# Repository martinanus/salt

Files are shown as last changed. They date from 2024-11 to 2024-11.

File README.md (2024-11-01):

# Proyecto SALT 

### Resumen
Este trabajo presenta el diseño e implementación de un prototipo para un sistema de aislado limitado total para formaciones ferroviarias (SAL/T) basado en un pliego de especificaciones de la empresa Trenes Argentinos Operaciones y en una primera versión del prototipo realizado anteriormente en el contexto del Grupo de Investigación en Calidad y Seguridad de las Aplicaciones Ferroviarias (GICSAFe). En esta versión, se agregan nuevas funcionalidades, se actualiza el hardware utilizado y se mejora la portabilidad de su firmware.     

Este sistema permite aumentar la seguridad de los trenes ante una falla en alguno de sus sistemas instrumentados de seguridad interfiriendo las señales de corte de tracción y freno de emergencia de la formación y aislando el subsistema en fallo. El SAL/T considera múltiples fuentes de medición de la velocidad de la formación y la comunicación con una central operativa para determinar cómo debe intervenir estas señales críticas para llevar a la formación a un estado seguro de manera controlada.

### Diagrama en bloques del SAL/T
diagrama_bloque

### Diseño del panel frontal del sistema
panel_frontal

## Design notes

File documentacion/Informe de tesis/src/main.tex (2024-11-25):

\documentclass[11pt,a4paper]{article}

\usepackage{graphicx}
\graphicspath{{Figuras/}}

\usepackage[utf8]{inputenc}
\usepackage[spanish,es-tabla]{babel}
\usepackage[left=2.5cm,right=2.5cm,bottom=2cm,top=2.5cm]{geometry}
\usepackage{titling}
\usepackage{bm}
\usepackage{multirow}
\usepackage{floatrow}
\newfloatcommand{capbtabbox}{table}[][\FBwidth]
\usepackage[table,xcdraw]{xcolor}

\usepackage{blindtext}
\usepackage{verbatim}
\usepackage{amsmath}
\usepackage{amssymb}
\usepackage{textcomp}
\usepackage{bbm}
\usepackage{multicol}
\usepackage{enumitem}
\usepackage{array}
\usepackage{booktabs}
\usepackage{placeins}
\usepackage[hidelinks]{hyperref}

\usepackage[separate-uncertainty = true]{siunitx}
\sisetup{output-decimal-marker = {,}, per-mode=fraction, exponent-product = \cdot}

% Renombre para titulo de referencias / bibliografía
\renewcommand\refname{}

% Bullets para las listas
\renewcommand{\labelitemi}{$\bullet$}
\makeatletter
\def\namedlabel#1#2{\begingroup
    #2%
    \def\@currentlabel{#2}%
    \phantomsection\label{#1}\endgroup}
\makeatother

% Numeración anidada con números
\renewcommand{\labelenumii}{\arabic{enumi}.\arabic{enumii}}
\renewcommand{\labelenumiii}{\arabic{enumi}.\arabic{enumii}.\arabic{enumiii}}
\renewcommand{\labelenumiv}{\arabic{enumi}.\arabic{enumii}.\arabic{enumiii}.\arabic{enumiv}}

\newcommand{\paralelo}{\mathbin{\!/\mkern-5mu/\!}}
\sisetup{exponent-product=\cdot, output-decimal-marker={,}, per-mode=symbol}

\usepackage{fancyhdr}
\usepackage[T1]{fontenc}
\pagestyle{fancy}
\fancyhf{}
\lhead{\textit{Sistema de Aislado Limitado / Total (SAL/T)}}
\rhead{\textit{UBA - Facultad de Ingeniería}}
\cfoot{\thepage}

\setlength{\headheight}{13.6pt}

% Figuras con numeración por sección, subsección o continuo
%\counterwithout{figure}{section}
\counterwithin{figure}{section}
%&\counterwithin{figure}{subsection}

\usepackage{changepage}
%%%%%%%%%%%%%%%%%%%%%%%%%%%%%%%%%%%%%%%%%%%

% Redefino tamaño de título de sección
\usepackage{titlesec}
\usepackage{lmodern}  % Load the Latin Modern font family for better font support
\titleformat{\section}[block]
  {\normalfont\bfseries\fontsize{20}{22}\selectfont} 
  {\thesection}{1em}{}

\titleformat{\subsection}[block]
  {\normalfont\bfseries\fontsize{14}{16}\selectfont}  
  {\thesubsection}{1em}{}

\titleformat{\subsubsection}[block]
  {\normalfont\bfseries\fontsize{12}{14}\selectfont}  
  {\thesubsubsection}{1em}{}

\begin{document}

\pagenumbering{gobble}
\DeclareSIUnit{\div}{div}
\DeclareSIUnit{\Sa}{Sa}

\begin{titlepage}	
	\centering

	%\vspace*{0.3cm}	

%     \Large{\textsc{Universidad de Buenos Aires}}\\ 
%	\Large{\textsc{Facultad de Ingeniería}}\\ 
%	\vspace*{1cm}	

	\begin{figure}[h]
		\centering
		 	
	\end{figure}
	\vspace*{2cm}

\huge{\textsc{86.00 Tesis de Ingeniería Electrónica - Informe de tesis\\}}\vspace{.3cm}
	
	\newcommand{\LargoDeBarra}{1}  % Ajustar
	
	\rule{\LargoDeBarra\linewidth}{0.3 mm} \\[0.1 cm]
	\LARGE{\textbf{Rediseño e implementación de un Sistema de Aislado Limitado / Total (SAL/T) para trenes}} \\[-0.3 cm]
	\rule{\LargoDeBarra\linewidth}{0.3 mm}

\vspace*{2cm}

    \begin{table}[htb]
%    \raggedright

    \begin{tabular}{lcc} 
        \textbf{Autor}              &     &     \\
        Anus, Martín     &    manus@fi.uba.ar & padron n° 101033   \\
        & & \\
         \textbf{Directores de tesis} &         &   \\
         Lutenberg, Ariel       & alutenb@fi.uba.ar & Director  \\
         Gomez, Pablo       & pgomez@fi.uba.ar   & Co-director \\
        Laiuppa, Adrián      & alaiuppa@frbb.utn.edu.ar & Co-director     \\
        & &  \\
         \textbf{Jurados}        & \\
         Cruz, Juan Manuel       & jcruz@fi.uba.ar   & \\
         Germino, Santiago        & sgermino@fi.uba.ar   & \\
         Menéndez, Martín        & mmenendez@fi.uba.ar   & 
        \end{tabular}
     \end{table}

\vspace*{1cm}

\textit{\large{Este trabajo fue realizado en la Ciudad Autónoma de Buenos Aires,}} \\
\textit{\large{entre agosto de 2023 y diciembre de 2024.}}

\end{titlepage}

\newpage
\input{0.1 - Resumen}
\newpage
\input{0.2 - Agradecimientos}

\newpage
\tableofcontents

\newpage
\listoffigures
\listoftables

% -------------------------------------------------------------------------------
\newpage
\setcounter{page}{1}
\pagenumbering{arabic}

\section{Introducción general}
\input{1 - Introducción general/1.0 - intro}
\input{1 - Introducción general/1.1 - Contexto y motivación}
\input{1 - Introducción general/1.2 - Objetivos y alcance}
\input{1 - Introducción general/1.3.1 - Requerimientos}
\input{1 - Introducción general/1.3.2 - Sistemas criticos}

\newpage
\section{Introducción específica}
\input{2 - Introducción específica/2.0 - intro}

\input{2 - Introducción específica/2.1 - intro}
\input{2 - Introducción específica/2.1.1 - Nucleo 144}
\input{2 - Introducción específica/2.1.2 - ESP32}
\input{2 - Introducción específica/2.1.3 - GPS GY-NEO6MV2}
\input{2 - Introducción específica/2.1.4 - SD}
\input{2 - Introducción específica/2.2.1 - MQTT}
\input{2 - Introducción específica/2.2.2 - WIFI}
\input{2 - Introducción específica/2.2.3 - GPS}
\input{2 - Introducción específica/2.2.4 - RS-485}
\input{2 - Introducción específica/2.3 - RTOS}

\newpage
\section{Diseño e implementación}
\input{3 - Diseño e implementación/3.0 - intro}
\input{3 - Diseño e implementación/3.1 - Descripción general de la solución}

\input{3 - Diseño e implementación/3.2.1 - Medición SIS}
\input{3 - Diseño e implementación/3.2.2 - Aislamiento SIS}
\input{3 - Diseño e implementación/3.2.3 - Control de señales críticas}
\input{3 - Diseño e implementación/3.2.4 - Registrador de eventos y conetor de zona}
\input{3 - Diseño e implementación/3.2.5 - Llaves de activación modo aislado limitado y total}
\input{3 - Diseño e implementación/3.2.6 - Lectura de velocidad por RS485}
\input{3 - Diseño e implementación/3.2.7 - Módulo GPS}
\input{3 - Diseño e implementación/3.2.8 - ESP32 y USB}
\input{3 - Diseño e implementación/3.2.9 - Tarjeta SD}
\input{3 - Diseño e implementación/3.2.10 - Nucleo144}
\input{3 - Diseño e implementación/3.2.11 - Panel frontal}
\input{3 - Diseño e implementación/3.2.12 - Fabricación y ensamblado}
\input{3 - Diseño e implementación/3.2.13 - Gabinete}

\input{3 - Diseño e implementación/3.3.1 - Lógica general}
\input{3 - Diseño e implementación/3.3.2 - Mecanismos de RTOS}
\input{3 - Diseño e implementación/3.3.3 - Medición SIS}
\input{3 - Diseño e implementación/3.3.4 - Comunicación GPS}
\input{3 - Diseño e implementación/3.3.5 - Velocidades rs485}
\input{3 - Diseño e implementación/3.3.6 - Comunicacion con centrl operativa}
\input{3 - Diseño e implementación/3.3.7- Lógica de control modo limitado e intermitente}
\input{3 - Diseño e implementación/3.3.8 - Comunicación con controlador LED}
\input{3 - Diseño e implementación/3.3.9 - Registro de eventos}

\newpage
\section{Ensayos y resultados}
\input{4 - Ensayos y resultados/4.0 - intro}
\input{4 - Ensayos y resultados/4.1 - Banco de pruebas}
\input{4 - Ensayos y resultados/4.2 - Pruebas de hardware}
\input{4 - Ensayos y resultados/4.3 - Pruebas de firmware}
\input{4 - Ensayos y resultados/4.4 - Pruebas integrales}

\newpage
\section{Conclusiones}
\input{5 - Conclusiones/5.0 - intro}
\input{5 - Conclusiones/5.1 - Conclusiones generales}
\input{5 - Conclusiones/5.2 - Próximos pasos}

\newpage
\input{6 - Bibliografia}

\end{document}

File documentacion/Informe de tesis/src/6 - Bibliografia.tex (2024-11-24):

\section{Bibliografía}

 \begin{thebibliography}{30}

 \bibitem{gicsafe}
 \textbf{GICSAFe}. Grupo de Investigación en Calidad y Seguridad de las Aplicaciones Ferroviarias. \href{https://sites.google.com/view/conicet-gicsafe}{https://sites.google.com/view/conicet-gicsafe}.

  \bibitem{salt_paper}
 \textbf{Supervision system for emergency brake and traction-system isolation on train formations}. Di Vito Iván Mariano, Gomez Pablo Martin, Lutenberg Ariel, 2020. \href{https://ieeexplore.ieee.org/document/9085280}{\textit{https://ieeexplore.ieee.org/document/9085280}}.

 \bibitem{trenes_arg}
 \textbf{Trenes Argentinos} Trenes Argentinos Operaciones, empresa del estado. \href{https://www.argentina.gob.ar/transporte/trenes-argentinos}{https://www.argentina.gob.ar/transporte/trenes-argentinos}.

\bibitem{salt_ivan}
 \textbf{Aplicación de la técnica de patrones de diseño a la implementación de un Sistema de Aislamiento Limitado/Total ferroviario}. Di Vito, Iván Mariano. 2019 \href{https://bibliotecadigital.fi.uba.ar/items/show/18446}{\textit{https://bibliotecadigital.fi.uba.ar/items/show/18446}}.

\bibitem{norma_50126}
\textbf{UNE-EN 50126-1}. Aplicaciones ferroviarias. Especificación y demostración de la fiabilidad, la disponibilidad, la mantenibilidad y la seguridad (RAMS). 2005. \href{https://www.une.org/encuentra-tu-norma/busca-tu-norma/norma?c=N0033106}{https://www.une.org/encuentra-tu-norma/busca-tu-norma/norma?c=N0033106}

 \bibitem{patrones}
 \textbf{Design Patterns for Safety-Critical Embedded Systems}. Ashraf Armoush. RWTH Aachen University. 2010.

 \bibitem{salt_case}
 \textbf{Sistema de supervisión de la seguridad del material ferroviario utilizando patrones de diseño}. Ivan Mariano Di Vito, Pablo Gomez, Ariel Lutenberg, Adrian Laiuppa. 2019. \href{https://drive.google.com/file/d/1FDtRL4We4daZ7XrJ81sL2f6HrZbYlOuG/view}{\textit{https://drive.google.com/file/d/1FDtRL4We4daZ7XrJ81sL2f6HrZbYlOuG/view}}. 

 \bibitem{spec}
 \textbf{SISTEMA DE AISLADO LIMITADO / TOTAL (SAL-T)}. ESPECIFICACIÓN TÉCNICA. Bypass Sistemas Instrumentados de Seguridad a Bordo del Material Rodante ET.SO. No 046 /18 – E3. 2022.

\bibitem{norma_ipc2221}
\textbf{IPC-2221}. Estándar genérico sobre la PCB. Revisión C; 2023. \href{https://shop.ipc.org/ipc-2221/ipc-2221-standard-only/Revision-c/english}{https://shop.ipc.org/ipc-2221/ipc-2221-standard-only/Revision-c/english}

\bibitem{norma_50128}
\textbf{UNE-EN 50128}. Aplicaciones ferroviarias. Sistemas de comunicación, señalización y procesamiento. Software para sistemas de control y protección del ferrocarril. 2012. \href{https://www.une.org/encuentra-tu-norma/busca-tu-norma/norma?c=N0049040}{https://www.une.org/encuentra-tu-norma/busca-tu-norma/norma?c=N0049040} 

\bibitem{norma_61508}
\textbf{UNE-EN 61508-4}. Seguridad funcional de los sistemas eléctricos/electrónicos/electrónicos programables relacionados con la seguridad. Parte 4: Definiciones y abreviaturas. 2011. \href{https://www.une.org/encuentra-tu-norma/busca-tu-norma/norma?c=N0047025}{https://www.une.org/encuentra-tu-norma/busca-tu-norma/norma?c=N0047025} 

\bibitem{norma_50129}
\textbf{UNE-EN 50129}. Aplicaciones ferroviarias. Sistemas de comunicación, señalización y procesamiento. Sistemas electrónicos relacionados con la seguridad para la señalización. 2020. \href{https://www.une.org/encuentra-tu-norma/busca-tu-norma/norma?c=N0063513}{https://www.une.org/encuentra-tu-norma/busca-tu-norma/norma?c=N0063513} 

\bibitem{clasificacion_fallas}
\textbf{Random, systematic, and common cause failure: How do you manage them?}. Michela Gentile, Angela E. Summers. 2006. \href{https://sis-tech.com/wp-content/uploads/2005/10/Random_Systematic_and_Common_Cause_Failure.pdf}{https://sis-tech.com/wp-content/uploads/2005/10/Random\_Systematic\_and\_Common\_Cause\_Failure.pdf} 

 \bibitem{nucleo144}
\textbf{STM32 Nucleo-144 development board with STM32F429ZI MCU}. STMicroelectronics. \href{https://www.st.com/en/evaluation-tools/nucleo-f429zi.html}{https://www.st.com/en/evaluation-tools/nucleo-f429zi.html} 

\bibitem{stm32f429zi}
\textbf{STM32F429ZI}. High-performance advanced line, Arm Cortex-M4 core. STMicroelectronics. \href{https://www.st.com/en/microcontrollers-microprocessors/stm32f429zi.html}{https://www.st.com/en/microcontrollers-microprocessors/stm32f429zi.html} 

\bibitem{st_link}
\textbf{ST-LINK/V2-1}. In-Circuit Debugger and Programmer. STMicroelectronics.
\href{https://www.st.com/en/development-tools/st-link-v2.html}{https://www.st.com/en/development-tools/st-link-v2.html}

\bibitem{stCubeIde}
\textbf{STM32CubeIDE}. Free Development Environment for STM32 Microcontrollers. STMicroelectronics.
\href{https://www.st.com/en/development-tools/stm32cubeide.html}{https://www.st.com/en/development-tools/stm32cubeide.html}

\bibitem{stCubeMx}
\textbf{STM32CubeMX}. Initialization Code Generator for STM32 Microcontrollers. STMicroelectronics.
\href{https://www.st.com/en/development-tools/stm32cubemx.html}{https://www.st.com/en/development-tools/stm32cubemx.html}

\bibitem{esp32}
\textbf{ESP32-DevKitC}. Development board from Espressif.  \href{https://docs.espressif.com/projects/esp-dev-kits/en/latest/esp32/esp32-devkitc/index.html}{https://docs.espressif.com/projects/esp-dev-kits/en/latest/esp32/esp32-devkitc/index.html} 

\bibitem{ieee_802.11}
\textbf{IEEE 802.11}. IEEE Computer Society, IEEE Standard for Information Technology—Telecommunications and Information Exchange Between Systems Local and Metropolitan Area Networks—Specific Requirements Part 11: Wireless LAN Medium Access Control (MAC) and Physical Layer (PHY) Specifications, IEEE Standard 802.11-2020, 2021. \href{https://standards.ieee.org/standard/802_11-2020.html}{https://standards.ieee.org/standard/802\_11-2020.html}

\bibitem{bluetooth}
\textbf{Bluetooth}. Bluetooth Core Specification Version 5.4. 2023. \href{https://www.bluetooth.com/specifications/bluetooth-core-specification/}{https://www.bluetooth.com/specifications/bluetooth-core-specification/}

\bibitem{arduino_ide}
\textbf{Arduino IDE}. Open source repository.  \href{https://github.com/arduino/arduino-ide}{https://github.com/arduino/arduino-ide}

\bibitem{esp_ids}
\textbf{ESP-IDS}. Espressif IoT Development Framework.\href{https://idf.espressif.com/}{https://idf.espressif.com/}

\bibitem{platformio}
\textbf{PlatformIO}. Cross-platform, cross-architecture, multiple framework, professional tool for embedded systems designers. \href{https://platformio.org/}{https://platformio.org/}

\bibitem{gy-neo6}
\textbf{Modulo GPS GY-NEO6MV2}. Módulo basado en NEO-6M. \href{https://www.todomicro.com.ar/ARDUINO/339-modulo-gps-gy-neo6mv2-con-antena.html}{https://www.todomicro.com.ar/ARDUINO/339-modulo-gps-gy-neo6mv2-con-antena.html}

\bibitem{neo6}
\textbf{NEO-6M}. Módulo GNSS / GPS. Ublox. \href{https://www.u-blox.com/en/product/neo-6-series}{https://www.u-blox.com/en/product/neo-6-series}

\bibitem{mqtt_ibm}
\textbf{Getting to know MQTT}. Michael Yuan. 2021. \href{https://developer.ibm.com/articles/iot-mqtt-why-good-for-iot/}{https://developer.ibm.com/articles/iot-mqtt-why-good-for-iot/}

\bibitem{mqtt_img}
\textbf{What is MQTT}. Tobias Goebel
Twilion. 2023. \href{https://www.twilio.com/en-us/blog/what-is-mqtt}{https://www.twilio.com/en-us/blog/what-is-mqtt}

\bibitem{wifi_img}
\textbf{Wi-Fi Direct}. Wikipedia. \href{https://en.wikipedia.org/wiki/Wi-Fi_Direct}{https://en.wikipedia.org/wiki/Wi-Fi\_Direct}

\bibitem{wifi_security}
\textbf{Wi-Fi Security}. Wi-Fi Alliance, Wi-Fi Security Technologies: WEP, WPA, and WPA2. \href{https://www.wi-fi.org/discover-wi-fi/security}{https://www.wi-fi.org/discover-wi-fi/security}

\bibitem{gps}
\textbf{GPS}. U.S. Department of Defense, Global Positioning System Standard Positioning Service Performance Standard, 4th ed. 2008. \href{https://www.gps.gov/technical/ps/}{https://www.gps.gov/technical/ps/}

\bibitem{gps_img}
\textbf{Cómo funcionan los dispositivos GPS? Trilateración vs Triangulación}.Gabri. Arcgeek. 2018.  \href{https://acolita.com/como-funcionan-los-dispositivos-gps-trilateracion-vs-triangulacion/}{https://acolita.com/como-funcionan-los-dispositivos-gps-trilateracion-vs-triangulacion/}

\bibitem{rs485}
\textbf{Texas Instruments, RS-485}: Theory and Application, Application Report SLAA070D. 2004. \href{https://www.ti.com/lit/an/slaa070d/slaa070d.pdf}{https://www.ti.com/lit/an/slaa070d/slaa070d.pdf}

\bibitem{rtos}
\textbf{What is a Real-Time Operating System (RTOS)?} Digikey article. 2021. \href{https://www.digikey.com/en/maker/projects/what-is-a-realtime-operating-system-rtos/28d8087f53844decafa5000d89608016}{https://www.digikey.com/en/maker/projects/what-is-a-realtime-operating-system-rtos/28d8087f53844decafa5000d89608016}

\bibitem{hasler}
\textbf{Hasler Rail}. Speed Sensing and Odometry. 2016
\href{https://www.haslerrail.com/wp-content/uploads/2019/03/HaslerRail_DataRecordingSafety_EN_v1.pdf}{https://www.haslerrail.com/wp-content/uploads/2019/03/HaslerRail\_DataRecordingSafety\_EN\_v1.pdf}

\bibitem{mouser}
\textbf{Mouser Electronics}.  Global distributor of semiconductors and electronic components. \href{https://www.mouser.com/}{https://www.mouser.com/}

\bibitem{digikey}
\textbf{DigiKey Corporation}. Global distributor of semiconductors and electronic components. \href{https://www.digikey.com/}{https://www.digikey.com/}

\bibitem{kicad}
\textbf{KiCad EDA}. Version 6. KiCad Developers.
\href{https://www.kicad.org/}{https://www.kicad.org/}

\bibitem{LTspice}
\textbf{LTSpice.} Free SPICE simulator. Analog devices.
\href{https://www.analog.com/en/resources/design-tools-and-calculators/ltspice-simulator.html}{https://www.analog.com/en/resources/design-tools-and-calculators/ltspice-simulator.html}

\bibitem{github}
\textbf{GitHub, Inc.}. A Platform for Version Control and Collaboration,
\href{https://github.com}{https://github.com}

\bibitem{git}
\textbf{Git} A Distributed Version Control System. Linus Torvalds. 2005.
\href{https://git-scm.com}{https://git-scm.com}

\bibitem{repo}
\textbf{martinanus/salt} Repositorio de firmware y hardware del proyecto. Martín Anús. 2024. \href{https://github.com/martinanus/salt}{https://github.com/martinanus/salt}

\bibitem{INA823DGKR}
\textbf{INA823DGKR}. Texas Instruments. Instrumentation Amplifiers Precision. 
\href{https://www.ti.com/lit/gpn/ina823}{https://www.ti.com/lit/gpn/ina823}

\bibitem{ICL7660AIBAZA}
\textbf{ICL7660AIBAZA}. Renesas. Switching Voltage Regulators. 
\href{https://ar.mouser.com/datasheet/2/698/REN_icl7660s_a_DST_20200210-1997724.pdf}{https://ar.mouser.com/datasheet/2/698/REN\_icl7660s\_a\_DST\_20200210-1997724.pdf}

\bibitem{JW2SN-DC5V}
\textbf{JW2SN-DC5V}. Panasonic Industrial Devices. General Purpose Relays 5A 5VDC DPDT SEALED PCB. 
\href{https://ar.mouser.com/manufacturer/panasonic-industrial-devices/}{https://ar.mouser.com/manufacturer/panasonic-industrial-devices/}

\bibitem{V23047A1005A501}
\textbf{V23047A1005A501}. TE Connectivity. Safety Relays 2 CO CONTACTS 5VDC
\href{https://ar.mouser.com/datasheet/2/418/6/ENG_DS_SR2M_0820-735797.pdf}{https://ar.mouser.com/datasheet/2/418/6/ENG\_DS\_SR2M\_0820-735797.pdf}

\bibitem{norma_61810}
\textbf{UNE-EN 61810-3}. Relés electromecánicos elementales. Parte 3: Relés con contactos guiados (unidos mecánicamente). 2015. 
\href{https://www.une.org/encuentra-tu-norma/busca-tu-norma/norma?c=N0054926}{https://www.une.org/encuentra-tu-norma/busca-tu-norma/norma?c=N0054926}

\bibitem{rele_img}
\textbf{Relay Terminology}. Altech Corp.
\href{https://oylair.com/wp-content/uploads/2021/03/resources-library-3-relay-terminology.pdf}{https://oylair.com/wp-content/uploads/2021/03/resources-library-3-relay-terminology.pdf}

\bibitem{ULN2003D1013TR}
\textbf{ULN2003D1013TR}- STMicroelectronics. Darlington Transistors Seven NPN Array.
\href{https://ar.mouser.com/datasheet/2/389/uln2001-1852702.pdf}{https://ar.mouser.com/datasheet/2/389/uln2001-1852702.pdf}

\bibitem{darlington}
\textbf{Darlington’s Contributions to Transistor Circuit Design} David A. Hodges, Fellow, IEEE. 1999.
\href{https://people.eecs.berkeley.edu/~hodges/DarlingtonCircuit.pdf}{https://people.eecs.berkeley.edu/~hodges/DarlingtonCircuit.pdf}

\bibitem{registrador_eventos}
\textbf{Use of Event Data Recorders in Rail Transit}. Federal Transit Administration, , FTA Report No. 0123. 2015.
\href{https://www.transit.dot.gov/research-innovation/use-event-data-recorders-rail-transit}{https://www.transit.dot.gov/research-innovation/use-event-data-recorders-rail-transit}

\bibitem{llave_elibet}
\textbf{Interruptor Bipolar 20A de 2 posiciones}. Elibet. Serie LI. 
\href{https://www.elibet.com/wp-content/uploads/2014/08/Elibet-20A.pdf}{https://www.elibet.com/wp-content/uploads/2014/08/Elibet-20A.pdf}

\bibitem{indicador_velocidad}
\textbf{Data Recording and Safety}. Hasler Rail. \href{http://www.iotrains.com/fileadmin/user_upload/04_DataRecording.pdf}{http://www.iotrains.com/fileadmin/ user\_upload/04\_DataRecording.pdf}

\bibitem{crc}
\textbf{Catalogue of parametrised CRC algorithms with 16 bits}. Greg Cook. 
\href{http://reveng.sourceforge.net/crc-catalogue/16.htm}{http://reveng.sourceforge.net/crc-catalogue/16.htm}

\bibitem{edu-ciaa}
\textbf{EDU-CIAA-NXP}. Información general de la placa de desarrollo EDU-CIAA-NXP desarrollada por el proyecto CIAA (Computadora Industrial Abierta Argentina). \href{https://www.proyecto-ciaa.com.ar/devwiki/doku.php%3Fid=desarrollo:edu-ciaa:edu-ciaa-nxp.html}{https://www.proyecto-ciaa.com.ar/devwiki/doku.php\%3Fid=desarrollo:edu-ciaa:edu-ciaa-nxp.html}

\bibitem{SN65HVD1176DR}
\textbf{SN65HVD1176DR}. Texas Instruments. CI interfaz RS-485 PROFIBUS RS-485 Transceiver. 
\href{https://www.ti.com/lit/gpn/sn65hvd1176}{https://www.ti.com/lit/gpn/sn65hvd1176}

\bibitem{profibus}
\textbf{Profibus International}. PROFIBUS Technology Overview.
\href{https://www.profibus.com/technologies/profibus}{https://www.profibus.com/technologies/profibus}

\bibitem{SZP6SMB12CAT3G}
\textbf{SZP6SMB12CAT3G}. Littelfuse. ESD Protection Diodes / TVS Diodes.
\href{https://www.littelfuse.com/media?itemid=a54ab340-efe4-40d7-99cb-dd80d69f6f3a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}{https://www.littelfuse.com/media?resourcetype=datasheets\&itemid=a54ab340-efe4-40d7-99cb-dd80d69f6f3a\&filename=littelfuse\_tvs\_diode\_szp6smb\_datasheet.pdf}

\bibitem{MF-USMF020-2}
\textbf{MF-USMF020-2}. Bourns. Resettable Fuses.
\href{https://www.mouser.co.uk/datasheet/2/54/mfusmf-777646.pdf}{https://www.mouser.co.uk/datasheet/2/54/mfusmf-777646.pdf}

\bibitem{SI2343DS-T1-E3}
\textbf{SI2343DS-T1-E3}. Vishay Semiconductors. MOSFETs 30V 4.0A 1.25W 53 mohms @ 10V. 
\href{https://www.vishay.com/doc?72079}{https://www.vishay.com/doc?72079}

\bibitem{altanet}
\textbf{Módem router Portátil USB 4G LTE Wi-Fi}. Altanet.
\href{https://www.voipexperts.com.ar/productos/routers/routers-4g/alta-stick-st10.html}{https://www.voipexperts.com.ar/productos/routers/routers-4g/alta-stick-st10.html}

\bibitem{87583-2010BLF}
\textbf{87583-2010BLF}. Amphenol FCI. USB Connectors 4P RECEPTACLE TYPE A.
\href{https://www.mouser.co.uk/datasheet/2/18/1/87583-2579162.pdf}{https://www.mouser.co.uk/datasheet/2/18/1/87583-2579162.pdf}

\bibitem{DM3AT-SF-PEJM5}
\textbf{DM3AT-SF-PEJM5}. Hirose Connector. Memory Card Connectors R/A SMT MICROSD CON PUSH-PUSH.
\href{https://www.mouser.co.uk/datasheet/2/185/DM3AT_SF_PEJM5_CL0609_0031_0_00_2DDrawing_00009471-1614303.pdf}{https://www.mouser.co.uk/datasheet/2/185/ DM3AT\_SF\_PEJM5\_CL0609\_0031\_0\_00\_2DDrawing\_00009471-1614303.pdf}

\bibitem{sd_sandisk}
\textbf{Micro SD Ultra 8GB Class 10}. SanDisk.
\href{https://dcpsoltec.mercadoshops.com.ar/MLA-1346308183-micro-sd-sandisk-ultra-8gb-clase-10-_JM}{https://dcpsoltec.mercadoshops.com.ar/MLA-1346308183-micro-sd-sandisk-ultra-8gb-clase-10-\_JM}

\bibitem{AS1115-BSST}
\textbf{AS1115-BSST}. ams OSRAM. LED Display Drivers LED Driver with Keyscan.
\href{https://www.mouser.co.uk/datasheet/2/588/asset_pdf_25493045-3432722.pdf}{https://www.mouser.co.uk/datasheet/2/588/asset\_pdf\_25493045-3432722.pdf}

\bibitem{WP154A4SEJ3VBDZGW/CA}
\textbf{WP154A4SEJ3VBDZGW/CA}. Kingbright. Standard LEDs - Through Hole 5MM RGB LED.
\href{https://www.mouser.co.uk/datasheet/2/216/WP154A4SEJ3VBDZGW_CA-1145236.pdf}{https://www.mouser.co.uk/datasheet/2/216/WP154A4SEJ3VBDZGW\_CA-1145236.pdf}

\bibitem{WP7113LZGCK}
\textbf{WP7113LZGCK}. Kingbright. Standard LEDs - Through Hole 5MM LOW CURRENT GREEN LED.
\href{https://www.mouser.co.uk/datasheet/2/216/WP7113LZGCK-535810.pdf}{https://www.mouser.co.uk/datasheet/2/216/WP7113LZGCK-535810.pdf}

\bibitem{LTC-5723HR}
\textbf{LTC-5723HR}. Lite-On. LED Displays and Accessories 4 Digit, Red. 
\href{https://www.mouser.co.uk/datasheet/2/239/C5723HR-1141844.pdf}{https://www.mouser.co.uk/datasheet/2/239/C5723HR-1141844.pdf}

\bibitem{1543-650-149}
\textbf{1543-650-149}. Bourns. Pushbutton Switches Push Switch.
\href{https://www.mouser.co.uk/datasheet/2/54/1543-55078.pdf}{https://www.mouser.co.uk/datasheet/2/54/1543-55078.pdf}

\bibitem{CEM-1205-IC}
\textbf{CEM-1205-IC}. Same Sky.Piezo Buzzers and Audio Indicators buzzer 5V, driving circuit.
\href{https://www.mouser.co.uk/datasheet/2/1628/cem_1205_ic-3509057.pdf}{https://www.mouser.co.uk/datasheet/2/1628/cem\_1205\_ic-3509057.pdf}

\bibitem{NVTR0202PLT1G}
\textbf{NVTR0202PLT1G}. onsemi. MOSFETs PFET 20V 0.4A 80MOH.
\href{https://www.mouser.co.uk/datasheet/2/308/1/NTR0202PL_D-2319410.pdf}{https://www.mouser.co.uk/datasheet/2/308/1/NTR0202PL\_D-2319410.pdf}

\bibitem{jlcway}
\textbf{JLCWAY}.PCB Manufacturing and Assembly Services.
\href{https://jlcpcb.com}{https://jlcpcb.com}

\bibitem{labi_3d}
\textbf{Impresiones 3D}. Laboratorio Abierto de la Facultad de Ingeniería de la Universidad de Buenos Aires.
\href{https://labi.fi.uba.ar/impresiones-3d}{https://labi.fi.uba.ar/impresiones-3d}

\bibitem{gabinete}
\textbf{Caja estanca plástica 310x310x110 Blanca IP65}. Sistelectric de Genros.
\href{https://sistelectric.com/producto/06313111g/caja-estanca-plastica-310x310x110-gris-ip65/}{https://sistelectric.com/producto/06313111g/caja-estanca-plastica-310x310x110-gris-ip65/}

\bibitem{freertos}
\textbf{FreeRTOS}. Real-Time Operating System for Embedded Devices.
\href{https://www.freertos.org}{https://www.freertos.org}

\bibitem{nmea}
\textbf{GPS - NMEA sentence information}. Glenn Baddeley. 2001.
\href{https://aprs.gids.nl/nmea/}{https://aprs.gids.nl/nmea/}

\bibitem{ntp}
\textbf{NTP Server} The NTP Pool Project
\href{https://www.pool.ntp.org}{https://www.pool.ntp.org}

\bibitem{arduino_uno}
\textbf{Arduino}. Arduino Uno Rev3.
\href{https://docs.arduino.cc/hardware/uno-rev3/}{https://docs.arduino.cc/hardware/uno-rev3/}

\bibitem{conversor_rs485}
\textbf{Modulo Conversor Rs485 Ttl Max485 Transceiver}. Hobbytronica. 
\href{https://www.hobbytronica.com.ar/MLA-1412581125-x5-modulo-conversor-rs485-ttl-max485-transceiver-arduino-_JM}{https://www.hobbytronica.com.ar/MLA-1412581125-x5-modulo-conversor-rs485-ttl-max485-transceiver-arduino-\_JM}

\bibitem{atmega328}
\textbf{ATMega328-p}. 8-bit AVR Microcontroller. Microchip Technology Inc. 
\href{https://www.microchip.com/wwwproducts/en/ATmega328p}{https://www.microchip.com/wwwproducts/en/ATmega328p}

\bibitem{swSerial}
\textbf{Software Serial Library}. Arduino. 
\href{https://docs.arduino.cc/learn/built-in-libraries/software-serial/}{https://docs.arduino.cc/learn/built-in-libraries/software-serial/}

\bibitem{hobbytronica}
\textbf{Hobbytrónica}. Casa de electrónica y robótica. 
\href{https://docs.arduino.cc/learn/built-in-libraries/software-serial/}{https://www.hobbytronica.com.ar/}

\bibitem{max485}
\textbf{MAX485}. Low-Power, Slew-Rate-Limited RS-485/RS-422 Transceivers. Analog devices.
\href{https://www.analog.com/en/products/max485.html}{https://www.analog.com/en/products/max485.html}

\bibitem{shifrio}
\textbf{shiftr.io}. MQTT Broker and Dataflow Visualizer
\href{https://www.shiftr.io}{https://www.shiftr.io}

\bibitem{paho}
\textbf{Paho MQTT Python Client Library}. Eclipse Foundation. 
\href{https://eclipse.dev/paho/}{https://eclipse.dev/paho/}

\bibitem{modulo_sd}
\textbf{Modulo lector de tarjetas SD}. Electrouno. 
\href{https://www.unoelectro.com.ar/MLA-864661170-modulo-lector-de-tarjetas-micro-sd-arduino-unoelectro-_JM}{https://www.unoelectro.com.ar/MLA-864661170-modulo-lector-de-tarjetas-micro-sd-arduino-unoelectro-\_JM}

 \end{thebibliography}

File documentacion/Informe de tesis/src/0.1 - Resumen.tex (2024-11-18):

\vspace*{\fill}

\begin{center}

{\huge \textit{Resumen}}

\vspace{1.5cm}

\begin{adjustwidth}{2cm}{2cm}
\begin{center}

Este trabajo presenta el diseño e implementación de un prototipo para un sistema de aislado limitado total para formaciones ferroviarias (SAL/T) basado en un pliego de especificaciones de la empresa Trenes Argentinos Operaciones y en una primera versión del prototipo realizado anteriormente en el contexto del Grupo de Investigación en Calidad y Seguridad de las Aplicaciones Ferroviarias (GICSAFe). En esta versión, se agregan nuevas funcionalidades, se actualiza el hardware utilizado y se mejora la portabilidad de su firmware. \\

\vspace{.8cm}

Este sistema permite aumentar la seguridad de los trenes ante una falla en alguno de sus sistemas instrumentados de seguridad interfiriendo las señales de corte de tracción y freno de emergencia de la formación y aislando el subsistema en fallo. El SAL/T considera múltiples fuentes de medición de la velocidad de la formación y la comunicación con una central operativa para determinar cómo debe intervenir estas señales críticas para llevar a la formación a un estado seguro de manera controlada.  \\ 

\vspace{.8cm}

A lo largo del proyecto, se aplicaron conocimientos de diseño de circuitos, diseño de placas impresas, utilización de protocolos de comunicación e implementación de firmware basado en sistemas operativos en tiempo real.

\end{center}
\end{adjustwidth}

\end{center}

\vspace{8cm}

\vspace*{\fill}

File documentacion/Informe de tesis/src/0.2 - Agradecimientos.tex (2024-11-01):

\vspace*{\fill}

\begin{center}

{\huge \textit{Agradecimientos}}

\vspace{1.3cm}

\begin{adjustwidth}{2cm}{2cm}
\begin{center}
        
Quiero expresar mi agradecimiento a los directores de esta tesis; Ariel, Pablo y Adrián por su constante apoyo, motivación, ayuda y guía que me brindaron a lo largo de este proyecto. \\ 
\vspace{.7cm}

Al grupo de investigación GICSAFe que me introdujo en el mundo de los sistemas ferroviarios y me abrió la posibilidad de desarrollar este trabajo sobre las sólidas bases de conocimiento del grupo.

\vspace{.7cm}

A las personas de la empresa Trenes Argentinos que dedicaron su tiempo para definir el objetivo y el alcance de este proyecto. 

\vspace{.7cm}

Al ingeniero Iván Di Vito por dejar una versión anterior de este sistema de una calidad enorme.

\vspace{.7cm}

A todos los docentes que tuve a lo largo de mi vida por formarme como profesional y como persona. 

\vspace{.7cm}

Al arquitecto Martín Mendilaharzu por la ayuda en el diseño y fabricación del gabinete. 

\vspace{.7cm}

A Carlos, mi papá, por mostrarme la ingeniería en todos los detalles de la vida y contagiarme su pasión.

\vspace{.7cm}

A Sandra, mi mamá, por su amor incondicional e infinito.

\vspace{.7cm}

A Federico, mi hermano, por su complicidad y acompañamiento en este camino.

\vspace{.7cm}

Y por último, pero no menor, agradecerle a todos mis amigos; por estar siempre presentes a mi lado y darle sentido a todo. 

\end{center}
\end{adjustwidth}

\end{center}

\vspace{2.8cm}

\vspace*{\fill}

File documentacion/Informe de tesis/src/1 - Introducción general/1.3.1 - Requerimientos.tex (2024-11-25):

\subsection{Requerimientos y visión general}

\subsubsection{Requerimientos}

A continuación, se muestran los requerimientos acordados para el proyecto contemplando la versión anterior del SAL/T y el pliego de especificaciones técnicas generado por Trenes Argentinos como referencia. 

\begin{enumerate}
    \item Grupo de requerimientos asociados con la interfaz humano-máquina
    \begin{enumerate}
        \item La interfaz debe contar con una llave rotativa para activar el modo aislado limitado.
        \item La interfaz debe mostrar la velocidad media del equipo en km/h con 4 dígitos.
        \item La interfaz debe indicar el estado de la señal de corte de tracción.
        \item La interfaz debe indicar el estado de la señal de freno de emergencia.
        \item La interfaz debe indicar la presencia de un comando remoto de la central operativa.
        \item La interfaz debe indicar el estado del módulo GPS.
        \item La interfaz debe indicar el estado de la alimentación.
        \item La interfaz debe indicar el modo en el que se encuentra el sistema.
        \item La interfaz debe contener un control local por fuera del panel frontal para activar el modo aislado total.
        \item La interfaz debe indicar con un LED RGB en cuál de las 3 zonas geográficas predefinidas se encuentra el material rodante. 
        \item La interfaz debe indicar el estado de los distintos Sistemas Instrumentados de Seguridad conectados al SAL/T con un LED RGB para cada SIS.
        \item La interfaz debe contar con una botonera o switch que permita cambiar el perfil para modo de tracción intermitente.
        \item La interfaz debe indicar el perfil seleccionado para modo de tracción intermitente.
        \item La interfaz debe contener un buzzer interno para indicaciones sonoras.
    \end{enumerate}
       
    \item Grupo de requerimientos asociados a la comunicación con el registrador de eventos
    \begin{enumerate}
        \item El sistema debe informar al registrador de eventos la activación del modo aislado limitado.
        \item El sistema debe informar al registrador de eventos si la alimentación es correcta.
        \item El sistema debe informar al registrador de eventos la activación del freno de emergencia.
        \item El sistema debe informar al registrador de eventos la activación del corte de tracción.
    \end{enumerate}
       
    \item Grupo de requerimientos asociados al registro de datos
    \begin{enumerate}
        \item El sistema debe mantener un registro de datos local donde se registran los siguientes eventos con marca de tiempo:
        \begin{itemize}
            \item Activación/Desactivación del modo aislado limitado
            \item Activación/Desactivación del modo aislado total (local o remota)
            \item Referencia de velocidad adoptada y sus permutaciones 
            \item Cobertura de señal GPS
            \item Ciclos de permiso, corte y freno en modo de tracción intermitente
            \item SIS en fallo
            \item Velocidad desarrollada
            \item Zona de circulación
        \end{itemize}
        \item El sistema debe permitir descargar los datos registrados mediante una interfaz serie.
        \item El sistema debe poder descargar los datos registrados de manera remota.
    \end{enumerate}
       
    \item Grupo de requerimientos asociados a la comunicación con la central operativa
    \begin{enumerate}
        \item El sistema debe informar periódicamente (con un tiempo configurable) su estado a la central operativa a través de la red de datos Wi-Fi.
        \item Debe existir la posibilidad de usar 2 proveedores distintos de datos de manera simultánea.
        \item Debe existir la posibilidad de conectarse alternadamente a más de una red Wi-Fi.
        \item El protocolo de comunicación con la central operativa debe ser MQTT.
        \item El sistema debe ser capaz de recibir un comando remoto que anule el corte de tracción y el freno de emergencia bajo cualquier condición (modo aislado total).
        \item El sistema debe ser capaz de recibir un comando remoto que active el corte de tracción y el freno de emergencia bajo cualquier condición (modo parada total).
        \item El sistema debe ser capaz de recibir un comando remoto que active el corte de tracción y anule el freno de emergencia bajo cualquier condición (modo coche en deriva).
        \item El sistema debe ser capaz de recibir un comando remoto que active el corte de tracción y el freno de emergencia de forma intermitente en ciclos de tiempo configurables (modo intermitente).
        \item El sistema debe ser capaz de recibir un comando remoto que cancele cualquier comando remoto vigente.
        \item El sistema debe ser capaz de recibir comandos remotos que modifiquen sus parámetros internos configurables.
        \item Si no se recibe un nuevo comando remoto luego de un tiempo configurable (por defecto 10 segundos, máximo 1 minuto), debe volver al algoritmo de activación de corte de tracción y freno de emergencia por defecto.
        \item Ante un comando remoto recibido, debe enviar una confirmación de recepción que permita a la central operativa decidir si es necesaria o no una retransmisión.
        \item Debe utilizar algún mecanismo de encriptación para el enlace con la central operativa.
    \end{enumerate}
       
    \item Grupo de requerimientos asociados al modo normal de funcionamiento
    \begin{enumerate}
        \item El modo normal el sistema no debe intervenir en el funcionamiento del material rodante (prioridad alta).
        \item El sistema debe obtener en todo momento la mejor estimación posible de la velocidad de la formación.
        \item Debe ser capaz de recibir la velocidad a partir de una señal digital provista por el registrador de eventos Hasler Teloc 1500.
        \item Debe ser capaz de calcular la velocidad a partir de un sistema GPS integrado.
        \item Debe ser capaz de calcular la velocidad a partir de un generador de impulsos.
        \item El rango de velocidad soportado por el sistema tiene que estar entre 0 y 120 km/h.
        \item La estimación de velocidad debe tener una precisión del 2 \% de fondo de escala.
        \item El sistema debe determinar la posición del material rodante para activar un contacto seco de relé según la zona de operación donde se encuentre.
    \end{enumerate}
    \vspace{1cm}
    \item Grupo de requerimientos asociados al modo aislado limitado
    \begin{enumerate}
        \item En modo aislado limitado el sistema debe evitar la aplicación del corte de tracción.
        \item En modo aislado limitado el sistema debe evitar la aplicación del freno de emergencia.
        \item Ante cualquier error interno, el sistema debe dejar de intervenir en la aplicación del corte de tracción.
        \item Ante cualquier error interno, el sistema debe dejar de intervenir en la aplicación del freno de emergencia.
        \item En modo aislado limitado el sistema debe emitir una señal sonora intermitente a través de un buzzer.
        \item En modo aislado limitado el sistema debe evitar que la velocidad del material rodante supere una serie de límites configurados.
        \begin{enumerate}
            \item Si al pasar de modo normal a modo aislado limitado no se cuenta con una estimación de velocidad, debe activar el corte de tracción y el freno de emergencia por 30 segundos.
            \item Si se supera una velocidad configurable (por defecto 30 km/h), debe activar el corte de tracción y emitir una señal sonora continua a través de un buzzer.
            \item Si se supera una velocidad configurable (por defecto 36 km/h), debe activar el freno de emergencia.
            \item Una vez aplicado, el corte de tracción debe dejar de aplicarse si la velocidad vuelve a ser menor a una velocidad configurable (por defecto 25 km/h).
            \item Una vez aplicado, el freno de emergencia sólo debe dejar de aplicarse luego de un tiempo configurable (por defecto 30 segundos) desde que se superó el límite.
            \item Si la lectura de velocidad es inválida, debe activar y desactivar el corte de tracción y freno de emergencia de manera alternada en ciclos de tiempo según perfiles preconfigurados (modo de tracción intermitente).
        \end{enumerate}
        \item El sistema debe interactuar con 5 Sistemas Instrumentados de Seguridad.
        \item El sistema debe ser capaz de identificar qué SIS está fallando y aislar solamente este dejando los demás SIS operativos.
        \item El sistema debe medir la posición del material rodante para modificar las velocidades máximas según la zona de operación donde se encuentre.
    \end{enumerate}
       
    \item Grupo de requerimientos asociados al modo aislado total
    \begin{enumerate}
        \item El sistema solo puede acceder a este modo accionando el control local o mediante comando remoto.
        \item En el modo aislado total el sistema debe liberar la velocidad de circulación.
        \item El sistema debe registrar en el registro de datos la activación de este modo.
    \end{enumerate}
       
    \item Grupo de requerimientos asociados al modo de tracción intermitente
    \begin{enumerate}
        \item El sistema solo deberá acceder a este modo cuando se encuentre en modo aislado limitado y no cuente con ninguna medición de velocidad válida o se seleccione de manera remota.
        \item El sistema debe permitir la configuración remota de distintos perfiles de operación de manera remota en donde se configuran los valores de Tiempo del permiso de Tracción, Tiempo de ciclo en deriva, Cantidad de ciclos antes de aplicar freno y Tiempo de espera antes de comienzo de nuevo ciclo.
    \end{enumerate}
       \vspace{1cm}
    \item Grupo de requerimientos asociados al hardware y al gabinete
    \begin{enumerate}
        \item El sistema utilizará una fuente externa de 5 V de tensión continua que pueda soportar hasta 25W de potencia.
        \item Los conectores deben estar bien identificados para facilitar la correcta conexión.
        \item El sistema debe poseer una placa de circuito impreso con el procesador y periféricos necesarios para el procesamiento de las señales del material rodante y una segunda placa para los elementos necesarios para la interacción con el conductor.
        \item El diseño de la placa de circuito impreso debe contemplar las recomendaciones de la norma IPC 2221 \cite{norma_ipc2221} a fines de asegurar la manufacturabilidad del equipo. 
    \end{enumerate}
           
    \item Grupo de requerimientos asociados al desarrollo del firmware
    \begin{enumerate}
        \item El desarrollo del software debe contemplar las recomendaciones de las normas UNE-EN 50126 y UNE-EN 50128 \cite{norma_50128}.
        \item El sistema debe trabajar con un sistema operativo en tiempo real para mejorar el desempeño y la seguridad del equipo.
    \end{enumerate}
\end{enumerate}

Estos requerimientos permiten definir de manera clara las funcionalidades, comportamientos y especificaciones de diseño del sistema. Es fundamental tener bien definidos los requerimientos en las primeras etapas del proyecto y acordarlos con todos los actores involucrados hasta obtener una versión definitiva. Cualquier modificación realizada en fases más avanzadas puede provocar un gran desvío en la planificación y generar un esfuerzo considerable de cambio.

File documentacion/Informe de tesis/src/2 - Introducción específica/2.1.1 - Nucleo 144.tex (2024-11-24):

\subsubsection{STM32 Nucleo-144}

La STM32 Nucleo-144 es una familia de placas de desarrollo basada en los microcontroladores STM32 de la familia ARM Cortex-M, diseñada para facilitar la creación de prototipos y el desarrollo de sistemas embebidos \cite{nucleo144}. Esta familia de placas es parte de la serie Nucleo de STMicroelectronics, conocida por ofrecer soluciones flexibles y accesibles para una amplia gama de aplicaciones, desde dispositivos IoT (\textit{Internet of Things}) hasta sistemas críticos. En la figura \ref{fig:nucleo144} se puede visualizar la placa de desarrollo NUCLEO F429ZI de la familia STM32 Nucleo-144 que se utiliza en este proyecto.\\

\begin{figure}[H]
    \centering
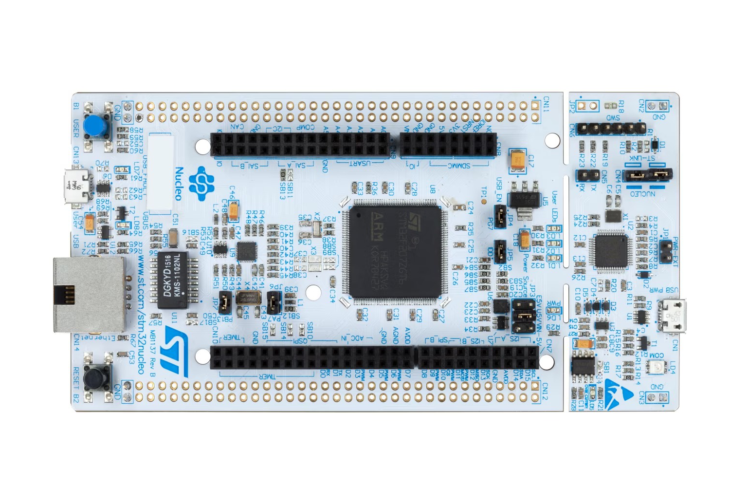
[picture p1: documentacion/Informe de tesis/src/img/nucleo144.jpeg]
    
    \caption{Placa de desarrollo NUCLEO F429ZI de STMicroelectronics,}
    \label{fig:nucleo144}
\end{figure}

La NUCLEO F429ZI se caracteriza por su gran versatilidad y un conjunto de características técnicas que la hacen adecuada para proyectos que requieren un rendimiento alto y conectividad avanzada. Entre sus especificaciones más destacadas se incluyen:

\begin{itemize}
    \item \textbf{Microcontrolador}: está equipada con un microcontrolador basado en la arquitectura ARM Cortex-M que ofrece un excelente rendimiento junto con una amplia gama de interfaces de conectividad y capacidades avanzadas de procesamiento en tiempo real. La NUCLEO F429ZI incluye el microcontrolador STM32F429ZI \cite{stm32f429zi} tiene un núcleo ARM Cortex-M4 que corre ST-LINK/V2-1a 180 MHz con unidad de punto flotante (FPU), memoria flash de 2 MB y RAM de 256 KB. 

    \item \textbf{Conectividad}: dispone de múltiples interfaces de comunicación, como UART, I2C, SPI, USB, Ethernet y CAN, lo que la convierte en una opción idónea para sistemas que requieren interconexión de múltiples dispositivos y la transmisión de datos en tiempo real.

    \item \textbf{Pines}: incluye un conector de 144 pines, lo que ofrece una gran cantidad de líneas de entrada/salida (GPIO) para controlar y conectar diversos módulos y periféricos. Además, esto permite acceso a todos los pines del microcontrolador lo que permite mayor flexibilidad para la asignación de sus funciones.

    \item \textbf{Programación integrada y \textit{debugging}}: incorpora una interfaz ST-LINK/V2-1 que permite la programación y depuración del microcontrolador sin necesidad de hardware adicional \cite{st_link}. Esto simplifica el desarrollo y facilita la identificación y corrección de errores durante las pruebas del sistema.

    \item \textbf{Alimentación}: puede ser alimentada tanto por USB como por una fuente externa de 5 V o 3,3 V, lo que la hace adaptable a diferentes entornos operativos.
\end{itemize}

Una de las grandes ventajas de la NUCLEO F429ZI es la posibilidad de desarrollar firmware utilizando herramientas muy potentes como STM32CubeIDE \cite{stCubeIde}, que proporciona un entorno de desarrollo completo y gratuito. Mediante una interfaz gráfica, se puede configurar la función de cada uno de los pines, nombrarlos y asegurarse de que no haya superposiciones de definiciones o protocolos de comunicación definidos sin los pines necesarios para que funcione. También facilita la configuración de un sistema operativo en tiempo real, permitiendo la declaración de las distintas tareas y mecanismos de sincronización. Además, el uso de bibliotecas como STM32CubeMX \cite{stCubeMx} facilita la configuración de los periféricos del microcontrolador y la generación de código, reduciendo el tiempo de desarrollo y minimizando la posibilidad de errores.

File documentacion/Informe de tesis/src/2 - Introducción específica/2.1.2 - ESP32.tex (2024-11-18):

\subsubsection{ESP32 Devkit-C}

 El ESP32 Devkit-C es una placa de desarrollo compacta y versátil basada en el microcontrolador ESP32 de Espressif Systems, una solución popular en el ámbito de los sistemas embebidos y aplicaciones IoT \cite{esp32}. Este módulo está diseñado para ofrecer una plataforma accesible para el desarrollo de aplicaciones que requieren conectividad Wi-Fi \cite{ieee_802.11} y Bluetooth \cite{bluetooth}, así como capacidades de procesamiento avanzadas. En la figura \ref{fig:esp32}
 se puede visualizar el módulo ESP32 Devkit-C. \\

\begin{figure}[H]
    \centering
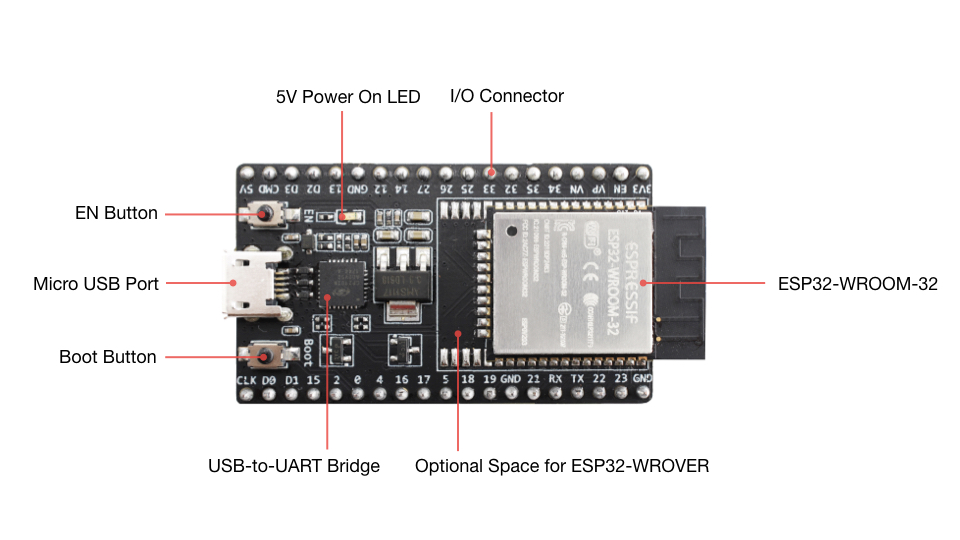
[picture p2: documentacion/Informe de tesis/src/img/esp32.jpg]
    
    \caption{Placa de desarrollo ESP32 Devkit-C}
    \label{fig:esp32}
\end{figure}

Algunas de las características principales del ESP32 son las siguientes:
\begin{itemize}
    \item \textbf{Microcontrolador dual-core}: cuenta con un procesador dual-core Xtensa LX6 que opera a una velocidad de hasta 240 MHz. Esta arquitectura multiprocesador permite ejecutar tareas paralelas, lo que resulta ventajoso en aplicaciones donde es necesario manejar múltiples procesos simultáneamente, como la gestión de comunicaciones y control de dispositivos.
    \item \textbf{Conectividad inalámbrica}: uno de los aspectos más destacados del ESP32 es su capacidad de conectividad inalámbrica:
        \begin{itemize}
            \item \textbf{Wi-Fi 802.11 b/g/n}: incluye un módulo Wi-FI integrado que permite conectarse a redes inalámbricas, ya sea como cliente o como punto de acceso.
            \item \textbf{Bluetooth 4.2 (BLE y clásico)}: soporta Bluetooth de baja energía (BLE) y Bluetooth clásico, lo que facilita la comunicación con una amplia variedad de dispositivos, desde teléfonos móviles hasta sensores y actuadores.
        \end{itemize}
    \item \textbf{Amplia gama de interfaces de comunicación}: ofrece varias interfaces periféricas, lo que lo hace adecuado para interactuar con otros dispositivos y sensores (UART, SPI, I2C, CAN, PWM, ADC y DAC).
    \item \textbf{Memoria}: incluye 520 KB de SRAM y hasta 16 MB de flash externa, lo que le permite ejecutar aplicaciones complejas y almacenar datos de manera eficiente. Esta combinación de memoria es adecuada para gestionar tanto tareas de conectividad como de procesamiento en tiempo real.
    \item \textbf{Bajo consumo}: gracias a su arquitectura optimizada para el ahorro de energía, el ESP32 ofrece múltiples modos de bajo consumo, como el modo de suspensión profunda. Esto es especialmente útil en aplicaciones IoT donde la eficiencia energética es crucial y los dispositivos deben funcionar durante largos períodos con baterías limitadas.
    \item \textbf{Capacidades de seguridad}: está equipado con una serie de características de seguridad integradas, como encriptación de hardware (AES, RSA), arranque seguro y protección de memoria, lo que lo hace adecuado para aplicaciones donde la integridad y confidencialidad de los datos son esenciales.
\end{itemize}

El ESP32 es compatible con una amplia variedad de entornos de desarrollo, entre ellos Arduino IDE \cite{arduino_ide}, Espressif IoT Development Framework (ESP-IDF) \cite{esp_ids} o PlatformIO \cite{platformio}. 
Estas herramientas permiten a los desarrolladores adaptar el entorno de trabajo a sus necesidades específicas. El uso de estos entornos no solo mejora la productividad, sino que también ofrece ventajas clave como facilidad para el desarrollo, una amplia comunidad de soporte, y la capacidad de escalar los proyectos de prototipos a soluciones más avanzadas y robustas.

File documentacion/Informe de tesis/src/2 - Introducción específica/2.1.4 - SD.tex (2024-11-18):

\subsubsection{Memoria SD}

Las memorias SD (\textit{Secure Digital}) son dispositivos de almacenamiento de datos que han ganado popularidad debido a su tamaño compacto, capacidad de almacenamiento y facilidad de uso. Son ampliamente utilizadas en diversas aplicaciones, desde cámaras digitales hasta sistemas embebidos, gracias a su versatilidad y eficiencia. En la figura \ref{fig:sd_card} se visualiza una memoria SD.\\

\begin{figure}[H]
    \centering
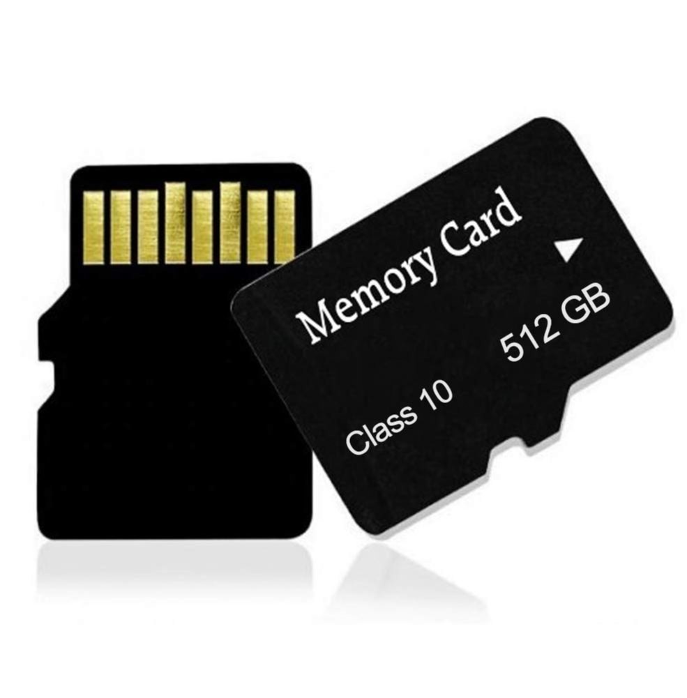
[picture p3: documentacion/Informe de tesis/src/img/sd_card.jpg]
    
    \caption{Memoria SD}
    \label{fig:sd_card}
\end{figure}

Las memorias SD cuentan con las principales características: 
\begin{itemize}
    \item \textbf{Capacidad de almacenamiento}: las memorias SD están disponibles en varias capacidades, que varían desde unos pocos megabytes hasta varios terabytes. Esto permite a los usuarios elegir la memoria adecuada según sus necesidades específicas de almacenamiento.
    \item \textbf{Velocidades de transferencia}: existen diferentes clases de memorias SD, como Clase 2, 4, 6, 10, y UHS-I y UHS-II, que determinan la velocidad mínima de lectura y escritura. Las memorias de clase más alta son ideales para aplicaciones que requieren una rápida transferencia de datos, como la grabación de video en alta definición.
    \item \textbf{Interfaz de comunicación}: Las memorias SD utilizan una interfaz estándar que permite la conexión con dispositivos a través de protocolos como SPI (\textit{Serial Peripheral Interface}) o SDIO (\textit{Secure Digital Input Output}). Esto facilita su integración en una variedad de sistemas.
    \item \textbf{Durabilidad y fiabilidad}: muchas memorias SD están diseñadas para resistir condiciones adversas, como temperaturas extremas, golpes y vibraciones. Esto las hace adecuadas para su uso en entornos donde la robustez es fundamental.
    \item \textbf{Facilidad de uso}: la implementación de memorias SD es sencilla, ya que muchos dispositivos y plataformas de desarrollo ofrecen bibliotecas y herramientas que facilitan la lectura y escritura de datos en estas memorias.
\end{itemize}

En los sistemas embebidos las memorias SD se colocan sobre un zócalo que permite removerlas para luego insertar la memoria SD en una PC y descargar los datos, formatearla o repararla. También existen módulos para Arduino que permiten integrar una memoria SD al proyecto en etapas tempranas antes de fabricar un PCB propio y soldar un zócalo. Esto facilita mucho el mantenimiento y el desarrollo de sistemas que contienen almacenamiento de datos en memorias SD. \\

Existen tres formatos principales de memorias SD: SD estándar (32 x 24 mm), miniSD (21.5 x 20 mm) y microSD (15 x 11 mm). La microSD\textbf{ }es la más compacta y comúnmente utilizada en aplicaciones embebidas por su tamaño reducido y gran capacidad de almacenamiento. Por estos motivos, se utiliza el formato de memoria microSD para este proyecto. \\

Las memorias SD se han convertido en una solución de almacenamiento clave en muchos dispositivos electrónicos, ofreciendo una combinación de flexibilidad, capacidad y rendimiento que se adapta a una amplia gama de aplicaciones.

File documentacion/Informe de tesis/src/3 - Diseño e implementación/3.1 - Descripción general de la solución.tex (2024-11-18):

\subsection{Descripción general de la solución}

Una vez relevados todos los requerimientos asociados al proyecto y revisados los diseños del prototipo anterior del SAL/T, se generó un diagrama en bloques de la solución donde se contemplan todos los módulos involucrados, que se puede visualizar en la figura \ref{fig:diagrama_bloques}. Se observa que el sistema interactúa con distintos elementos externos pertenecientes a la formación ferroviaria, como los sistemas instrumentados de seguridad o el control central de la formación. Se considera también el uso de una fuente externa que permite alimentar al SAL/T con 5 V de tensión continua generados a partir de las baterías de alimentación de los trenes que están en un rango de entre 72-110 VDC dependiendo del modelo de la formación. También existe una interacción con el bus de datos que conecta el registrador de eventos Hasler Teloc 1500 \cite{hasler} con el indicador de velocidad Hasler y otra interacción con un subsistema externo que realiza la interpretación de la velocidad a partir de la señal generada por un generador de impulsos; ambas interactúan con las interfaces RS-485 del sistema. \\

Con el diagrama en bloques del sistema, se pueden considerar las distintas interacciones que va a tener el controlador principal y elegir algún microcontrolador (MCU) que tenga las interfaces necesarias para conectarse con todos los módulos, y la capacidad de procesamiento adecuada para este tipo de aplicaciones. Después de analizar las distintas alternativas disponibles en el mercado, se eligió el microcontrolador STM32F429ZI ya que tiene un buen rendimiento por su core ARM Cortex-M4 que corre en una frecuencia de hasta 180 MHz con una unidad de punto flotante, soporta múltiples interfaces de comunicación (I2C, SPI, UART, GPIO, ADC, etc.) y cuenta con memoria flash y RAM suficientes para un firmware complejo. Otra ventaja de usar los microcontroladores de ST es que cuentan con el entorno de desarrollo STM32CubeIDE que es muy amigable para la programación del MCU y la configuración de todos los periféricos. \\ 

Una vez seleccionado el microcontrolador principal, se decidió armar el prototipo del SAL/T a partir de una placa de desarrollo que contiene al STM32F429ZI para mantener el alcance del proyecto dentro de lo esperado para este trabajo. Por lo tanto, se seleccionó la placa de desarrollo NUCLEO F429ZI que contiene el MCU mencionado. Esta placa incluye una interfaz ST-LINK/V2-1 que permite la programación y \textit{debugging} del microcontrolador sin necesidad de hardware adicional. También trae circuitos adicionales como el oscilador de cristal, circuito de reset, LEDs, botones de prueba y reguladores de tensión que permiten alimentar la placa con distintos niveles de tensión. Todas estas características facilitan el desarrollo del proyecto porque permiten probar algunos circuitos, partes del firmware y la comunicación con otros módulos, sin tener todavía fabricado un PCB diseñado ad hoc para el proyecto. \\

Con la placa de desarrollo definida como base del sistema, se realizó una búsqueda de los posibles circuitos o módulos para implementar los distintos bloques que cumplan con los requerimientos acordados y que permitan hacer un uso distribuido de las interfaces que ofrece el MCU. Para la selección de componentes y módulos, se consideraron algunos criterios que facilitan la selección. Por ejemplo, se intentó reutilizar módulos o componentes ya utilizados en otros proyectos del grupo GICSAFe para poder ayudarse de diseños y experiencias de uso previas; esto reduce la posibilidad de error o mal funcionamiento de los circuitos y acelera tiempos de descubrimiento en fallas ocultas que pueden traer asociadas. Otro criterio importante fue utilizar dos distribuidores de componentes electrónicos grandes (Mouser \cite{mouser} y Digikey \cite{digikey}) para verificar que estas partes estén disponibles y en stock de manera general y que sean recomendados para nuevos diseños y no en un estado cercano al final de su ciclo de vida (EOL, \textit{End-of-Life}); de esta manera se asegura que el prototipo y su implementación sean reproducibles y sus partes fáciles de conseguir en el mediano plazo. \\

Con una idea más clara de los circuitos que se podían usar para implementar los distintos bloques y sus variantes de comunicación con el MCU, se realizó el diagrama de la figura \ref{fig:diagrama_bloques_coms} que muestra los protocolos de comunicación entre el MCU y los distintos circuitos del sistema. Esto permitió hacer una asignación de las interfaces disponibles para cada bloque. 

\begin{figure}[H]
    \centering
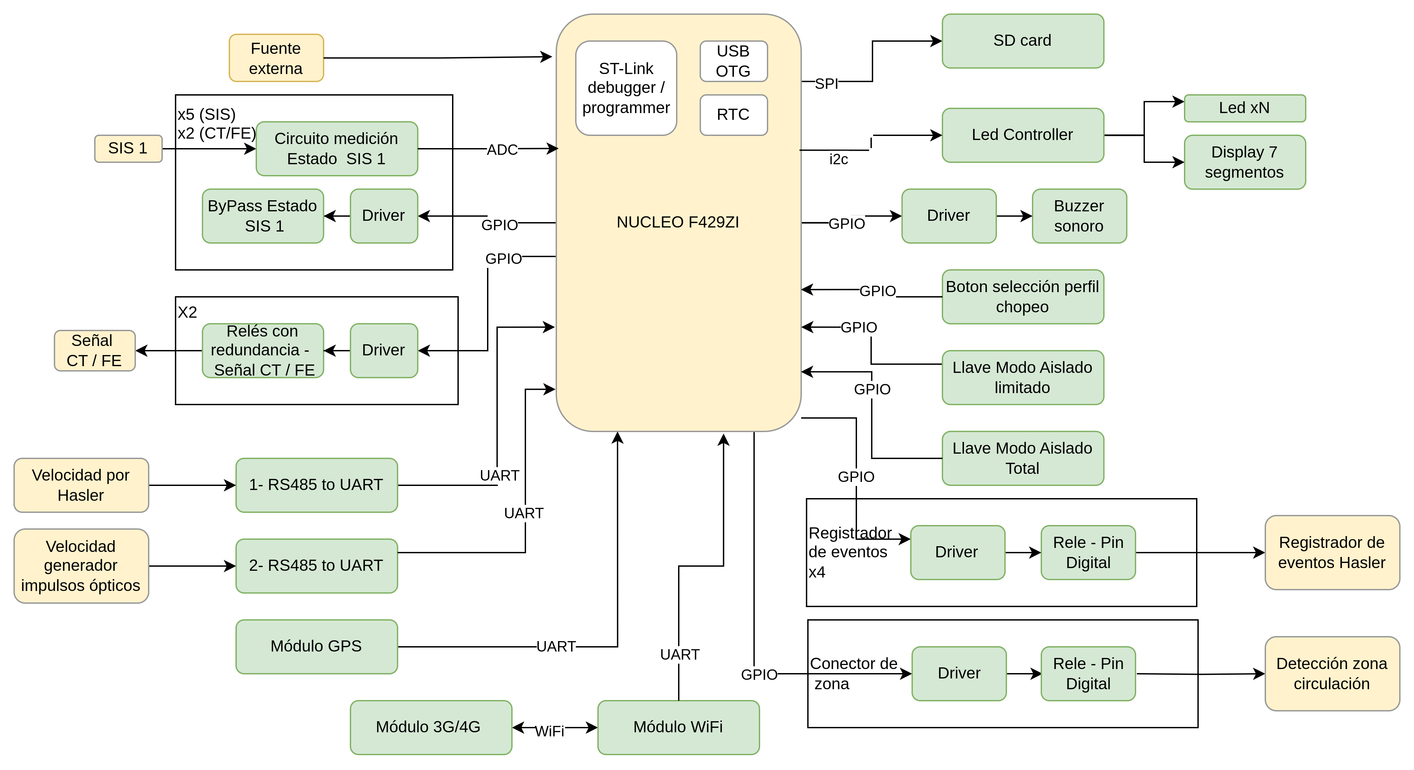
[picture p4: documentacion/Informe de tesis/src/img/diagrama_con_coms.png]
    
    \caption{Diagrama con interfaces de comunicación del SAL/T}
    \label{fig:diagrama_bloques_coms}
\end{figure}

Además, considerando que según los requisitos el sistema cuenta con un panel frontal para interactuar con el maquinista de la formación, se realizó el diseño de este panel para validar que tuviera todas las indicaciones e interacciones acordadas en los requerimientos. En la figura \ref{fig:panel_frontal} se puede visualizar la interfaz humano-máquina (IHM) que va a mostrar el estado del SAL/T en todo momento y permitir algunas interacciones mínimas al maquinista como la habilitación del modo aislado limitado o el cambio del perfil intermitente en caso de no contar con mediciones de velocidad activas. 
 
\begin{figure}[H]
    \centering
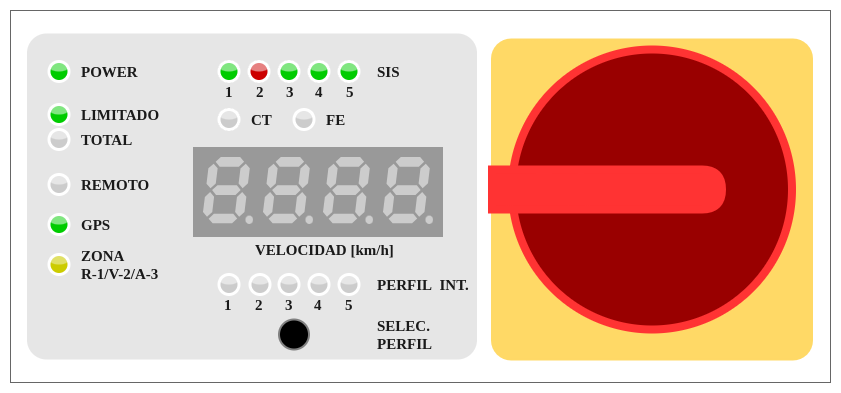
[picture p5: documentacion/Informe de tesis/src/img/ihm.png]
    
    \caption{Diseño del panel frontal del SAL/T}
    \label{fig:panel_frontal}
\end{figure}

Para comprender el diseño de los circuitos de medición y aislamiento de los SIS, así como la activación de las señales críticas de corte de tracción (CT) y freno de emergencia (FE), es importante entender cómo es la conexión en una formación ferroviaria entre los SIS y las señales críticas. Lo primero a considerar es que las líneas de activación de la señal CT y la de la señal FE son independientes; cada una tiene una electroválvula separada e interactúa con los SIS en una línea propia. Luego, para cada una de estas señales críticas, existe una conexión en serie entre la alimentación de la electroválvula, una llave cerrada que se abre en caso de falla del SIS para cada uno de los SIS, la electroválvula que habilita y deshabilita la señal crítica y tierra. Esta electroválvula, al seguir el concepto de \textit{fail-safe}, debe estar alimentada para poder liberar alguna de las señales críticas, y en caso de cortarse la alimentación, ya sea por una falla en la alimentación o porque uno de los SIS está fallando y reporta un estado inseguro abriendo la llave, se activa la señal de CT o de FE para frenar la formación. Este esquema se puede visualizar en la figura \ref{fig:lineas_ct_fe}.\\

\begin{figure}[H]
    \centering
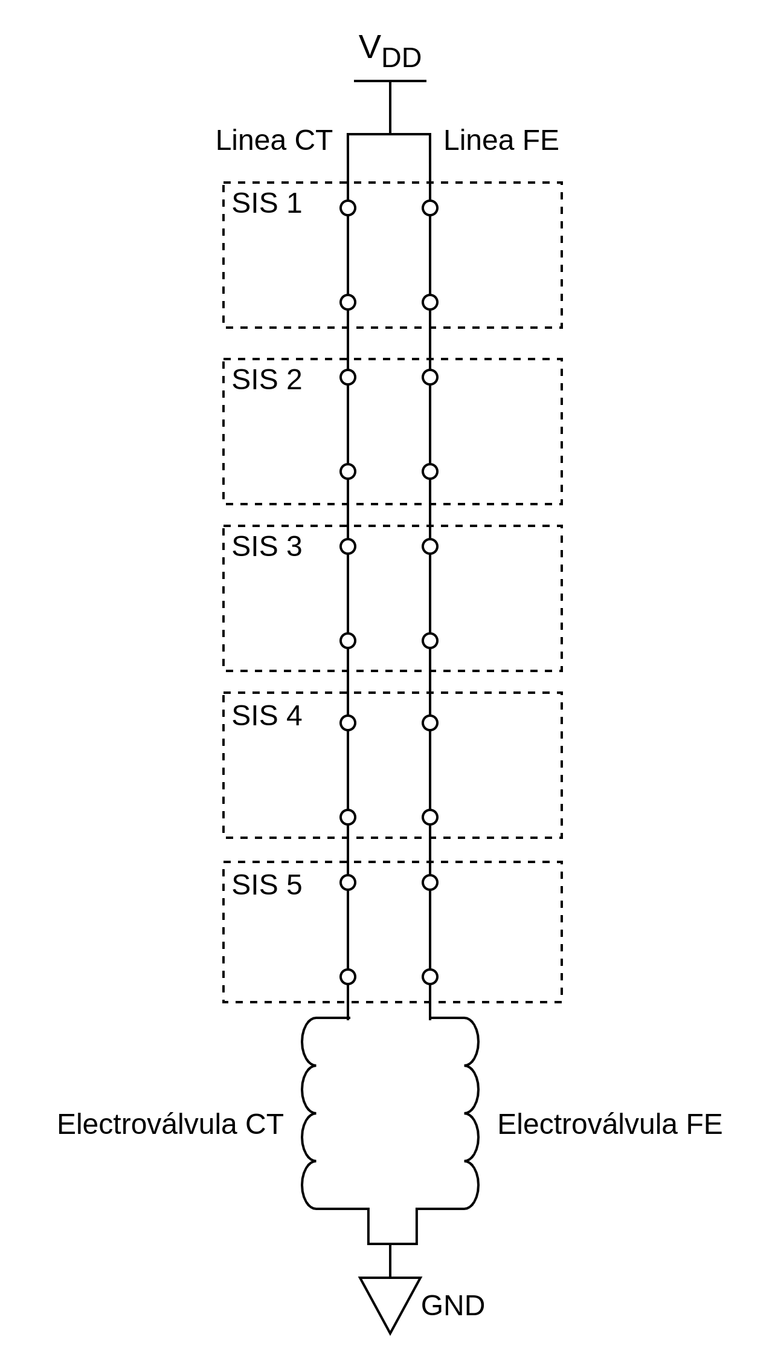
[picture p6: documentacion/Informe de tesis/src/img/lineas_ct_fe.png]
    
    \caption{Lineas de señales de CT y FE}
    \label{fig:lineas_ct_fe}
\end{figure}

La idea del proyecto SAL/T es no modificar la arquitectura actual de los sistemas dentro de la formación, sino agregar algunos circuitos más para poder incrementar su seguridad sin necesidad de cambios en lo preexistente. Por esto, se propuso realizar las conexiones de la figura \ref{fig:señales_criticas} para poder realizar mediciones del estado de cada SIS independientemente, poder aislar cualquiera de ellos en caso de entrar en un modo aislado limitado, y también tener un último control para la activación de las señales críticas imponiendo una alimentación por fuera de la línea de los SIS. En la figura se muestran 2 SIS a modo de ejemplo y la línea de la señal de FE, pero el proyecto contempla 5 SIS y este mismo esquema para la señal de FE y CT. 

\begin{figure}[H]
    \centering
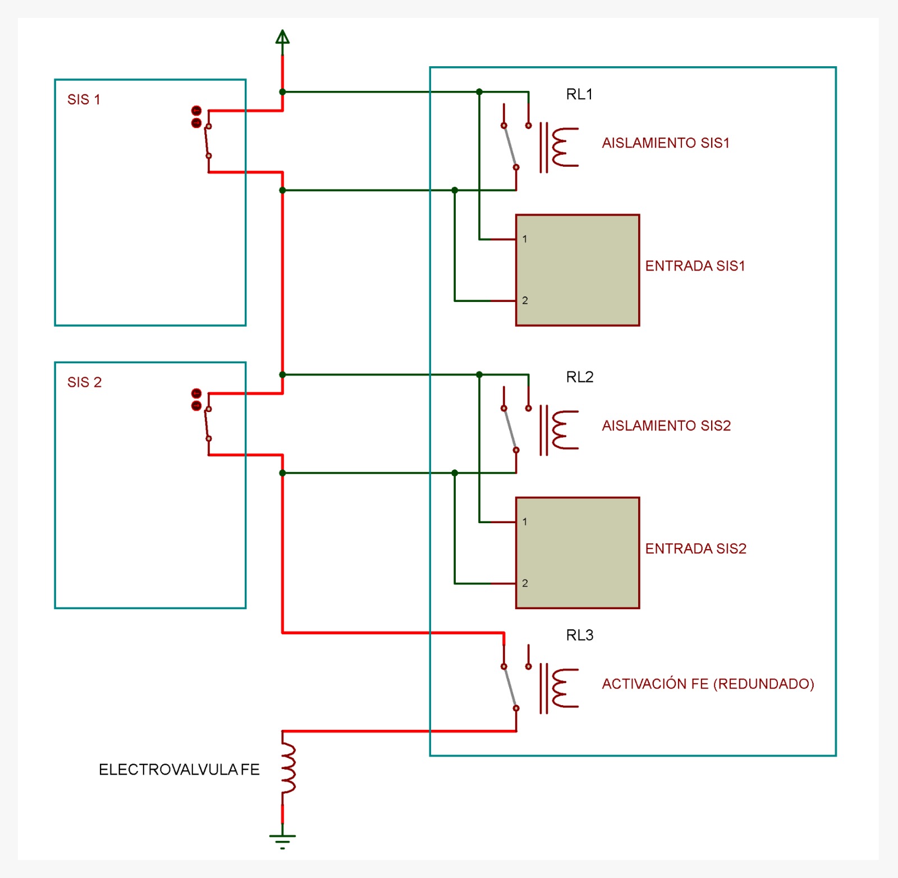
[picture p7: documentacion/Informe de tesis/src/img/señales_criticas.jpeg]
    
    \caption{Diseño de conexión con SIS y señales críticas en el SAL/T}
    \label{fig:señales_criticas}
\end{figure}

Con la arquitectura general de la solución ya definida, se decidió modularizar el sistema en dos placas separadas. Una placa principal donde se va a realizar todo el procesamiento del sistema, se van a recibir las mediciones de velocidad, del estado de los SIS, de la posición, los comandos remotos y donde se va a interactuar con el aislamiento de los SIS, la activación de las señales críticas, el registro de eventos internos y externos de manera local y remoto y la descarga de los eventos guardados. La segunda placa va a estar dedicada a la interacción con el maquinista y va a contar con el panel frontal, los LEDs indicativos, el display para mostrar la velocidad de la formación y un botón para seleccionar el perfil intermitente a ejecutar en el modo aislado limitado cuando no se cuenta con mediciones de velocidad válidas. De esta manera, se permite mayor flexibilidad en el diseño de las placas y una mejor modularización del sistema. \\ 

Para realizar el diseño del hardware se utilizó KiCad \cite{kicad} versión 6; una herramienta de software libre utilizada para el diseño de esquemáticos y PCB. También se utilizó LTspice \cite{LTspice}; un simulador de circuitos de código abierto desarrollado por Analog Devices, utilizado para simular el comportamiento de los distintos circuitos en la etapa de diseño. Para llevar un control de versiones, tanto de los archivos de diseño de hardware como de firmware, se utilizó GitHub \cite{github}; una plataforma de desarrollo colaborativo que utiliza Git \cite{git} como sistema de control de versiones que permite almacenar, gestionar y rastrear cambios en el código fuente de sus proyectos. Se utilizó un repositorio donde se fueron avanzando los distintos módulos (tanto de hardware como de firmware) del proyecto en distintas \textit{branches} para finalmente llegar a una versión unificada en la \textit{branch} principal. El repositorio es público y accesible en \href{https://github.com/martinanus/salt}{\textit{github.com/martinanus/salt}} \cite{repo}.

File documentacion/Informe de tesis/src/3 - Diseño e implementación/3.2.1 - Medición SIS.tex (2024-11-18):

\subsection{Implementación de hardware}
\subsubsection{Medición de estado de los SIS}

El SAL/T debe interactuar con cinco sistemas instrumentados de seguridad (SIS) que cada uno cuenta con dos llaves de estado; una para la línea de la señal crítica de corte de tracción (CT) y la otra para la señal crítica de freno de emergencia (FE). Estas llaves van a estar en un estado cerrado cuando el SIS esté funcionando correctamente y no detecte ninguna situación peligrosa en la formación, y se van a abrir para interrumpir la alimentación de las señales críticas ante una falla en el SIS o la detección de alguna condición peligrosa. \\ 

Considerando el diagrama de conexión ya presentado en la figura \ref{fig:señales_criticas}, se puede interpretar que cuando la llave está cerrada, la diferencia de tensión entre sus terminales va a ser nula. En cambio, si en toda la línea existe un único interruptor abierto, se espera que haya una diferencia de tensión de $V_{ALIM}$ entre los terminales del interruptor. Esto se debe a que, al abrir el circuito, no va a circular corriente por la línea. Entonces, el terminal positivo tendrá una tensión de $V_{ALIM}$ y el terminal negativo una tensión de tierra, ya que la electroválvula no va a introducir ninguna caída de tensión por la falta de corriente. Por lo tanto, se pueden resumir la diferencia de tensión esperada en los terminales de un SIS en la tabla \ref{tab:switch_state}. 

\begin{table}[htb]
    \begin{tabular}{|c|c|} 
        \hline
        \textbf{Estado de llave} & \textbf{Tensión entre terminales}\\
        \hline
        Cerrada     &     0 V   \\
        \hline
        Abierta     &     $V_{ALIM}$ \\
        \hline
    \end{tabular}
    \label{tab:switch_state}
    \caption{Diferencia de tensión entre los terminales de un SIS}
\end{table}

Los rangos de tensión de alimentación de las baterías de las formaciones consideradas son $ 72 VDC < V_{ALIM} < 110 VDC $. Y considerando que estos buses de mayor tensión pueden no tener una puesta de tensión en común con el SAL/T, se decidió utilizar un circuito de medición diferencial para calcular la tensión entre las terminales de un interruptor independientemente de su tensión contra la tierra del circuito y luego conectar la tensión medida en un conversor analógico-digital (ADC) del microcontrolador para poder obtener de manera digital un valor para la tensión. \\ 

Con el objetivo de alterar lo menos posible la línea de las señales críticas, se optó por utilizar un amplificador de instrumentación para poder medir la tensión diferencial entre los terminales de las llaves. Este dispositivo permite medir una tensión diferencial rechazando cualquier señal de modo común con una gran impedancia de entrada lo que permite derivar una pequeña corriente de la línea principal sin alterarla. El modelo seleccionado fue el INA823DGKR de Texas Instrument \cite{INA823DGKR}, un amplificador de instrumentación con salida \textit{single-ended} con un rango de ganancia programable de 1 a 1000 con una resistencia externa, con una baja corriente de polarización de entrada de 1,2 nA y permite la alimentación con una fuente dual de $\pm1.1$ a $\pm18 $ V. Para la aplicación en el SAL/T, se va a utilizar una ganancia de 1 (sin resistencia externa conectada) y se va a alimentar el amplificador con una tensión dual de $\pm$5 V.\\

Para generar la tensión de -5 V a partir de la fuente de alimentación de +5 V, se utilizó el regulador de tensión ICL7660AIBAZA de Renesas Electronics \cite{ICL7660AIBAZA} diseñado para invertir una tensión de entrada positiva y generar una salida negativa. Este permite la inversión de la tensión de entrada en el rango de 1,5 a 12 V, tiene un bajo consumo de corriente de 80 $\mu$A, funciona con un oscilador interno a 10 kHz que elimina la necesidad de generar una señal de reloj externa y solo requiere dos capacitores externos. El circuito integrado (CI) viene en un encapsulado VSSOP-8 para montaje superficial. En la figura \ref{fig:ICL7660AIBAZA}, se observa la conexión del ICL7660AIBAZA siguiendo las recomendaciones de la hoja de datos para una tensión de entrada de +5 V; se utilizaron dos capacitores electrolíticos de 10 $\mu$F y se obtuvo una tensión de salida de -5 V. 

\begin{figure}[H]
    \centering
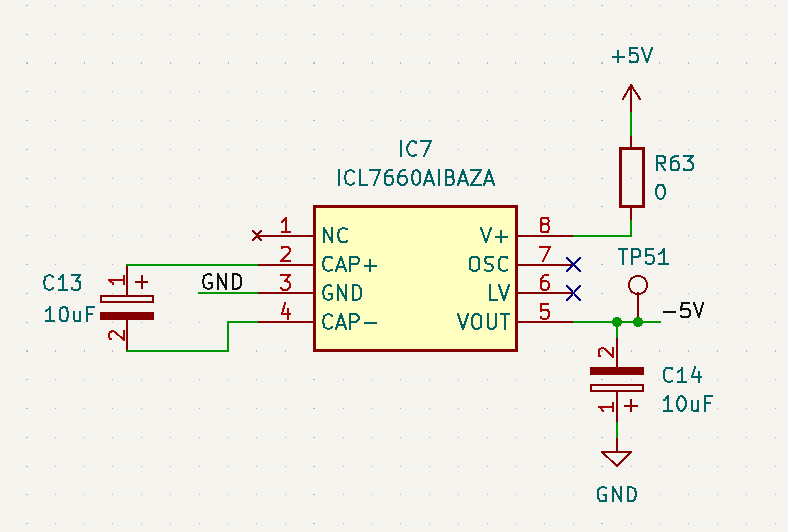
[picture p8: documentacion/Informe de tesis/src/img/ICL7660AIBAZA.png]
    
    \caption{Esquemático del circuito para generación de tensión de alimentación negativa}
    \label{fig:ICL7660AIBAZA}
\end{figure}

Para poder medir la tensión diferencial en las terminales de las llaves del SIS utilizando el INA823DGKR alimentado con $\pm$5 V, es necesario adaptar las tensiones a medir a un rango dentro de los extremos de la alimentación, ya que podría haber una diferencia de hasta 110 V sobre esa llave. Para reducir esta tensión diferencial, se implementó una red de resistencias que permiten mantener la diferencia de tensión, pero reducida por un factor seleccionado y utilizando una tierra como referencia para tener las tensiones positivas y negativas a la entrada del amplificador de instrumentación. \\ 

Si bien el rango máximo para las entradas podía ser $\pm$5 V, considerando que la ganancia del amplificador es 1 y que la salida va a ingresar a un ADC del microcontrolador que trabaja en un rango de hasta 3,3 V de entrada, hay que reducir el rango máximo esperado hasta esa tensión. Por lo tanto, si consideramos 110 V como la máxima tensión diferencial en la llave del SIS, y armando una red de resistencias que divida esta tensión a la mitad colocando una tierra en la mitad del circuito, se debe calcular los valores de las resistencias tal que, en cada entrada del amplificador, haya como máximo una tensión de $\pm$1,65 V, ya que la salida es \textit{single-ended} y para esos valores máximos usaría el rango completo de 3,3 V del ADC. Considerando un divisor resistivo para cada terminal del SIS, que se conecten con una tierra a la mitad, se pueden calcular los valores de las resistencias con las siguientes ecuaciones: 

\begin{equation}
    \frac{V_{max\_ADC}}{2} = \frac{V_{max\_SIS}}{2} \cdot \frac{R2}{R1 + R2}    
\end{equation}

Despejando el divisor resistivo invertido para facilitar la selección de valores de resistencia y utilizando $ V_{max_ADC}=3.3$ V y $V_{max\_SIS} = 110$ V: 

\begin{equation}
    \frac{R1 + R2}{R2}  = \frac{V_{max\_ADC}}{V_{max\_SIS}} = 33.33
\end{equation}

Esto significa que la resistencia R1 tiene que ser, aproximadamente 33 veces más grande que R2. Además, considerando que se busca extraer la menor corriente posible de la línea de los SIS, se van a utilizar valores de resistencia muy altos así como también el amplificador cuenta con una impedancia de entrada muy alta. Con estos cálculos realizados, se seleccionaron los valores de R1=1 M$\Omega$ y R2=30 k$\Omega$ lo que genera un divisor resistivo de 34,33 veces la tensión original; esto permite darle un poco de margen al rango máximo calculado. \\

Con las distintas partes del circuito resueltas, en la figura \ref{fig:sis_medicion} se muestra un esquemático del circuito de medición de los SIS con los elementos explicados donde también se agregan 2 capacitores de desacople en la alimentación del amplificador para filtrar cualquier ruido que pueda venir en la línea. 

\begin{figure}[H]
    \centering
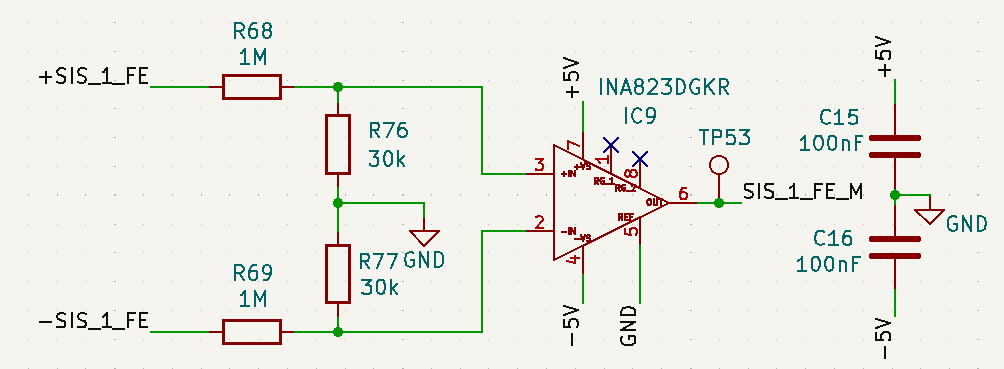
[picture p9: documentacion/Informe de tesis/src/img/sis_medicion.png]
    
    \caption{Esquemático del circuito de medición de los SIS}
    \label{fig:sis_medicion}
\end{figure}

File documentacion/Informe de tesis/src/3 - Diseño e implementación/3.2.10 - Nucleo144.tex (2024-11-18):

\subsubsection{Microcontrolador y placa STM32 Nucleo-144}

El procesamiento central del sistema se realiza en el microcontrolador STM32F429ZI incluido en la placa STM32 Nucleo-144. La placa permite la alimentación del MCU y de todos sus circuitos a través de distintas entradas como se puede observar en la figura \ref{fig:nucleo_pw}. Para el SAL/T, se utilizó la entrada de E5V para alimentar la placa utilizando la fuente de alimentación del sistema y para eso se debe colocar en el JP3 un cortocircuito entre los pines 1 y 2 para tomar la tensión de allí. Se observa que la placa incluye un circuito de regulación de tensión a 3,3 V para alimentar el MCU y otros circuitos internos. 

\begin{figure}[H]
    \centering
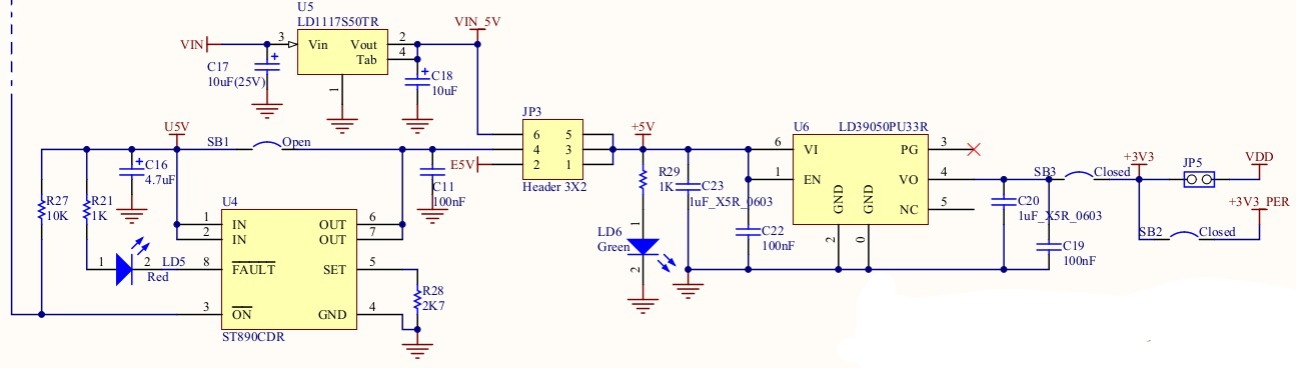
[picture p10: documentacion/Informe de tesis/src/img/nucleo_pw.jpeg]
    
    \caption{Esquemático de la alimentación de la placa STM32 Nucleo-144}
    \label{fig:nucleo_pw}
\end{figure}    

Para la inserción de la STM32 Nucleo-144 en la placa principal del SAL/T, se utilizaron los conectores de expansión morpho que permiten el acceso a todos los pines del MCU al usuario. Para eso, se soldaron los pines en la Nucleo y se colocaron conectores hembra en la placa principal. Se necesitaron dos conectores de 2x36 pines cada uno para conectar la placa. Este tipo de conectores permite colocar y sacar la placa fácilmente lo que permite manipularla mejor para la programación y cualquier prueba de circuitos que se quiera realizar sin la placa colocada. En la figura \ref{fig:diagrama_bloques_coms} se mostraron las distintas interfaces utilizadas del microcontrolador en las que se incluye ADC, SPI, UART, I2C y GPIO.

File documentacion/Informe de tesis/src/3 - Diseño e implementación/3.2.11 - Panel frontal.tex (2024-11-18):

\subsubsection{Panel frontal}

El panel frontal del SAL/T sigue el diseño de la figura \ref{fig:panel_frontal} utilizando una placa secundaria donde se colocan directamente los LEDs (\textit{Light-Emitting Diode}), el display de velocidad, el botón seleccionador de perfil intermitente y un buzzer sonoro. \\ 

El panel frontal cuenta con cuatro LEDs verdes utilizados para indicar el estado de la alimentación, el modo aislado limitado, el modo aislado total y el perfil intermitente seleccionados; diez LEDs RGB (\textit{Red Green Blue}) para indicar el estado de los SIS, de las señales de CT y FE, la presencia de un comando remoto activo, el estado del receptor GPS y un indicador de la zona de circulación actual de la formación; un botón para seleccionar el perfil intermitente a utilizar; el display de velocidad de cuatro dígitos 7 segmentos y la llave interruptora que queda por fuera de la placa secundaria. \\ 

Para controlar todos estos LEDs y el display de velocidad, se utilizó el controlador LED AS1115-BSST de ams OSRAM \cite{AS1115-BSST}. Este permite controlar hasta sesenta y cuatro LEDs u ocho dígitos de un display 7 segmentos reduciendo la cantidad de pines necesarios a utilizar del MCU ya que se conecta por protocolo I2C utilizando solamente dos cables. Este controlador permite setear la corriente de cada LED utilizando una resistencia externa; en este caso, siguiendo los valores normalizados y recomendados por la hoja de datos del controlador, se colocó una resistencia de 22 k$\Omega$ para obtener una corriente de 10 mA. El controlador también trae entradas para la detección de hasta dieciséis teclas en una matriz de teclas, pero esa funcionalidad no se utiliza en esta aplicación. \\

El AS1115-BSST utiliza un método de multiplexado en el cual cada grupo de LEDs o segmentos es controlado secuencialmente, encendiéndolos en rápida sucesión. Esto reduce la cantidad de pines necesarios para el control, ya que todos los LEDs no están encendidos simultáneamente, pero debido a la alta velocidad de escaneo, se perciben como si estuvieran encendidos de forma continua. Además, a través de la interfaz I2C, se envían comandos para controlar el brillo, encendido y apagado de los LEDs o segmentos, y se pueden ajustar los valores de corriente para mejorar la eficiencia energética.\\

En la figura \ref{fig:led_driver} se observa una aplicación típica de este controlador; para el SAL/T, se utilizó una alimentación de 5 V, un Rset = 22 k$\Omega$, la comunicación con el MCU solo con las líneas de SDA y SCL de I2C trabajando a 100 kHz sin el pin de interrupción, no se utilizaron las entradas de detección de teclas, y se conectó al display de cuatro dígitos 7 segmentos y a los LEDs mencionados previamente. \\

\begin{figure}[H]
    \centering
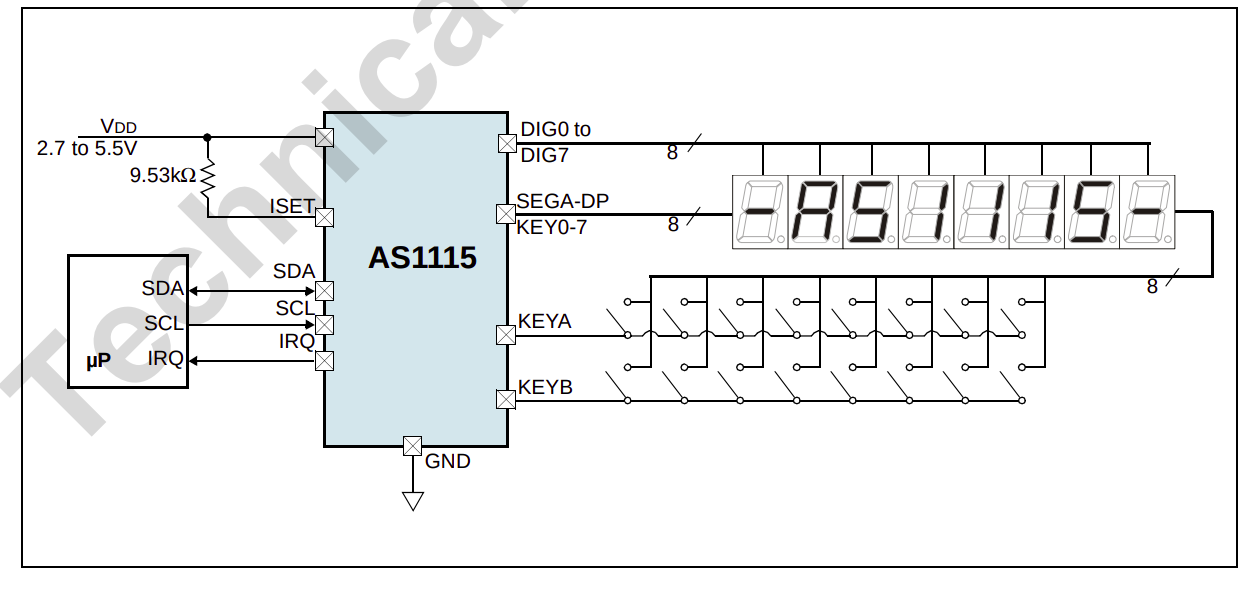
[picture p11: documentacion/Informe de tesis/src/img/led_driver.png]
    
    \caption{Aplicación típica de un controlador AS1115-BSST}
    \label{fig:led_driver}
\end{figure}    

Para los LEDs RGB utilizados se seleccionó el modelo WP154A4SEJ3VBDZGW/CA de Kingbright \cite{WP154A4SEJ3VBDZGW/CA} diseñado para aplicaciones que requieren indicación de estado multicolor. Ofrece alta luminosidad y bajo consumo de energía, con un encapsulado transparente de 5 mm, lo que lo hace ideal para proyectos que requieren señalización visual con múltiples colores en un solo componente. Trabajan con una corriente máxima de 20 mA por color, y tienen una caída de tensión e intensidad luminosa para cada color de: 

\begin{itemize}
    \item Rojo: 2 V - 300 mcd
    \item Verde: 3,3 V - 600 mcd
    \item Azul: 3,3 V - 500 mcd
\end{itemize}

Estos LEDs se montan \textit{through hole} y quedan sobresalientes a la placa para luego insertarlos dentro de un gabinete con agujeros para permitir la visualización de estos componentes. Tienen un encapsulado transparente y un lente de tipo redondo con un ángulo de visión de 30°.\\ 

Para los LEDs verdes se utilizó el modelo WP7113LZGCK de Kingbright \cite{WP7113LZGCK} que cuenta con características muy similares solo para el color verde del modelo RGB presentado. Las diferencias son que tiene una tensión Vf = 2,1 V, tolera una corriente máxima de 30 mA y su intensidad luminosa es un poco mayor, ya que puede llegar hasta 3000 mcd dependiendo de la corriente. \\ 

Para el display de velocidad se utilizó el modelo LTC-5723HR de Lite-On \cite{LTC-5723HR}; contiene cuatro dígitos con formato de 7 segmentos de color rojo en configuración cátodo común. Cada dígito tiene un tamaño de 8,1 x 14,2 mm. Funciona con una tensión directa de Vf = 2 V y corriente de hasta 20 mA por segmento. Es de montaje \textit{through-hole} lo que permite dejarlo visible por fuera de la placa con cierta separación. \\

En la figura \ref{fig:leds_model} se visualiza el display mencionado junto a un LED RGB y un LED verde utilizado para la implementación. 

\begin{figure}[H]
    \centering
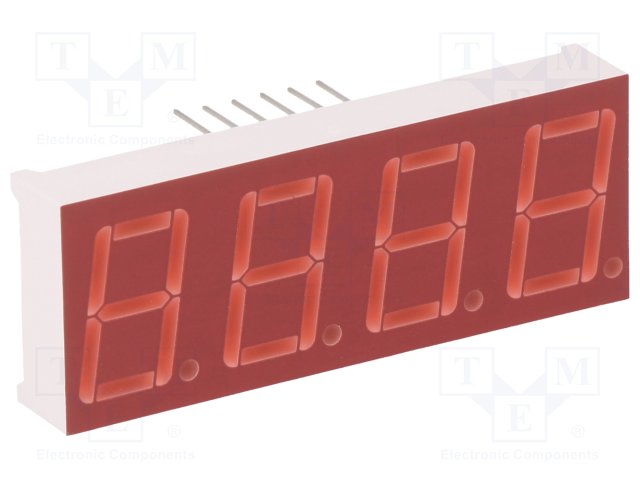
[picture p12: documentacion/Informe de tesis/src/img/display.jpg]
    
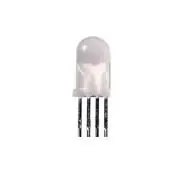
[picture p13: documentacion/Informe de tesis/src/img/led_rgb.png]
    
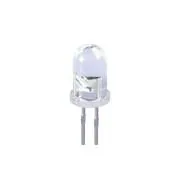
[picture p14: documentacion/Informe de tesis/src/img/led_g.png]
    
    \caption{Modelos utilizados para las indicaciones luminosas del panel frontal}
    \label{fig:leds_model}
\end{figure}    

Para el botón de selección del perfil intermitente se utilizó un interruptor con pulsador \textit{push switch} modelo de 1543-650-149 de Bourns \cite{1543-650-149} utilizando un circuito con una resistencia de \textit{pull-down} para forzar 0 V en la entrada del MCU cuando el interruptor está abierto y una resistencia para realizar un divisor resistivo de 5 V (alimentación de la placa) a 3,3 V (tensión de nivel alto de entrada digital del MCU). También se agregó una resistencia en serie de 100 Ohms. En la figura \ref{fig:chop_sel} se visualiza el circuito. 

\begin{figure}[H]
    \centering
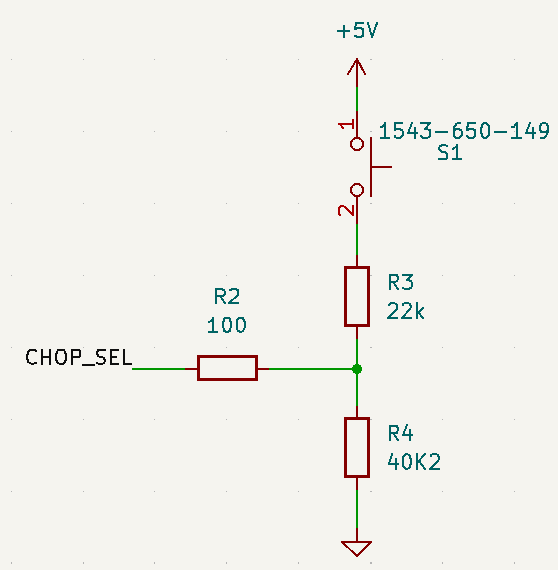
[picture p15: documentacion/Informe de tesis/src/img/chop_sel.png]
    
    \caption{Circuito del selector de perfil intermitente}
    \label{fig:chop_sel}
\end{figure}    

El panel frontal cuenta también con un buzzer sonoro que se activa de manera intermitente cuando se circula en modo aislado limitado y suena de manera continua cuando se exceden los límites de velocidad establecidos. Para el buzzer sonoro se utilizó el modelo CEM-1205-IC de SameSky \cite{CEM-1205-IC}. Este módulo cuenta con un oscilador interno que al energizarse con 5 VDC emite una señal sonora de 2400 Hz consumiendo 30 mA de corriente. Para el control del encendido de este módulo, se utilizó un transistor MOSFET canal P modelo NVTR0202PLT1G de onsemi \cite{NVTR0202PLT1G} conectado como se visualiza en la figura \ref{fig:buzzer_sch}. Cuando la señal de control BUZZER\_C está en estado bajo 0 V, el circuito permite la corriente y alimenta el buzzer sonoro; cuando la señal se coloca en un estado de alta impedancia, no circula corriente apagando el buzzer sonoro. También se colocó un capacitor de 10 $\mu$F para suavizar el sonido reduciendo los ruidos que puedan entrar por la línea de alimentación. 

\begin{figure}[H]
    \centering
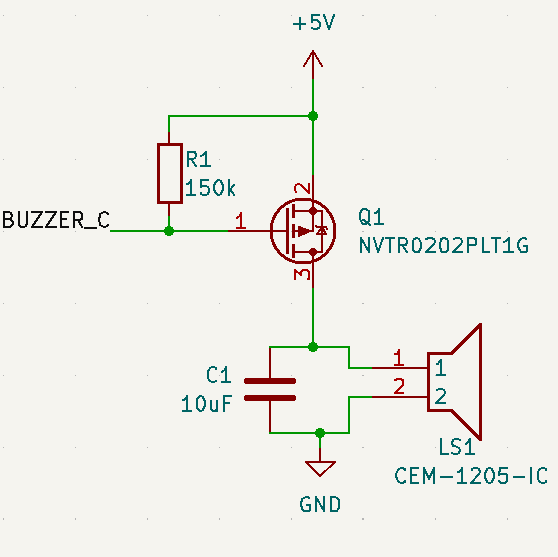
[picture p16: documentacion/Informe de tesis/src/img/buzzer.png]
    
    \caption{Circuito de activación del buzzer sonoro}
    \label{fig:buzzer_sch}
\end{figure}

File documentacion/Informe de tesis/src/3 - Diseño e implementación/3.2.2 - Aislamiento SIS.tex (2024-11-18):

\subsubsection{Aislamiento de los SIS}

El propósito del SAL/T es permitir el movimiento de la formación de una manera segura ante una activación de las interrupciones de los SIS. Para eso, se produce una interacción con los sistemas instrumentados de seguridad en la medición del estado impuesto por los propios SIS, pero también en una imposición de estado por parte del SAL/T. La llave interruptora de los SIS se abre ante una falla o detección de condición insegura en ese SIS. En el caso de ingresar al modo aislado limitado, el sistema va a utilizar las mediciones de estado de cada uno de los SIS y aislar el que esté interrumpiendo la línea; de esta manera, la línea mantiene la continuidad, y el resto de los SIS sigue teniendo la capacidad de interrumpir las señales críticas. Además, cuando se ingresa en modo aislado total o en modo intermitente por comando remoto, o en modo parada total o en modo coche deriva, el SAL/T va a interrumpir las líneas de las señales críticas dejando sin efecto el estado de los SIS. \\    

Para realizar el aislamiento de un SIS, se conectaron las mismas terminales donde se mide el estado del SIS a un relé. Su estado normal es abierto, por lo que no afecta el estado del SIS. Sin embargo, cuando se activa la señal de control del relé por algunos de los motivos mencionados anteriormente, se conectan las señales positiva y negativa de la llave del SIS, forzando un estado de continuidad en la línea. \\ 

Para el relé de aislamiento, se eligió el modelo JW2SN-DC5V de Panasonic Industrial Devices \cite{JW2SN-DC5V}. Este es un relé de potencia que se activa con 5 V en las entradas de control y que cuenta con un arreglo de contacto de 2 salidas tipo C conocido como DPDT (\textit{double-pole double-throw}). En condiciones normales, tiene un consumo de 106 mA al activarse, ya que la resistencia de la bobina interna es de 47 $\Omega$. \\

Se eligió este modelo porque funciona como exacto reemplazo de un relé de seguridad de las mismas características de encapsulamiento y contactos como el V23047A1005A501 de TE Connectivity \cite{V23047A1005A501}. Estos relés de seguridad también son DPDT y activan con 5 VDC. Los relés de seguridad o también conocidos como relé de contactos guiados forzados tienen una configuración y técnica constructiva que cumplen con la norma EN 61810-3 \cite{norma_61810}. Estos relés tienen al menos un par de contactos normal cerrado y otro par normal abierto que están vinculados de manera mecanica lo que hace imposible que ambos estén en contacto simultáneamente; incluso en caso de falla. En la figura \ref{fig:rele_seguridad} se observa el funcionamiento de un relé de seguridad. Este tipo de relé es recomendado para aplicaciones en sistemas críticos porque permite utilizar el contacto primario como actuador, mientras que el contacto secundario se puede utilizar para monitorear su correcto funcionamiento. \\

\begin{figure}[H]
    \centering
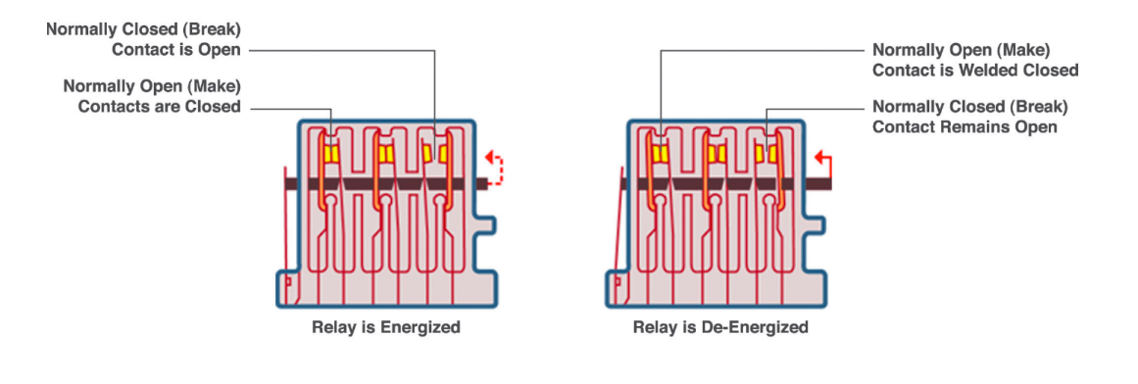
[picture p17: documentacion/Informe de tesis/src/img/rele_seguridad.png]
    
    \caption{Funcionamiento de un relé de seguridad \cite{rele_img}}
    \label{fig:rele_seguridad}
\end{figure}

El modelo utilizado en este prototipo, el JW2SN-DC5V es un relé de uso general, pero se optó por reemplazar el relé de seguridad por este modelo de uso general por la gran diferencia que hay en los costos entre los modelos y considerando que el sistema total hace uso de más de 20 relés. \\

Una de las salidas del JW2SN-DC5V se va a utilizar como actuador y la otra para medir el correcto funcionamiento del relé. Para eso, las salidas del contacto secundario van a estar conectadas una a tierra y la otra a una tensión de 3,3 V y la llave secundaria que conmuta va a estar conectada a una entrada digital del MCU para medir el estado de esa llave. A partir de este estado, el sistema puede determinar luego si hay un estado de error y debe tomar medidas para llevar el sistema a un estado seguro. \\

Para poder energizar el relé con una corriente de poco más de 100 mA es necesario utilizar un \textit{driver} de potencia, ya que la corriente es demasiada alta para drivear directamente desde el MCU además de que la tensión de activación es de 5 V y el MCU tiene salidas digitales de 3,3 V. Considerando que el sistema contempla cinco SIS y cada uno tiene dos llaves interruptoras de posible aislamiento, se diseñó un circuito que contemple un mismo \textit{driver} de potencia para múltiples señales. \\

Se eligió el circuito integrado ULN2003D1013TR de STMicroelectronics \cite{ULN2003D1013TR}. Este CI contiene 7 \textit{drivers} NPN Darlington \cite{darlington} donde cada uno puede manejar hasta 500 mA y soportar tensiones de 50 V. Incluye diodos para cargas inductivas lo que lo hace ideal para controlar relés. Para el aislamiento de los SIS, se van a utilizar 2 ULN2003 para manejar los diez relés de aislamiento. \\

En la figura \ref{fig:sis_aislamiento}, se observa el esquemático del \textit{driver} de potencia ULN2003 y un relé con su salida primaria conectada a los terminales del SIS y la salida secundaria a un pin de entrada del MCU. También se observa que se agregó un LED sobre las entradas de la bobina del relé; esto sirve para identificar el estado del relé durante las pruebas. 

\begin{figure}[H]
    \centering
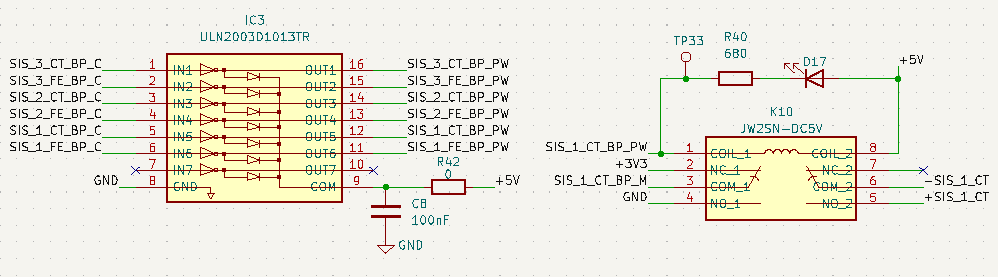
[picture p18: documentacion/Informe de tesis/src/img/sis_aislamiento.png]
    
    \caption{Esquemático del circuito de aislamiento de un SIS}
    \label{fig:sis_aislamiento}
\end{figure}

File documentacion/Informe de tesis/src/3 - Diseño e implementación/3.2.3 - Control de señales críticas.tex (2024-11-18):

\subsubsection{Control de señales críticas}

El SAL/T debe tener la capacidad de controlar directamente las señales críticas de control de tracción (CT) y freno de emergencia (FE). Estas señales son las más críticas que interactúan con el sistema, ya que pueden controlar el movimiento de la formación, bloquearla o permitirle el avance ignorando el estado de todos los SIS. Por estos motivos, se implementó un circuito redundado de mayor seguridad para la activación y corte de estas señales; uno para la señal de CT y otro para la señal de FE como ya se explicó que trabajan con líneas independientes. Este circuito reutiliza los conceptos del prototipo anterior explicados en su informe \cite{salt_ivan}.  \\ 

El circuito de control de las señales críticas cuenta con dos entradas y una salida. Una entrada es la línea de la señal crítica después de haber pasado por las llaves interruptoras de los distintos SIS y de los circuitos de aislamiento de estos (IN); la otra entrada es una alimentación provista por la formación capaz de energizar la electroválvula (ACT); se espera una tensión de entre 72 V y 110 V acorde a la tensión de las baterías del tren; pero al trabajar con relés, solo se va a conectar o desconectar esta señal de la línea y no se va a trabajar en su procesamiento. La salida (OUT) va directamente a la conexión con la electroválvula. En la figura \ref{fig:rele_seguridad} se observa cómo es la configuración del sistema de activación de una señal crítica respecto a los interruptores de los SIS y sus sistemas de aislamiento (expuesto de manera simplificada) y respecto a la electroválvula de la señal crítica; también se muestra el arreglo de tres relés con sus respectivas entradas y salidas mencionadas. 

\begin{figure}[H]
    \centering
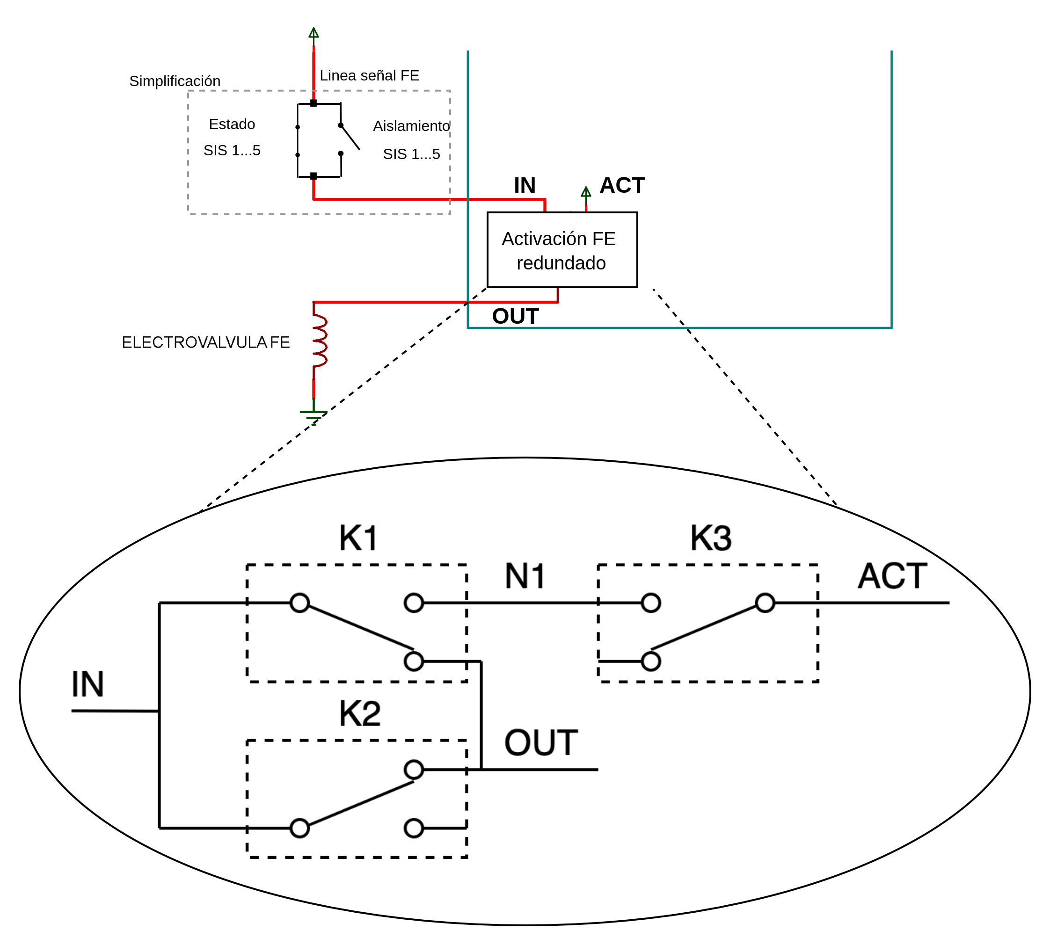
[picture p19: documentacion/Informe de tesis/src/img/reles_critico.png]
    
    \caption{Circuito de relés redundado para activación de señales críticas}
    \label{fig:reles_critico}
\end{figure}

Para estos relés, se utilizó el mismo modelo que para el aislamiento de los SIS (JW2SN-DC5V) pero con la misma consideración de que sirven de reemplazo para relés de seguridad de las mismas características de contactos. Para alimentar estos relés, se utilizó un nuevo driver de potencia ULN2003 que permite activar los seis relés (tres para CT y tres para FE) de estos circuitos. \\ 

Los estados del circuito se pueden resumir de la siguiente manera:

\begin{itemize}
    \item \textbf{Estado normal}: el circuito no modifica la línea de la señal crítica. La entrada IN queda conectada directamente con OUT. La señal de ACT no interviene en la línea. Este estado no realiza ninguna modificación respecto a la línea tradicional sin el SAL/T y debe asegurarse que, ante una falla en el sistema, se imponga este estado dejando la activación de la señal crítica controlada por los SIS. 

    \item \textbf{Activación señal crítica o circuito abierto}: la salida OUT queda desconectada de las entradas IN y ACT. De esta manera, se asegura que el circuito queda abierto y la electroválvula quede sin alimentación lo que fuerza que la señal crítica se ejecuta. Este estado debe forzarse cuando se desea detener la formación activando el freno de emergencia o anulando el control de tracción. 

    \item \textbf{Alimentación forzada o \textit{bypass}}: la salida OUT se conecta directamente con la entrada ACT. De esta manera, la electroválvula queda alimentada independientemente de la tensión en IN y del estado de los SIS de la línea. Este estado es el más crítico porque desactiva todos los SIS de la formación y le permite el movimiento en este estado inseguro. 

\end{itemize}

Para forzar los estados mencionados, se deben controlar los relés considerando que la figura \ref{fig:reles_critico} muestra el estado normal (desenergizado) de cada uno de ellos de acuerdo a la tabla \ref{tab:estado_rele}.

\begin{table}[htb]

    \begin{tabular}{|c|c|} 
        \hline
        \textbf{Estado del circuito} & \textbf{Posición de los relés}\\
        \hline
        Estado normal     &     K1, K2 y K3 desenergizados   \\
        \hline
        Circuito abierto   &     K1 y K2 energizados. K3 desenergizado   \\
        \hline
        \textit{Bypass}   &     K1 y K3 energizados. K2 desenergizado   \\
        \hline
    \end{tabular}
\caption{Posición de relés para los estados del circuito redundado}
\label{tab:estado_rele}
\end{table}

Este sistema aumenta la seguridad de las conexiones, ya que los relés K1 y K2 cumplen una función de redundancia para volver al estado normal. En caso de que alguno de los tres relés falle, esto significa que quede pegado en una posición no deseada, se pueden utilizar los otros dos relés para asegurarse de volver al estado normal donde IN está conectado con OUT. Por ejemplo, si el relé K1 falla y queda pegado conectado al nodo N1, la conexión entre IN y OUT va a seguir existiendo y no se va a generar ningún problema mientras K3 esté desenergizado. Si K2 falla, K1 conecta directamente IN y OUT. Si K3 falla, se mantiene el estado normal, ya que el nodo N1 no participa de este estado. \\ 

Al utilizar relés con dos salidas, una para este circuito de activación y otra para la medición del estado del relé, se puede detectar en todo momento cuando un relé quedó en un estado incorrecto y forzar al SAL/T en un estado de error interno restaurando la conexión normal de las señales críticas.

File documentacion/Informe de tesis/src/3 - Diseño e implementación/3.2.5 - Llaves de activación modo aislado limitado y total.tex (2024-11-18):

\subsubsection{Llaves de activación modo aislado limitado y total}

El SAL/T permite la activación de los modos aislado limitado y modo aislado total de manera local. Para el modo aislado limitado, existe una llave colocada en el panel frontal del dispositivo que va a permitir la activación del modo. Para el modo aislado total, se coloca una llave por fuera del panel frontal, instalada dentro de algún lugar con acceso restringido al maquinista y solo accesible para el personal de mayor autoridad.  \\

La activación de estas llaves altera completamente el funcionamiento de la formación por lo que la correcta lectura de su estado es un requisito importante para el sistema. Por esto se eligió un modelo de llave interruptora bipolar de dos posiciones, ya que cuenta con dos líneas y permite medir el estado en dos entradas diferentes del MCU y asegurarse de leer la posición correcta. El modelo seleccionado es una llave interruptor Bipolar 20 A de dos posiciones de la empresa Elibet \cite{llave_elibet} que se puede visualizar en la figura \ref{fig:llave_mal} y está diseñada para ser colocada en un panel frontal. 

\begin{figure}[H]
    \centering
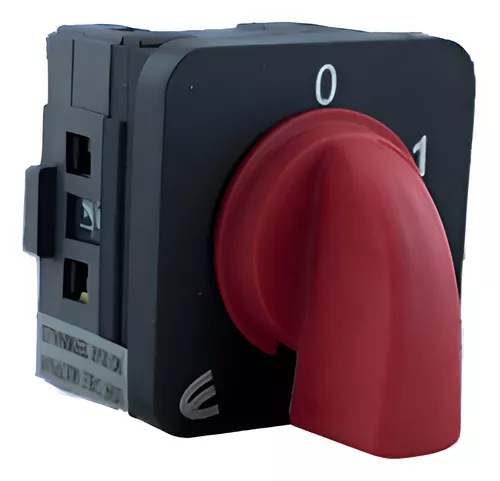
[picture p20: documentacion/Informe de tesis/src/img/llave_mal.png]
    
    \caption{Llave interruptor bipolar 20A Elibet 0-1 posiciones}
    \label{fig:llave_mal}
\end{figure}

En la figura \ref{fig:llave_mal_sch} se muestra el circuito implementado para medir el estado de cada llave. Se conectaron resistencias de \textit{pull-up} de 40.2 k$\Omega$ y se conectaron las entradas de la llave a tierra. Cuando la llave está abierta, las señales que llegan al MCU, ON\_SW\_MAL\_1 y ON\_SW\_MAL\_2 quedan a 3,3 V y el MCU toma esos nodos como entradas digitales por lo que va a detectar un estado alto. Cuando la llave se cierra, los nodos quedan conectados a tierra y el MCU va a leer un estado bajo. En caso de inconsistencia entre los valores leídos entre las dos entradas de una misma llave, se considera el estado de no activación de la llave, ya que es el estado de mayor seguridad y no puede asegurarse el correcto funcionamiento del sistema sin una lectura correcta. 

\begin{figure}[H]
    \centering
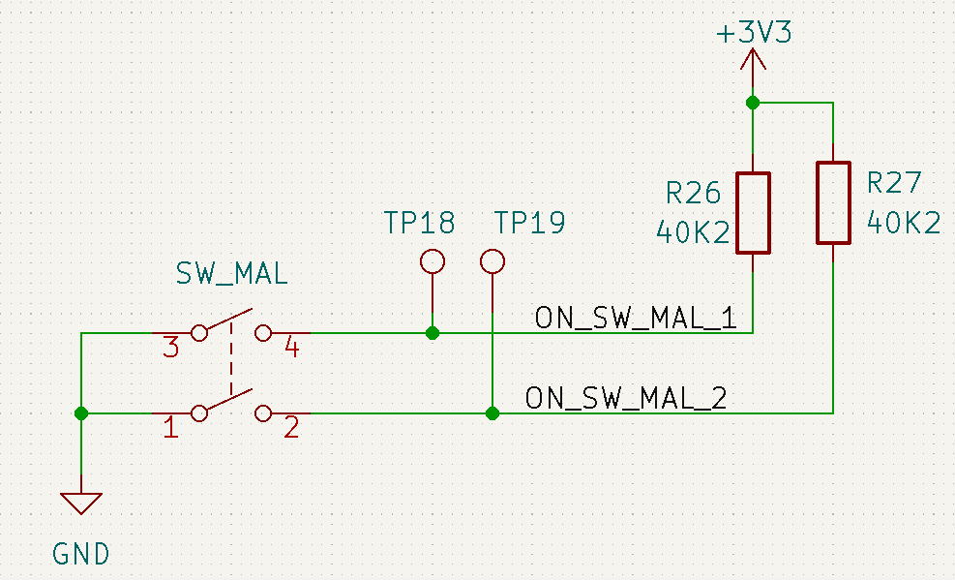
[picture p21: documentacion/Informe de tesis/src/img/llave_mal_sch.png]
    
    \caption{Circuito de lectura del estado de la llave interruptora}
    \label{fig:llave_mal_sch}
\end{figure}

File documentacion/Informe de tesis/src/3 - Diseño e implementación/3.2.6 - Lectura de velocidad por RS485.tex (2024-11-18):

\subsubsection{Lectura de velocidad por RS-485}

El SAL/T cuenta con tres fuentes independientes para medir la velocidad de la formación; dos de ellas provienen de una comunicación por el protocolo RS-485 con otros sistemas de la formación, la tercera proviene del módulo GPS instalado dentro del mismo SAL/T. \\ 

La fuente de medición de velocidad más confiable, y por lo tanto priorizada por el SAL/T, es la indicada por el registrador de eventos Hasler Teloc 1500. La formación cuenta con un generador de pulsos ópticos Hasler que opera en el dominio infrarrojo conectado al registrador de eventos de la formación. Al mismo tiempo, el registrador de eventos está comunicado con un indicador de velocidad que tiene disponible el maquinista \cite{indicador_velocidad}. En la figura \ref{fig:hasler_teloc} se observan los dispositivos presentes en la formación. 

\begin{figure}[H]
    \centering
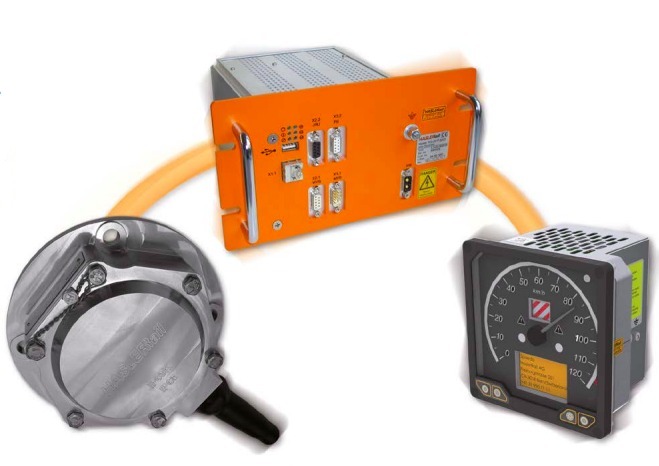
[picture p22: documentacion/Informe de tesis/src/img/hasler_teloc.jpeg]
    
    \caption{Equipamiento Hasler en la formación ferroviaria}
    \label{fig:hasler_teloc}
\end{figure}

En el prototipo anterior del SAL/T, se realizó una tarea de ingeniería inversa para detectar cómo era la comunicación entre el registrador de eventos y el indicador de velocidad para poder interceptar esa señal y utilizar el dato de la velocidad dentro del SAL/T \cite{salt_ivan}. Revisando la documentación del equipo, con la ayuda del personal del laboratorio de material rodante de la estación de Victoria y midiendo las señales en el bus de comunicación entre estos dispositivos, se concluyó que la comunicación utilizaba el protocolo RS-485 \textit{half-duplex} a 115.200 bps. Las pruebas permitieron determinar que la señal cuadrada medida utiliza una tensión de 0,5 V para el estado bajo y de 3,3 V para el estado alto. En reposo, el bus queda en estado alto y la configuración es de 8 bits con un bit extra de stop. La trama enviada está compuesta por paquetes de 31 bytes. En la figura \ref{fig:hasler_trama} se puede observar la medición de un paquete de datos completos realizado en este proceso de descubrimiento. 

\begin{figure}[H]
    \centering
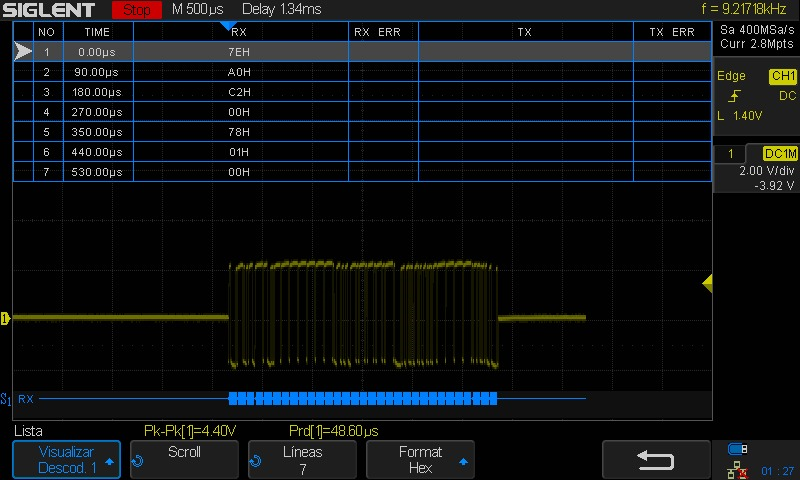
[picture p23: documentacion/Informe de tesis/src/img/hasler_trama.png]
    
    \caption{Trama emitida por el equipo Hasler Teloc 1500}
    \label{fig:hasler_trama}
\end{figure}    

Las tramas empiezan y finalizan con un byte de start y stop, respectivamente, de valor hexadecimal 0x7E. Conociendo el byte de start y stop es más fácil aislar las tramas y analizarlas de manera independiente. Se determinó que la información asociada a la velocidad está expresada en los bytes 7 y 8 (repetida en los bytes 9 y 10) en formato hexadecimal. También, se determinó que los bytes 29 y 30 funcionan como código de redundancia cíclica en la variante CRC-16/IBM-3740 \cite{crc}. El resto de la información contenida en la trama no es relevante para el SAL/T como, por ejemplo, la cantidad de kilómetros recorridos por la formación. \\

Por otro lado, la segunda fuente de medición de velocidad por RS-485 proviene de un circuito que procesa las señales de un generador de impulsos. El generador de impulsos ópticos es un dispositivo que detecta interrupciones de un haz de luz, generalmente producido por un LED, y convierte esos cambios en señales eléctricas. Se utiliza para medir la velocidad o posición de objetos en movimiento, como ruedas o ejes, generando pulsos proporcionales a la rotación o desplazamiento. En la figura \ref{fig:pulse_generator} se puede ver el principio de funcionamiento de este dispositivo. 

\begin{figure}[H]
    \centering
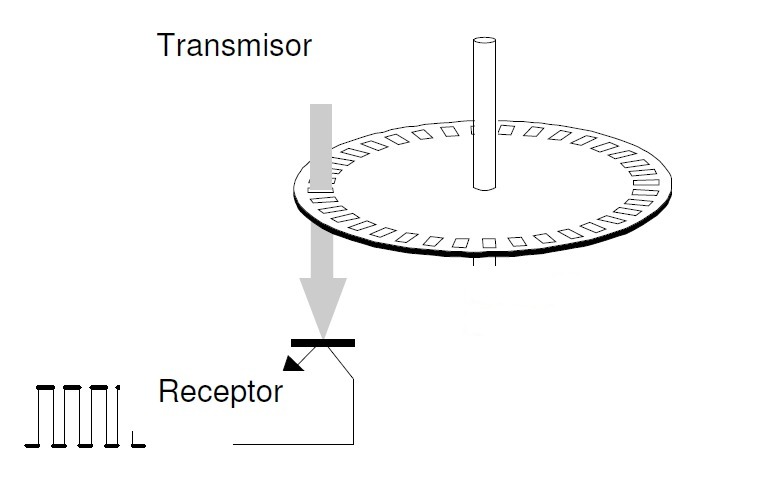
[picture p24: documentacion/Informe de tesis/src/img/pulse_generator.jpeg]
    
    \caption{Principio de funcionamiento de un generador de impulsos ópticos}
    \label{fig:pulse_generator}
\end{figure}    

Para determinar la velocidad a partir de la señal eléctrica, un sistema con un microcontrolador que tiene previamente configuradas algunas características del generador óptico y de la formación (números de pulsos por revolución, diámetro o circunferencia de la rueda) debe considerar la frecuencia de los pulsos así como el tiempo entre pulsos para una medición más precisa de la velocidad instantánea. Una vez determinada la velocidad, este sistema externo va a montar el dato sobre un bus RS-485 que se va a conectar con el SAL/T comunicando directamente el dato de la velocidad. \\ 

Dentro del SAL/T se incluyeron dos circuitos para realizar la conversión entre el protocolo RS-485 y las interfaces UART del MCU. Para armar este circuito, se tomó como referencia el circuito del mismo propósito incluido en la placa EDU-CIAA-NXP \cite{edu-ciaa}. El circuito está basado en el chip SN65HVD1176DR de Texas Instruments \cite{SN65HVD1176DR}; este es un  transceptor diferencial que trabaja en \textit{half-duplex} con características optimizadas para su uso en aplicaciones PROFIBUS \cite{profibus}. El voltaje diferencial de salida del controlador supera los requisitos de PROFIBUS de 2,1 V con una carga de 54 Ω. Una tasa de señalización de hasta 40 Mbps permite un crecimiento tecnológico hacia velocidades altas de transferencia de datos. La baja capacitancia del bus reduce la distorsión de la señal. \\

El circuito se muestra en la figura \ref{fig:rs485_sch} y se observa en la entrada las señales de recepción y transmisión que se conectan al MCU así como un pin de salida digital que selecciona si se van a transmitir o recibir datos ya que es un sistema \textit{half-duplex} y se comparte el bus para ambas transmisiones. Se observan también dos capacitores de desacople conectados en la alimentación del circuito integrado. Del lado de la salida se colocaron las resistencias de 390 $\Omega$ y 220 $\Omega$ conocidas como \textit{bias resistors} en las recomendaciones de PROFIBUS. Por otro lado, se colocaron los \textit{jumpers} JP6, JP7 y JP8 que deben ser cortocircuitados en caso de ser el último nodo de la red. También se colocó la resistencia R22 de 100 $\Omega$ para conectar la tierra y disipar cualquier pequeña diferencia de tensión que pueda haber entre las distintas tierras de los dispositivos conectada de acuerdo a la nota de aplicación de Texas Instruments SLLA070D \cite{rs485}; esto permite reducir el ruido de modo común en las líneas de transmisión. El circuito también utiliza el diodo supresor de transitorios (TVS) modelo SZP6SMB12CAT3G de Littelfuse \cite{SZP6SMB12CAT3G} diseñado para proteger componentes electrónicos sensibles de picos de voltaje y transitorios y el fusible reajustable MF-USMF020-2 de Bourns \cite{MF-USMF020-2} diseñado para proteger circuitos electrónicos contra sobrecorrientes. A diferencia de los fusibles tradicionales, este dispositivo puede ser reajustado manualmente después de que se ha activado, lo que proporciona una solución más conveniente y económica.

\begin{figure}[H]
    \centering
    
    \caption{Circuito conversor entre protocolos UART y RS-485}
    \label{fig:rs485_sch}
\end{figure}

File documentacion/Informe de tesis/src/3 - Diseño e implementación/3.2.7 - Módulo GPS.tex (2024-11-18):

\subsubsection{Módulo GPS}

El sistema utiliza el módulo GPS GY-NEO6MV2 para determinar la posición y velocidad del material rodante. Este módulo basado en el chip NEO-6M se alimenta con 5 V y permite la comunicación con el MCU a través de una interfaz UART. Sin embargo, no cuenta con una entrada de reset y a partir de experiencias previas de otros proyectos con módulos de estas características, se decidió armar un circuito de reset externo por en caso de detectar un error o falla en el funcionamiento del módulo. \\ 

El circuito de reset utilizado se puede observar en la figura \ref{fig:gps_sch} y utiliza el transistor MOSFET de canal P SI2343DS-T1-E3 de Vishay Semiconductors \cite{SI2343DS-T1-E3} diseñado para aplicaciones de conmutación y  control de carga en circuitos de baja potencia. Tiene una baja resistencia de encendido Rds(on) lo que permite generar una pequeña caída de tensión respecto a los 5 V que se buscan llevar al módulo. Para polarizar el circuito y permitir la circulación de corriente para encender el módulo, se debe forzar la entrada GPS\_PW\_ON a su estado bajo de 0 V. Para cortar la circulación de corriente y apagar el módulo, se debe colocar la entrada en estado de alta impedancia; esto se logra configurándolo como un pin de entrada.\\ 

\begin{figure}[H]
    \centering
    
    \caption{Circuito de reset del módulo GPS}
    \label{fig:gps_sch}
\end{figure}    

Además, se agregó un LED con su respectiva resistencia para indicar cuando el módulo está alimentado y cuando no lo está, ya que el módulo no trae integrado ningún indicador luminoso. También se colocaron dos capacitores de desacople, uno electrolítico de 10 $\mu$F y otro cerámico de 100 nF para filtrar los ruidos que pueda haber en la línea de alimentación considerando también que es un módulo que trabaja con altas frecuencias y genera mayor ruido.

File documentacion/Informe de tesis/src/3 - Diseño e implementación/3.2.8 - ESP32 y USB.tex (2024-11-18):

\subsubsection{Módulo Wi-Fi y alimentación USB}

La comunicación del SALT con la central operativa de control se realiza utilizando la red de Internet. Para lograr esa comunicación, se utilizó el módulo ESP32 Devkit-C que tiene la capacidad de conectarse a una red Wi-Fi. Este módulo permite su alimentación con 5 V ya que tiene un regulador interno que alimenta el MCU interno con 3,3 V. La interfaz con el SAL/T se realiza mediante el protocolo UART y se utiliza un pin GPIO para el pin de EN (\textit{enable}) que trae el módulo, lo que permite forzar un reset del módulo ante cualquier falla detectada. Para facilitar la programación y el manejo de este módulo, se colocó en la placa principal un zócalo que permita insertar y remover el módulo sin necesidad de soldarlo a la placa. \\
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

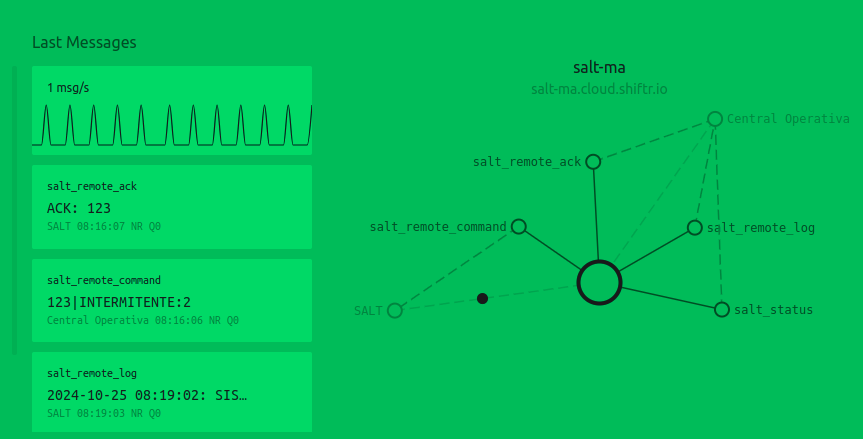
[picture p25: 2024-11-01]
documentacion/Informe de tesis/src/img/shiftrio.png

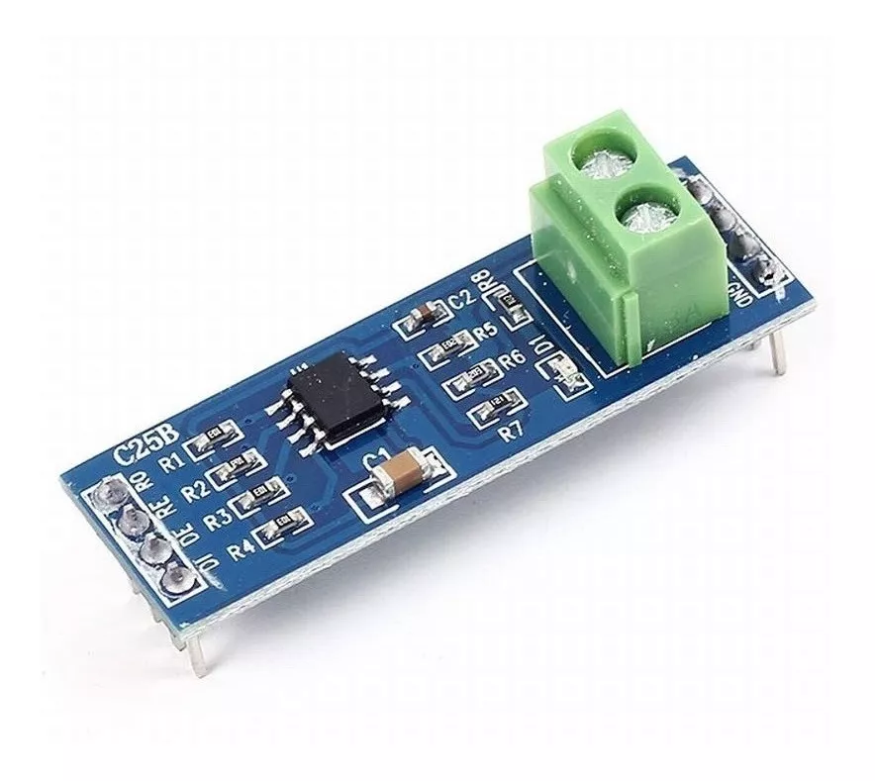
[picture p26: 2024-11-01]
documentacion/Informe de tesis/src/img/conversor_uart_rs485.png

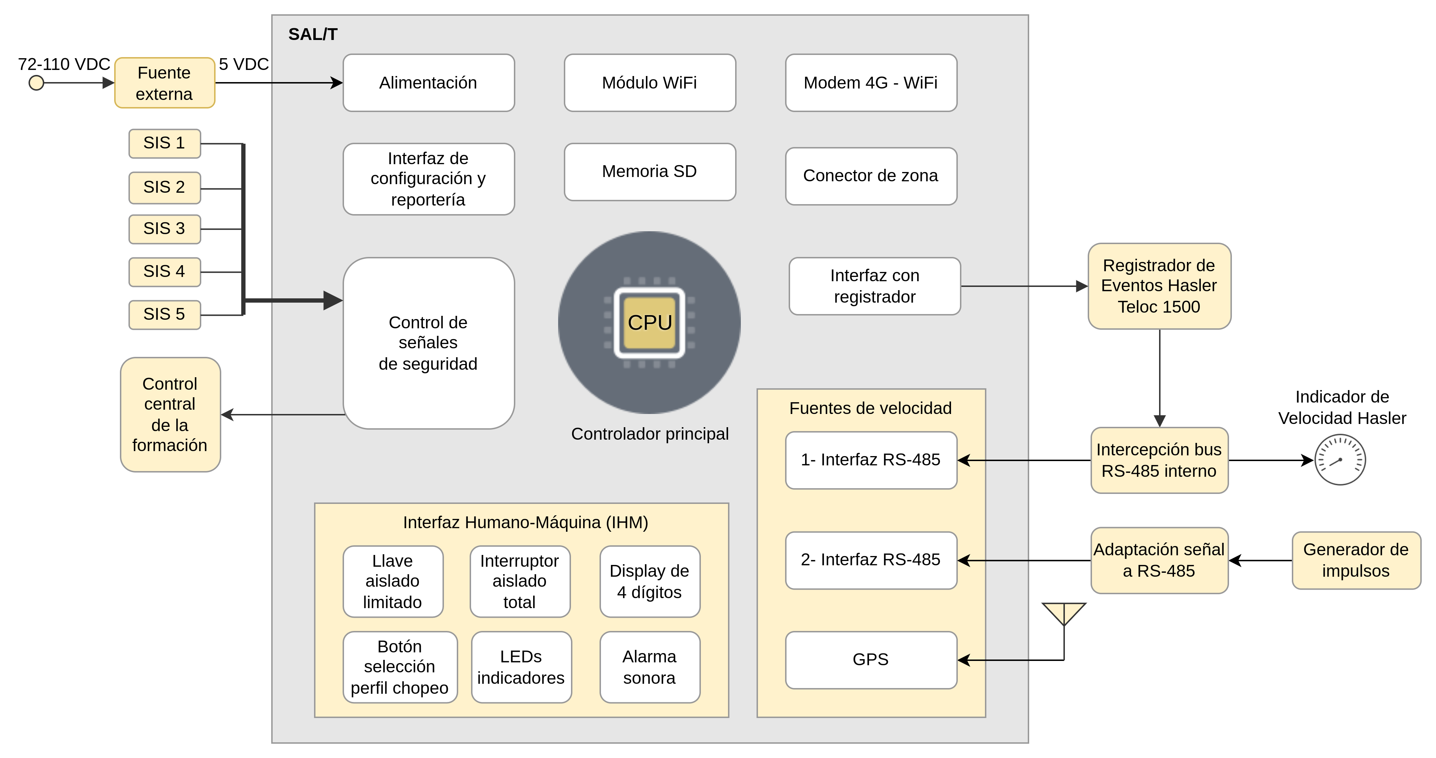
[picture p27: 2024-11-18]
documentacion/Informe de tesis/src/img/diagrama_bloques.png

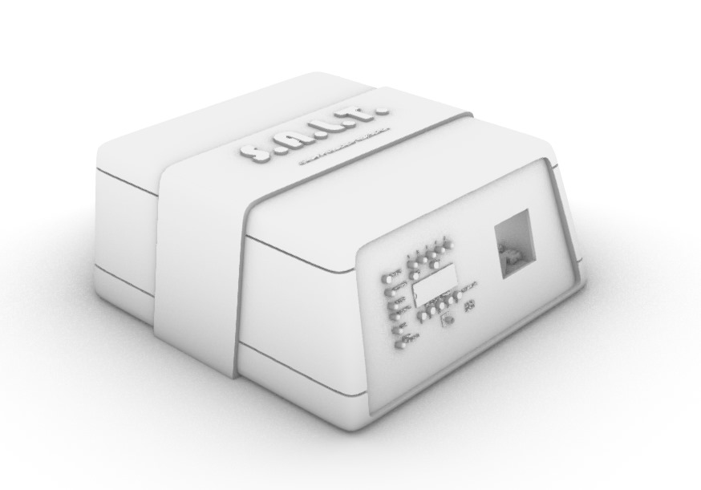
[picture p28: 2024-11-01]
documentacion/Informe de tesis/src/img/gabinete.jpeg

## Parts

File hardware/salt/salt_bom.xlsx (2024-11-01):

Total PWR | Unit PWR | Item Price | Unit Price | Item | Qty | Reference(s) | Value | LibPart | Footprint | Datasheet | Manufacturer_Name | Manufacturer_Part_Number | Mouser Part Number | Mouser Price/Stock
0 | 0 | 1.75 | 0.35 | 1 | 5 | C1, C2, C7, C31, C32 | 10uF | salt:C_10uF | Capacitor_SMD:C_0805_2012Metric_Pad1.18x1.45mm_HandSolder | https://ar.mouser.com/datasheet/2/447/KEM_C1002_X7R_SMD-3316098.pdf | KEMET | C1206C106K4RACTU | 80-C1206C106K4R | https://ar.mouser.com/ProductDetail/KEMET/C1206C106K4RACTU?qs=guDyKOyRtV0mxqxQedB7kA%3D%3D
0 | 0 | 3.5 | 0.14 | 2 | 25 | C3, C4, C6, C8, C11, C12, C13, C14, C15, C16, C17, C18, C19, C20, C21, C22, C23, C24, C25, C26, C27, C28, C29, C30, C33 | 100nF | salt:C_100nF | Capacitor_SMD:C_0805_2012Metric_Pad1.18x1.45mm_HandSolder | https://ar.mouser.com/datasheet/2/447/KEM_C1002_X7R_SMD-3316098.pdf | KEMET | C0805C104K4RACTU | 80-C0805C104K4R | https://ar.mouser.com/ProductDetail/KEMET/C0805C104K4RACTU?qs=Pc30aiB8zWWfqQNJWggt%252BA%3D%3D
0 | 0 | 1.134 | 0.378 | 3 | 3 | C5, C9, C10 | 10uF | salt:C_pol_10uF | salt:EEE1AA220WR | http://industrial.panasonic.com/cdbs/www-data/pdf/RDE0000/ABA0000C1148.pdf | Panasonic | EEE-HAV100WAR | 667-EEE-HAV100WAR | https://www.mouser.co.uk/ProductDetail/Panasonic/EEE-HAV100WAR?qs=d1CqaRUMZD9R0%252BkBpBLRUg%3D%3D
0 | 0 | 2.58 | 0.43 | 4 | 6 | D1, D2, D3, D4, D5, D6 | SZP6SMB12CAT3G | salt:SZP6SMB12CAT3G | salt:DIOM5436X247N | https://www.littelfuse.com/~/media/electronics/datasheets/tvs_diodes/littelfuse_tvs_diode_szp6smb_datasheet.pdf.pdf | LITTELFUSE | SZP6SMB12CAT3G | 863-SZP6SMB12CAT3G | https://www.mouser.co.uk/ProductDetail/Littelfuse/SZP6SMB12CAT3G?qs=sK5eIuwOod79VxlBvAdu3Q%3D%3D
193.6 | 8.8 | 4.114 | 0.187 | 5 | 22 | D7, D8, D9, D10, D11, D12, D13, D14, D15, D16, D17, D18, D19, D20, D21, D22, D23, D24, D25, D26, D27, D28 | LED | salt:LED | LED_SMD:LED_0805_2012Metric_Pad1.15x1.40mm_HandSolder | https://www.we-online.com/catalog/datasheet/150080VS75000.pdf | Wurth Elektronik | 150080VS75000 | 710-150080VS75000 | https://ar.mouser.com/ProductDetail/Wurth-Elektronik/150080VS75000?qs=LlUlMxKIyB0tGHJmO6%252B0ug%3D%3D
75 | 75 | 2.99 | 2.99 | 6 | 1 | DS1 | LTC-5723HR | salt:LTC-5723HR | salt:DIP1524W75P254L5030H825Q12N | https://componentsearchengine.com/Datasheets/1/LTC-5723HR.pdf | Lite-On | LTC-5723HR | 859-LTC-5723HR | https://www.mouser.co.uk/ProductDetail/Lite-On/LTC-5723HR?qs=WxFF5lh7QM2ytJdX1EhJKQ%3D%3D
0 | 0 | 1.36 | 0.34 | 7 | 4 | F1, F2, F3, F4 | MF-USMF020-2 | salt:MF-USMF020-2 | salt:FUSC3226X110N | https://www.bourns.com/docs/Product-Datasheets/mfusmf.pdf | Bourns | MF-USMF020-2 | 652-MF-USMF020-2 | https://www.mouser.co.uk/ProductDetail/Bourns/MF-USMF020-2?qs=vF78I%252BjhbY80Iv10TNGu8Q%3D%3D
1 | 1 | 0.75 | 0.75 | 8 | 1 | IC1 | SI2343DS-T1-E3 | salt:SI2343DS-T1-E3 | salt:SOT95P237X112-3N | https://www.vishay.com/docs/72079/si2343ds.pdf | Vishay | SI2343DS-T1-E3 | 781-SI2343DS-T1-E3 | https://www.mouser.co.uk/ProductDetail/Vishay-Semiconductors/SI2343DS-T1-E3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
80 | 20 | 2.908 | 0.727 | 9 | 4 | IC2, IC3, IC4, IC5 | ULN2003D1013TR | salt:ULN2003D1013TR | salt:SOIC127P600X175-16N | http://www.st.com/st-web-ui/static/active/en/resource/technical/document/datasheet/CD00001244.pdf | STMicroelectronics | ULN2003D1013TR | 511-ULN2003D1013TR | https://www.mouser.co.uk/ProductDetail/STMicroelectronics/ULN2003D1013TR?qs=YnPipOpXm6FQ98RZGZk5Pg%3D%3D
10 | 1 | 23.5 | 2.35 | 10 | 10 | IC6, IC8, IC9, IC10, IC11, IC12, IC13, IC14, IC15, IC16 | INA823DGKR | salt:INA823DGKR | salt:Texas_Instruments-DGK0008A-0-0-MFG | https://www.ti.com/lit/ds/symlink/ina823.pdf | Texas Instruments | INA823DGKR | 595-INA823DGKR | https://ar.mouser.com/ProductDetail/Texas-Instruments/INA823DGKR?qs=Rp5uXu7WBW%252BTcPLLKQJgaw%3D%3D
0.5 | 0.5 | 2.03 | 2.03 | 11 | 1 | IC7 | ICL7660AIBAZA | salt:ICL7660AIBAZA | salt:SOIC127P600X175-8N | https://www.renesas.com/en-us/www/doc/datasheet/icl7660s-a.pdf | Renesas Electronics | ICL7660AIBAZA | 968-ICL7660AIBAZA | https://www.mouser.co.uk/ProductDetail/Renesas-Intersil/ICL7660AIBAZA?qs=9fLuogzTs8J5iyJZPJ0POQ%3D%3D
2 | 2 | 6.58 | 6.58 | 12 | 1 | IC17 | AS1115-BSST | salt:AS1115-BSST | salt:SOP64P600X175-24N | https://datasheet.datasheetarchive.com/originals/distributors/Datasheets-SFU1/DSASFU10002655.pdf | ams | AS1115-BSST | 985-AS1115-BSST | https://www.mouser.co.uk/ProductDetail/ams/AS1115-BSST?qs=jMXWnm70%252BC%2FTIBNsbFwa8Q%3D%3D
0 | 0 | 10.56 | 1.32 | 13 | 8 | J1, J2, J3, J4, J5, J6, J7, J23 | 1757491 | salt:1757491 | salt:1757491 | http://www.phoenixcontact.com/de/produkte/1757491/pdf | Phoenix Contact | 1757491 | 651-1757491 | https://www.mouser.co.uk/ProductDetail/Phoenix-Contact/1757491?qs=ibOxrZ%2Fd8eB4FBuHWRXg5w%3D%3D
0 | 0 | 11.66 | 1.06 | 14 | 11 | J8, J9, J12, J13, J14, J15, J16, J17, J18, J19, J20 | 1757488 | salt:1757488 | salt:1757488 | http://www.phoenixcontact.com/de/produkte/1757488/pdf | Phoenix Contact | 1757488 | 651-1757488 | https://www.mouser.co.uk/ProductDetail/Phoenix-Contact/1757488?qs=%2FbRkJSLTVS%2Fze3R%2FaBR5ug%3D%3D
0 | 0 | 2.14 | 1.07 | 15 | 2 | J10, J11 | USB_A | salt:USB_A | salt:875832010BLF | https://ar.mouser.com/datasheet/2/18/1/87583-2579162.pdf | Amphenol FCI | 87583-2010BLF | 649-87583-2010BLF | https://ar.mouser.com/ProductDetail/Amphenol-FCI/87583-2010BLF?qs=nBv%252BRDKgYU1zL2s5V%2F8s6w%3D%3D
0 | 0 | 2.63 | 2.63 | 16 | 1 | J21 | DM3AT-SF-PEJM5 | salt:DM3AT-SF-PEJM5 | salt:DM3ATSFPEJM5 | https://datasheet.lcsc.com/szlcsc/Hirose-HRS-DM3AT-SF-PEJM5_C114218.pdf | Hirose | DM3AT-SF-PEJM5 | 798-DM3AT-SF-PEJM5 | https://www.mouser.co.uk/ProductDetail/Hirose-Connector/DM3AT-SF-PEJM5?qs=LZSZKJVF%252B2WTDKp%252BR7IYAQ%3D%3D
0 | 0 | 0.73 | 0.73 | 17 | 1 | J22 | 1757475 | salt:1757475 | salt:1757475 | http://www.phoenixcontact.com/de/produkte/1757475/pdf | Phoenix Contact | 1757475 | 651-1757475 | https://www.mouser.co.uk/ProductDetail/Phoenix-Contact/1757475?qs=%2FbRkJSLTVS8mvc1VFuPCFA%3D%3D
0 | 0 | 3.04 | 0.38 | 18 | 8 | JP1, JP2, JP3, JP4, JP5, JP6, JP7, JP8 | Jumper_2_Bridged | salt:Jumper | Connector_PinHeader_2.54mm:PinHeader_1x02_P2.54mm_Vertical | ~ | SparkFun | PRT-09044 | 474-PRT-09044 | https://ar.mouser.com/ProductDetail/SparkFun/PRT-09044?qs=WyAARYrbSnZhF3ceVBeBOA%3D%3D
11130 | 530 | 44.1 | 2.1 | 19 | 21 | K1, K2, K3, K4, K5, K6, K7, K8, K9, K10, K11, K12, K13, K14, K15, K16, K17, K18, K19, K20, K21 | JW2SN-DC5V | salt:JW2SN-DC5V | salt:JW2SNDC5V | https://www3.panasonic.biz/ac/e_download/control/relay/power/catalog/mech_eng_jw.pdf | Panasonic | JW2SN-DC5V | 769-JW2SN-DC5V | https://www.mouser.co.uk/ProductDetail/Panasonic-Industrial-Devices/JW2SN-DC5V?qs=HLLy2pIPwuus9vgayzgjwA%3D%3D
44.8 | 5.6 | 2.888 | 0.361 | 20 | 8 | LED1, LED2, LED3, LED4, LED5, LED6, LED7, LED8 | WP7113LZGCK | salt:WP7113LZGCK | salt:WP7113LZGCK | https://www.mouser.com/datasheet/2/216/WP7113LZGCK-535810.pdf | Kingbright | WP7113LZGCK | 604-WP7113LZGCK | https://www.mouser.com/ProductDetail/Kingbright/WP7113LZGCK?qs=6oMev5NRZME0vaccujctkg%3D%3D
660 | 66 | 13.6 | 1.36 | 21 | 10 | LED9, LED10, LED11, LED12, LED13, LED14, LED15, LED16, LED17, LED18 | WP154A4SEJ3VBDZGW_CA | salt:WP154A4SEJ3VBDZGW_CA | salt:L-154A4SUREQBFZGEC | http://www.kingbrightusa.com/images/catalog/SPEC/WP154A4SEJ3VBDZGW-CA.pdf | Kingbright | WP154A4SEJ3VBDZGW/CA | 604-WP154A43VBDZGWCA | https://www.mouser.co.uk/ProductDetail/Kingbright/WP154A4SEJ3VBDZGW-CA?qs=YCa%2FAAYMW01xRqZww6UuiQ%3D%3D
150 | 150 | 1.91 | 1.91 | 22 | 1 | LS1 | CEM-1205-IC | salt:CEM-1205-IC | salt:CEM1205IC | https://www.cuidevices.com/product/resource/cem-1205-ic.pdf | CUI Devices | CEM-1205-IC | 490-CEM1205IC | https://www.mouser.co.uk/ProductDetail/CUI-Devices/CEM-1205-IC?qs=hd1VzrDQEGhFNAzregGKGQ%3D%3D
1 | 1 | 0.378 | 0.378 | 23 | 1 | Q1 | NVTR0202PLT1G | salt:NVTR0202PLT1G | salt:SOT96P237X111-3N | https://componentsearchengine.com/Datasheets/2/NVTR0202PLT1G.pdf | onsemi | NVTR0202PLT1G | 863-NVTR0202PLT1G | https://www.mouser.co.uk/ProductDetail/onsemi/NVTR0202PLT1G?qs=3PKVEWFFm29UPkq%2FAwGemg%3D%3D
13.8 | 2.3 | 0.6 | 0.1 | 24 | 6 | R1, R2, R3, R4, R5, R6 | 4k7 | salt:R_4K7 | Resistor_SMD:R_0805_2012Metric_Pad1.20x1.40mm_HandSolder | https://ar.mouser.com/datasheet/2/447/PYu_RC_Group_51_RoHS_L_11-1984063.pdf | YAGEO | RC0805FR-104K7L | 603-RC0805FR-104K7L | https://ar.mouser.com/ProductDetail/YAGEO/RC0805FR-104K7L?qs=m6lXFsvg5e3qsGC2wfapPw%3D%3D
0 | 0 | 0 | 0 | 25 | 9 | R9, R10, R24, R26, R32, R43, R49, R52, R59 | 0 | salt:R_0 | Resistor_SMD:R_0805_2012Metric_Pad1.20x1.40mm_HandSolder
10 | 2.5 | 0.4 | 0.1 | 26 | 4 | R11, R12, R13, R14 | 100k | :R_100K_3 | Resistor_SMD:R_0805_2012Metric_Pad1.20x1.40mm_HandSolder | https://ar.mouser.com/datasheet/2/447/YAGEO_PYu_RC_Group_51_RoHS_L_12-3313492.pdf | YAGEO | RC0805FR-10100KL | RC0805FR-10100KL | https://ar.mouser.com/ProductDetail/YAGEO/RC0805FR-10100KL?qs=g6xwsc4j%252B%2FqVNq2KE2UHnA%3D%3D
36 | 9 | 0.4 | 0.1 | 27 | 4 | R15, R17, R18, R20 | 390 | salt:R_390 | Resistor_SMD:R_0805_2012Metric_Pad1.20x1.40mm_HandSolder | https://ar.mouser.com/datasheet/2/447/YAGEO_PYu_RC_Group_51_RoHS_L_12-3313492.pdf | YAGEO | RC0805FR-07390RL | 603-RC0805FR-07390RL | https://ar.mouser.com/ProductDetail/YAGEO/RC0805FR-07390RL?qs=KCkj9j0IqmWY8N7pYtjFNQ%3D%3D
40 | 20 | 0.2 | 0.1 | 28 | 2 | R16, R19 | 220 | salt:R_220 | Resistor_SMD:R_0805_2012Metric_Pad1.20x1.40mm_HandSolder | https://ar.mouser.com/datasheet/2/447/PYu_RC_Group_51_RoHS_L_11-1984063.pdf | YAGEO | RC0805FR-13220RL | 603-RC0805FR-13220RL | https://ar.mouser.com/ProductDetail/YAGEO/RC0805FR-13220RL?qs=m6lXFsvg5e2iBXKHbsJECg%3D%3D
6 | 2 | 0.048 | 0.016 | 29 | 3 | R21, R22, R101 | 100 | salt:R_100 | Resistor_SMD:R_0805_2012Metric_Pad1.20x1.40mm_HandSolder | https://ar.mouser.com/datasheet/2/447/PYu_RC_Group_51_RoHS_L_11-1984063.pdf | YAGEO | RC0805FR-10100RL | 603-RC0805FR-10100RL | https://ar.mouser.com/ProductDetail/YAGEO/RC0805FR-10100RL?qs=g6xwsc4j%252B%2FoYV9cxut0j6Q%3D%3D
4 | 2 | 0.2 | 0.1 | 30 | 2 | R23, R100 | 150k | salt:R_150K | Resistor_SMD:R_0805_2012Metric_Pad1.20x1.40mm_HandSolder | https://ar.mouser.com/datasheet/2/447/PYu_RC_Group_51_RoHS_L_11-1984063.pdf | YAGEO | RC0805FR-13150KL | 603-RC0805FR-13150KL | https://ar.mouser.com/ProductDetail/YAGEO/RC0805FR-13150KL?qs=m6lXFsvg5e2Mp%2Fy7W%252BnUqg%3D%3D
96.8 | 4.4 | 2.2 | 0.1 | 31 | 22 | R25, R27, R28, R29, R30, R31, R37, R38, R39, R40, R41, R42, R44, R45, R46, R47, R48, R53, R54, R56, R57, R58 | 680 | salt:R_680 | Resistor_SMD:R_0805_2012Metric_Pad1.20x1.40mm_HandSolder | https://ar.mouser.com/datasheet/2/447/PYu_RC_Group_51_RoHS_L_11-1984063.pdf | YAGEO | RC0805FR-13680RL | 603-RC0805FR-13680RL | https://ar.mouser.com/ProductDetail/YAGEO/RC0805FR-13680RL?qs=m6lXFsvg5e3C9RY8lrBC%2Fw%3D%3D
5 | 1 | 0.5 | 0.1 | 32 | 5 | R33, R34, R35, R36, R104 | 40K2 | salt:R_40K2 | Resistor_SMD:R_0805_2012Metric_Pad1.20x1.40mm_HandSolder | https://ar.mouser.com/datasheet/2/447/YAGEO_PYu_RC_Group_51_RoHS_L_12-3313492.pdf | YAGEO | RC0805FR-0740K2L | 603-RC0805FR-0740K2L | https://ar.mouser.com/ProductDetail/YAGEO/RC0805FR-0740K2L?qs=QrWOOBGzeCbZpVapvyHnwA%3D%3D
3 | 1 | 0.3 | 0.1 | 33 | 3 | R50, R51, R55 | 56k | salt:R_56K | Resistor_SMD:R_0805_2012Metric_Pad1.20x1.40mm_HandSolder | https://ar.mouser.com/datasheet/2/447/PYu_RC_Group_51_RoHS_L_11-1984063.pdf | YAGEO | RC0805FR-1056KL | 603-RC0805FR-1056KL | https://ar.mouser.com/ProductDetail/YAGEO/RC0805FR-1056KL?qs=qpJ%252B%252B%252Bdg6p0DFLmy599hAw%3D%3D
240 | 12 | 2 | 0.1 | 34 | 20 | R60, R61, R64, R65, R68, R69, R70, R71, R72, R73, R74, R75, R84, R85, R86, R87, R88, R89, R90, R91 | 1M | salt:R_1M | Resistor_SMD:R_0805_2012Metric_Pad1.20x1.40mm_HandSolder | https://ar.mouser.com/datasheet/2/447/PYu_RC_Group_51_RoHS_L_11-1984063.pdf | YAGEO | RC0805FR-101ML | 603-RC0805FR-101ML | https://ar.mouser.com/ProductDetail/YAGEO/RC0805FR-101ML?qs=g6xwsc4j%252B%2FquvT%252BzGahIFg%3D%3D
20 | 1 | 2 | 0.1 | 35 | 20 | R62, R63, R66, R67, R76, R77, R78, R79, R80, R81, R82, R83, R92, R93, R94, R95, R96, R97, R98, R99 | 30k | salt:R_30K | Resistor_SMD:R_0805_2012Metric_Pad1.20x1.40mm_HandSolder | https://ar.mouser.com/datasheet/2/447/YAGEO_PYu_RC_Group_51_RoHS_L_12-3313492.pdf | YAGEO | RC0805FR-0730KL | 603-RC0805FR-0730KL | https://ar.mouser.com/ProductDetail/YAGEO/RC0805FR-0730KL?qs=QrWOOBGzeCbwE5CbPpR7Pw%3D%3D
2.4 | 1.2 | 0.2 | 0.1 | 36 | 2 | R102, R103 | 22k | salt:R_22K | Resistor_SMD:R_0805_2012Metric_Pad1.20x1.40mm_HandSolder | https://ar.mouser.com/datasheet/2/447/PYu_RC_Group_51_RoHS_L_11-1984063.pdf | YAGEO | RC0805FR-1022KL | 603-RC0805FR-1022KL | https://ar.mouser.com/ProductDetail/YAGEO/RC0805FR-1022KL?qs=m6lXFsvg5e37y4fr%252BWohrg%3D%3D
0 | 0 | 0 | 0 | 37 | 76 | TP1, TP2, TP3, TP4, TP5, TP6, TP7, TP8, TP9, TP10, TP11, TP12, TP13, TP14, TP15, TP16, TP17, TP18, TP19, TP20, TP21, TP22, TP23, TP24, TP25, TP26, TP27, TP28, TP29, TP30, TP31, TP32, TP33, TP34, TP35, TP36, TP37, TP38, TP39, TP40, TP41, TP42, TP43, TP44, TP45, TP46, TP47, TP48, TP49, TP50, TP51, TP52, TP53, TP54, TP55, TP56, TP57, TP58, TP59, TP60, TP61, TP62, TP63, TP64, TP65, TP66, TP67, TP68, TP69, TP70, TP71, TP72, TP73, TP74, TP75, TP76 | TestPoint | salt:TestPoint | salt:testpoint | ~
0 | 0 | 1.21 | 1.21 | 38 | 1 | S1 | 1543-650-149 | salt:1543-650-149 | salt:1543650149 | https://www.arrow.com/en/products/1543-650-149/bourns | Bourns | 1543-650-149 | 652-1543-650-149 | https://www.mouser.co.uk/ProductDetail/Bourns/1543-650-149?qs=2f2kQrcl%2FoiIszYh%252BBIYwA%3D%3D
500 | 500 | 24.47 | 24.47 | 39 | 1 | U1 | NUCLEO-F429ZI | :NUCLEO-F429ZI_1 | salt:MODULE_NUCLEO-F429ZI | https://ar.mouser.com/datasheet/2/389/nucleo_l496zg-1848160.pdf | STMicroelectronics | NUCLEO-F429ZI | 511-NUCLEO-F429ZI | https://ar.mouser.com/ProductDetail/STMicroelectronics/NUCLEO-F429ZI?qs=mKNKSX85ZJcE6FU0UkiXTA%3D%3D
60 | 30 | 5.88 | 2.94 | 40 | 2 | U2, U3 | SN65HVD1176DR | salt:SN65HVD1176DR | salt:SOIC127P600X175-8N | http://www.ti.com/lit/gpn/sn65hvd1176 | Texas Instruments | SN65HVD1176DR | 595-SN65HVD1176DR | https://www.mouser.co.uk/ProductDetail/Texas-Instruments/SN65HVD1176DR?qs=QViXGNcIEAsAVZ5iRsO8EQ%3D%3D
500 | 500 | 13.48 | 13.48 | 41 | 1 | U4 | Módulo GPS GY-GPS6MV2 | salt:GY-GPS6MV2 | salt:GY-NEO6MV2 | https://www.datasheethub.com/gy-neo6mv2-flight-control-gps-module/ | u-Blox | GPS GY-NEO6MV2 |  | https://www.todomicro.com.ar/investigacion-desarrollo-y-prototipado/339-modulo-gps-gy-neo6mv2-con-antena.html
500 | 500 | 13.87 | 13.87 | 42 | 1 | U5 | ESP32-DEVKITC-32 | salt:ESP32-DEVKITC-32 | salt:MODULE_ESP32-DEVKITC-32 | https://docs.espressif.com/projects/esp-idf/en/latest/esp32/hw-reference/esp32/get-started-devkitc.html | Espressif Systems | ESP32-DevKitC-32E | 356-ESP32-DEVKITC32E | https://www.mouser.fr/ProductDetail/Espressif-Systems/ESP32-DevKitC-32E?qs=GedFDFLaBXFpgD0kAZWDrQ%3D%3D
0 | 0 | 8.82 | 1.47 | 43 | 6 | XX (no incluido en sch) | Pin header 1x40 2,54mm |  |  | https://ar.mouser.com/datasheet/2/181/M20-977-1220590.pdf | Harwin | M20-9774046 | 855-M20-9774046 | https://ar.mouser.com/ProductDetail/Harwin/M20-9774046?qs=Jph8NoUxIfXLwc1dWPXFVw%3D%3D
0 | 0 | 21.2 | 10.6 | 44 | 2 | XX (no incluido en sch) | Llave Interruptor Bipolar 20a Elibet 0-1 Panel |  |  | https://articulo.mercadolibre.com.ar/MLA-715063582-llave-interruptor-bipolar-20a-elibet-0-1-panel-_JM | Elibet | 20002/0 |  | https://articulo.mercadolibre.com.ar/MLA-715063582-llave-interruptor-bipolar-20a-elibet-0-1-panel-_JM
5000 | 2500 | 89.54 | 44.77 | 45 | 2 | XX (no incluido en sch) | USBMODEM-4G-LTE |  |  |  |  |  |  | https://www.todomicro.com.ar/electronica-de-consumo/587-modem-usb-y-router-wifi-3g4g-sim-card.html
0 | 0 | 7.96 | 0.995 | 46 | 8 | Correponde a: J1, J2, J3, J4, J5, J6, J7, J23 | 1934887 |  |  | https://www.phoenixcontact.com/us/products/1934887/pdf | Phoenix Contact | 1934887 | 651-1934887 | https://www.mouser.fr/ProductDetail/Phoenix-Contact/1934887?qs=TU%2Fqnd37FkmAQrQLEWCosQ%3D%3D
0 | 0 | 7.766 | 0.706 | 47 | 11 | Correponde a: J8, J9, J12, J13, J14, J15, J16, J17, J18, J19, J20 | 1935022 |  |  | https://www.phoenixcontact.com/us/products/1935022/pdf | Phoenix Contact | 1935022 | 651-1935022 | https://www.mouser.fr/ProductDetail/Phoenix-Contact/1935022?qs=i11qaVCyeWoRj2tPTAbaig%3D%3D
0 | 0 | 0.548 | 0.548 | 48 | 1 | Correponde a: J22 | 1934861 |  |  | https://www.phoenixcontact.com/us/products/1934861/pdf | Phoenix Contact | 1934861 | 651-1934861 | https://www.mouser.fr/ProductDetail/Phoenix-Contact/1934861?qs=F79NelsxgYFJ8Q%252BI0GKhbg%3D%3D
0 | 0 | 4.88 | 2.44 | 49 | 2 | XX (no incluido en sch) | Socket p/ ESP32 – 1x19 |  |  | https://www.mouser.fr/datasheet/2/527/ssw_th-2854740.pdf | Samtex | SSW-119-01-T-S | 200-SSW11901TS | https://www.mouser.fr/ProductDetail/Samtec/SSW-119-01-T-S?qs=rU5fayqh%252BE1O7STzIZWpjA%3D%3D
0 | 0 | 0.229 | 0.229 | 50 | 1 | XX (no incluido en sch) | Socket p/ GPS – 1x4 |  |  | https://www.mouser.fr/datasheet/2/4/rs1_xx_g_data_sheet-3396051.pdf | Adam Tech |  |  | https://www.mouser.fr/ProductDetail/Adam-Tech/RS1-04-G?qs=HoCaDK9Nz5dGvIs4ZhXhDw%3D%3D
0 | 0 | 7.24 | 1.81 | 51 | 4 | XX (no incluido en sch) | Socket /Nucleo – 2x18 |  |  | https://www.mouser.fr/ProductDetail/SparkFun/PRT-16581?qs=sPbYRqrBIVmf2mq2gyI4eA%3D%3D | SparkFun | PRT-16581 | 474-PRT-16581 | https://www.sparkfun.com/products/16581
 |  |  |  |  | Descontando Nucleo
 |  | Con módulo 3G/4G |  | 362.973 | 338.503
 |  | Sin módulo 3G/4G |  | 273.433 | 248.963
 |  | Precio total a comprar |  |  | 248.963
 |  |  |  | Total | Descontando USB | Descontando Módulos
 |  | Consumo W |  | 19.3849 | 14.3849 | 17.8849

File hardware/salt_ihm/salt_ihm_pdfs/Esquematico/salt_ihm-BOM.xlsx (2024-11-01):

Source: | /home/manus/KiCad/salt/salt_ihm/salt_ihm.kicad_sch
Date: | Wed 24 Apr 2024 03:17:26 PM -03
Tool: | Eeschema 6.0.10-86aedd382b~118~ubuntu18.04.1
Generator: | /usr/share/kicad/plugins/bom_csv_grouped_by_value.py
Component Count: | 41
Individual Components:
Item | Qty | Reference(s) | Value | LibPart | Footprint | Datasheet | Height | Manufacturer_Name | Manufacturer_Part_Number | Mouser Part Number | Mouser Price/Stock
 |  | C1 | 10uF | salt:C_10uF | Capacitor_SMD:C_0805_2012Metric_Pad1.18x1.45mm_HandSolder | https://ar.mouser.com/datasheet/2/447/KEM_C1002_X7R_SMD-3316098.pdf |  | KEMET | C1206C106K4RACTU | 80-C1206C106K4R | https://ar.mouser.com/ProductDetail/KEMET/C1206C106K4RACTU?qs=guDyKOyRtV0mxqxQedB7kA%3D%3D
 |  | C2 | 10uF | salt:C_10uF | Capacitor_SMD:C_0805_2012Metric_Pad1.18x1.45mm_HandSolder | https://ar.mouser.com/datasheet/2/447/KEM_C1002_X7R_SMD-3316098.pdf |  | KEMET | C1206C106K4RACTU | 80-C1206C106K4R | https://ar.mouser.com/ProductDetail/KEMET/C1206C106K4RACTU?qs=guDyKOyRtV0mxqxQedB7kA%3D%3D
 |  | C3 | 100nF | salt:C_100nF | Capacitor_SMD:C_0805_2012Metric_Pad1.18x1.45mm_HandSolder | https://ar.mouser.com/datasheet/2/447/KEM_C1002_X7R_SMD-3316098.pdf |  | KEMET | C0805C104K4RACTU | 80-C0805C104K4R | https://ar.mouser.com/ProductDetail/KEMET/C0805C104K4RACTU?qs=Pc30aiB8zWWfqQNJWggt%252BA%3D%3D
 |  | DS1 | LTC-5723HR | salt:LTC-5723HR | salt:DIP1524W75P254L5030H825Q12N | https://componentsearchengine.com/Datasheets/1/LTC-5723HR.pdf | 8.25 | Lite-On | LTC-5723HR | 859-LTC-5723HR | https://www.mouser.co.uk/ProductDetail/Lite-On/LTC-5723HR?qs=WxFF5lh7QM2ytJdX1EhJKQ%3D%3D
 |  | H1 | MountingHole | salt:MountingHole | MountingHole:MountingHole_3.2mm_M3 | ~
 |  | H2 | MountingHole | salt:MountingHole | MountingHole:MountingHole_3.2mm_M3 | ~
 |  | H3 | MountingHole | salt:MountingHole | MountingHole:MountingHole_3.2mm_M3 | ~
 |  | H4 | MountingHole | salt:MountingHole | MountingHole:MountingHole_3.2mm_M3 | ~
 |  | IC1 | AS1115-BSST | salt:AS1115-BSST | salt:SOP64P600X175-24N | https://datasheet.datasheetarchive.com/originals/distributors/Datasheets-SFU1/DSASFU10002655.pdf | 1.75 | ams | AS1115-BSST | 985-AS1115-BSST | https://www.mouser.co.uk/ProductDetail/ams/AS1115-BSST?qs=jMXWnm70%252BC%2FTIBNsbFwa8Q%3D%3D
 |  | J1 | 1934861 | salt:1934861 | salt:1934861 | https://www.phoenixcontact.com/us/products/1934861/pdf | 8.72 | Phoenix Contact | 1934861 | 651-1934861 | https://ar.mouser.com/ProductDetail/Phoenix-Contact/1934861?qs=F79NelsxgYFJ8Q%252BI0GKhbg%3D%3D
 |  | J2 | 1934887 | salt:1934887 | salt:1934887 | https://www.phoenixcontact.com/us/products/1934887/pdf | 8.72 | Phoenix Contact | 1934887 | 651-1934887 | https://ar.mouser.com/ProductDetail/Phoenix-Contact/1934887?qs=TU%2Fqnd37FkmAQrQLEWCosQ%3D%3D
 |  | LED1 | WP7113LZGCK | salt:WP7113LZGCK | salt:WP7113LZGCK | https://www.mouser.com/datasheet/2/216/WP7113LZGCK-535810.pdf | 8.85 | Kingbright | WP7113LZGCK | 604-WP7113LZGCK | https://www.mouser.com/ProductDetail/Kingbright/WP7113LZGCK?qs=6oMev5NRZME0vaccujctkg%3D%3D
 |  | LED2 | WP154A4SEJ3VBDZGW_CA | salt:WP154A4SEJ3VBDZGW_CA | salt:L-154A4SUREQBFZGEC | http://www.kingbrightusa.com/images/catalog/SPEC/WP154A4SEJ3VBDZGW-CA.pdf |  | Kingbright | WP154A4SEJ3VBDZGW/CA | 604-WP154A43VBDZGWCA | https://www.mouser.co.uk/ProductDetail/Kingbright/WP154A4SEJ3VBDZGW-CA?qs=YCa%2FAAYMW01xRqZww6UuiQ%3D%3D
 |  | LED3 | WP154A4SEJ3VBDZGW_CA | salt:WP154A4SEJ3VBDZGW_CA | salt:L-154A4SUREQBFZGEC | http://www.kingbrightusa.com/images/catalog/SPEC/WP154A4SEJ3VBDZGW-CA.pdf |  | Kingbright | WP154A4SEJ3VBDZGW/CA | 604-WP154A43VBDZGWCA | https://www.mouser.co.uk/ProductDetail/Kingbright/WP154A4SEJ3VBDZGW-CA?qs=YCa%2FAAYMW01xRqZww6UuiQ%3D%3D
 |  | LED4 | WP154A4SEJ3VBDZGW_CA | salt:WP154A4SEJ3VBDZGW_CA | salt:L-154A4SUREQBFZGEC | http://www.kingbrightusa.com/images/catalog/SPEC/WP154A4SEJ3VBDZGW-CA.pdf |  | Kingbright | WP154A4SEJ3VBDZGW/CA | 604-WP154A43VBDZGWCA | https://www.mouser.co.uk/ProductDetail/Kingbright/WP154A4SEJ3VBDZGW-CA?qs=YCa%2FAAYMW01xRqZww6UuiQ%3D%3D
 |  | LED5 | WP154A4SEJ3VBDZGW_CA | salt:WP154A4SEJ3VBDZGW_CA | salt:L-154A4SUREQBFZGEC | http://www.kingbrightusa.com/images/catalog/SPEC/WP154A4SEJ3VBDZGW-CA.pdf |  | Kingbright | WP154A4SEJ3VBDZGW/CA | 604-WP154A43VBDZGWCA | https://www.mouser.co.uk/ProductDetail/Kingbright/WP154A4SEJ3VBDZGW-CA?qs=YCa%2FAAYMW01xRqZww6UuiQ%3D%3D
 |  | LED6 | WP154A4SEJ3VBDZGW_CA | salt:WP154A4SEJ3VBDZGW_CA | salt:L-154A4SUREQBFZGEC | http://www.kingbrightusa.com/images/catalog/SPEC/WP154A4SEJ3VBDZGW-CA.pdf |  | Kingbright | WP154A4SEJ3VBDZGW/CA | 604-WP154A43VBDZGWCA | https://www.mouser.co.uk/ProductDetail/Kingbright/WP154A4SEJ3VBDZGW-CA?qs=YCa%2FAAYMW01xRqZww6UuiQ%3D%3D
 |  | LED7 | WP154A4SEJ3VBDZGW_CA | salt:WP154A4SEJ3VBDZGW_CA | salt:L-154A4SUREQBFZGEC | http://www.kingbrightusa.com/images/catalog/SPEC/WP154A4SEJ3VBDZGW-CA.pdf |  | Kingbright | WP154A4SEJ3VBDZGW/CA | 604-WP154A43VBDZGWCA | https://www.mouser.co.uk/ProductDetail/Kingbright/WP154A4SEJ3VBDZGW-CA?qs=YCa%2FAAYMW01xRqZww6UuiQ%3D%3D
 |  | LED8 | WP154A4SEJ3VBDZGW_CA | salt:WP154A4SEJ3VBDZGW_CA | salt:L-154A4SUREQBFZGEC | http://www.kingbrightusa.com/images/catalog/SPEC/WP154A4SEJ3VBDZGW-CA.pdf |  | Kingbright | WP154A4SEJ3VBDZGW/CA | 604-WP154A43VBDZGWCA | https://www.mouser.co.uk/ProductDetail/Kingbright/WP154A4SEJ3VBDZGW-CA?qs=YCa%2FAAYMW01xRqZww6UuiQ%3D%3D
 |  | LED9 | WP154A4SEJ3VBDZGW_CA | salt:WP154A4SEJ3VBDZGW_CA | salt:L-154A4SUREQBFZGEC | http://www.kingbrightusa.com/images/catalog/SPEC/WP154A4SEJ3VBDZGW-CA.pdf |  | Kingbright | WP154A4SEJ3VBDZGW/CA | 604-WP154A43VBDZGWCA | https://www.mouser.co.uk/ProductDetail/Kingbright/WP154A4SEJ3VBDZGW-CA?qs=YCa%2FAAYMW01xRqZww6UuiQ%3D%3D
 |  | LED10 | WP154A4SEJ3VBDZGW_CA | salt:WP154A4SEJ3VBDZGW_CA | salt:L-154A4SUREQBFZGEC | http://www.kingbrightusa.com/images/catalog/SPEC/WP154A4SEJ3VBDZGW-CA.pdf |  | Kingbright | WP154A4SEJ3VBDZGW/CA | 604-WP154A43VBDZGWCA | https://www.mouser.co.uk/ProductDetail/Kingbright/WP154A4SEJ3VBDZGW-CA?qs=YCa%2FAAYMW01xRqZww6UuiQ%3D%3D
 |  | LED11 | WP154A4SEJ3VBDZGW_CA | salt:WP154A4SEJ3VBDZGW_CA | salt:L-154A4SUREQBFZGEC | http://www.kingbrightusa.com/images/catalog/SPEC/WP154A4SEJ3VBDZGW-CA.pdf |  | Kingbright | WP154A4SEJ3VBDZGW/CA | 604-WP154A43VBDZGWCA | https://www.mouser.co.uk/ProductDetail/Kingbright/WP154A4SEJ3VBDZGW-CA?qs=YCa%2FAAYMW01xRqZww6UuiQ%3D%3D
 |  | LED12 | WP7113LZGCK | salt:WP7113LZGCK | salt:WP7113LZGCK | https://www.mouser.com/datasheet/2/216/WP7113LZGCK-535810.pdf | 8.85 | Kingbright | WP7113LZGCK | 604-WP7113LZGCK | https://www.mouser.com/ProductDetail/Kingbright/WP7113LZGCK?qs=6oMev5NRZME0vaccujctkg%3D%3D
 |  | LED13 | WP7113LZGCK | salt:WP7113LZGCK | salt:WP7113LZGCK | https://www.mouser.com/datasheet/2/216/WP7113LZGCK-535810.pdf | 8.85 | Kingbright | WP7113LZGCK | 604-WP7113LZGCK | https://www.mouser.com/ProductDetail/Kingbright/WP7113LZGCK?qs=6oMev5NRZME0vaccujctkg%3D%3D
 |  | LED14 | WP7113LZGCK | salt:WP7113LZGCK | salt:WP7113LZGCK | https://www.mouser.com/datasheet/2/216/WP7113LZGCK-535810.pdf | 8.85 | Kingbright | WP7113LZGCK | 604-WP7113LZGCK | https://www.mouser.com/ProductDetail/Kingbright/WP7113LZGCK?qs=6oMev5NRZME0vaccujctkg%3D%3D
 |  | LED15 | WP7113LZGCK | salt:WP7113LZGCK | salt:WP7113LZGCK | https://www.mouser.com/datasheet/2/216/WP7113LZGCK-535810.pdf | 8.85 | Kingbright | WP7113LZGCK | 604-WP7113LZGCK | https://www.mouser.com/ProductDetail/Kingbright/WP7113LZGCK?qs=6oMev5NRZME0vaccujctkg%3D%3D
 |  | LED16 | WP7113LZGCK | salt:WP7113LZGCK | salt:WP7113LZGCK | https://www.mouser.com/datasheet/2/216/WP7113LZGCK-535810.pdf | 8.85 | Kingbright | WP7113LZGCK | 604-WP7113LZGCK | https://www.mouser.com/ProductDetail/Kingbright/WP7113LZGCK?qs=6oMev5NRZME0vaccujctkg%3D%3D
 |  | LED17 | WP7113LZGCK | salt:WP7113LZGCK | salt:WP7113LZGCK | https://www.mouser.com/datasheet/2/216/WP7113LZGCK-535810.pdf | 8.85 | Kingbright | WP7113LZGCK | 604-WP7113LZGCK | https://www.mouser.com/ProductDetail/Kingbright/WP7113LZGCK?qs=6oMev5NRZME0vaccujctkg%3D%3D
 |  | LED18 | WP7113LZGCK | salt:WP7113LZGCK | salt:WP7113LZGCK | https://www.mouser.com/datasheet/2/216/WP7113LZGCK-535810.pdf | 8.85 | Kingbright | WP7113LZGCK | 604-WP7113LZGCK | https://www.mouser.com/ProductDetail/Kingbright/WP7113LZGCK?qs=6oMev5NRZME0vaccujctkg%3D%3D
 |  | LS1 | CEM-1205-IC | salt:CEM-1205-IC | salt:CEM1205IC | https://www.cuidevices.com/product/resource/cem-1205-ic.pdf | 10 | CUI Devices | CEM-1205-IC | 490-CEM1205IC | https://www.mouser.co.uk/ProductDetail/CUI-Devices/CEM-1205-IC?qs=hd1VzrDQEGhFNAzregGKGQ%3D%3D
 |  | Q1 | NVTR0202PLT1G | salt:NVTR0202PLT1G | salt:SOT96P237X111-3N | https://componentsearchengine.com/Datasheets/2/NVTR0202PLT1G.pdf | 1.11 | onsemi | NVTR0202PLT1G | 863-NVTR0202PLT1G | https://www.mouser.co.uk/ProductDetail/onsemi/NVTR0202PLT1G?qs=3PKVEWFFm29UPkq%2FAwGemg%3D%3D
 |  | R1 | 150k | salt:R_150K | Resistor_SMD:R_0805_2012Metric_Pad1.20x1.40mm_HandSolder | https://ar.mouser.com/datasheet/2/447/PYu_RC_Group_51_RoHS_L_11-1984063.pdf |  | YAGEO | RC0805FR-13150KL | 603-RC0805FR-13150KL | https://ar.mouser.com/ProductDetail/YAGEO/RC0805FR-13150KL?qs=m6lXFsvg5e2Mp%2Fy7W%252BnUqg%3D%3D
 |  | R2 | 100 | salt:R_100 | Resistor_SMD:R_0805_2012Metric_Pad1.20x1.40mm_HandSolder | https://ar.mouser.com/datasheet/2/447/PYu_RC_Group_51_RoHS_L_11-1984063.pdf |  | YAGEO | RC0805FR-10100RL | 603-RC0805FR-10100RL | https://ar.mouser.com/ProductDetail/YAGEO/RC0805FR-10100RL?qs=g6xwsc4j%252B%2FoYV9cxut0j6Q%3D%3D
 |  | R3 | 22k | salt:R_22K | Resistor_SMD:R_0805_2012Metric_Pad1.20x1.40mm_HandSolder | https://ar.mouser.com/datasheet/2/447/PYu_RC_Group_51_RoHS_L_11-1984063.pdf |  | YAGEO | RC0805FR-1022KL | 603-RC0805FR-1022KL | https://ar.mouser.com/ProductDetail/YAGEO/RC0805FR-1022KL?qs=m6lXFsvg5e37y4fr%252BWohrg%3D%3D
 |  | R4 | 40K2 | salt:R_40K2 | Resistor_SMD:R_0805_2012Metric_Pad1.20x1.40mm_HandSolder | https://ar.mouser.com/datasheet/2/447/YAGEO_PYu_RC_Group_51_RoHS_L_12-3313492.pdf |  | YAGEO | RC0805FR-0740K2L | 603-RC0805FR-0740K2L | https://ar.mouser.com/ProductDetail/YAGEO/RC0805FR-0740K2L?qs=QrWOOBGzeCbZpVapvyHnwA%3D%3D
 |  | R5 | 22k | salt:R_22K | Resistor_SMD:R_0805_2012Metric_Pad1.20x1.40mm_HandSolder | https://ar.mouser.com/datasheet/2/447/PYu_RC_Group_51_RoHS_L_11-1984063.pdf |  | YAGEO | RC0805FR-1022KL | 603-RC0805FR-1022KL | https://ar.mouser.com/ProductDetail/YAGEO/RC0805FR-1022KL?qs=m6lXFsvg5e37y4fr%252BWohrg%3D%3D
 |  | S1 | 1543-650-149 | salt:1543-650-149 | salt:1543650149 | https://www.arrow.com/en/products/1543-650-149/bourns | 15.1 | Bourns | 1543-650-149 | 652-1543-650-149 | https://www.mouser.co.uk/ProductDetail/Bourns/1543-650-149?qs=2f2kQrcl%2FoiIszYh%252BBIYwA%3D%3D
 |  | TP1 | TestPoint | salt:TestPoint | salt:testpoint | ~
 |  | TP2 | TestPoint | salt:TestPoint | salt:testpoint | ~
 |  | TP3 | TestPoint | salt:TestPoint | salt:testpoint | ~
 |  | TP4 | TestPoint | salt:TestPoint | salt:testpoint | ~
Collated Components:
Item | Qty | Reference(s) | Value | LibPart | Footprint | Datasheet | Height | Manufacturer_Name | Manufacturer_Part_Number | Mouser Part Number | Mouser Price/Stock
1 | 2 | C1, C2 | 10uF | salt:C_10uF | Capacitor_SMD:C_0805_2012Metric_Pad1.18x1.45mm_HandSolder | https://ar.mouser.com/datasheet/2/447/KEM_C1002_X7R_SMD-3316098.pdf |  | KEMET | C1206C106K4RACTU | 80-C1206C106K4R | https://ar.mouser.com/ProductDetail/KEMET/C1206C106K4RACTU?qs=guDyKOyRtV0mxqxQedB7kA%3D%3D
2 | 1 | C3 | 100nF | salt:C_100nF | Capacitor_SMD:C_0805_2012Metric_Pad1.18x1.45mm_HandSolder | https://ar.mouser.com/datasheet/2/447/KEM_C1002_X7R_SMD-3316098.pdf |  | KEMET | C0805C104K4RACTU | 80-C0805C104K4R | https://ar.mouser.com/ProductDetail/KEMET/C0805C104K4RACTU?qs=Pc30aiB8zWWfqQNJWggt%252BA%3D%3D
3 | 1 | DS1 | LTC-5723HR | salt:LTC-5723HR | salt:DIP1524W75P254L5030H825Q12N | https://componentsearchengine.com/Datasheets/1/LTC-5723HR.pdf | 8.25 | Lite-On | LTC-5723HR | 859-LTC-5723HR | https://www.mouser.co.uk/ProductDetail/Lite-On/LTC-5723HR?qs=WxFF5lh7QM2ytJdX1EhJKQ%3D%3D
4 | 4 | H1, H2, H3, H4 | MountingHole | salt:MountingHole | MountingHole:MountingHole_3.2mm_M3 | ~
5 | 1 | IC1 | AS1115-BSST | salt:AS1115-BSST | salt:SOP64P600X175-24N | https://datasheet.datasheetarchive.com/originals/distributors/Datasheets-SFU1/DSASFU10002655.pdf | 1.75 | ams | AS1115-BSST | 985-AS1115-BSST | https://www.mouser.co.uk/ProductDetail/ams/AS1115-BSST?qs=jMXWnm70%252BC%2FTIBNsbFwa8Q%3D%3D
6 | 1 | J1 | 1934861 | salt:1934861 | salt:1934861 | https://www.phoenixcontact.com/us/products/1934861/pdf | 8.72 | Phoenix Contact | 1934861 | 651-1934861 | https://ar.mouser.com/ProductDetail/Phoenix-Contact/1934861?qs=F79NelsxgYFJ8Q%252BI0GKhbg%3D%3D
7 | 1 | J2 | 1934887 | salt:1934887 | salt:1934887 | https://www.phoenixcontact.com/us/products/1934887/pdf | 8.72 | Phoenix Contact | 1934887 | 651-1934887 | https://ar.mouser.com/ProductDetail/Phoenix-Contact/1934887?qs=TU%2Fqnd37FkmAQrQLEWCosQ%3D%3D
8 | 8 | LED1, LED12, LED13, LED14, LED15, LED16, LED17, LED18 | WP7113LZGCK | salt:WP7113LZGCK | salt:WP7113LZGCK | https://www.mouser.com/datasheet/2/216/WP7113LZGCK-535810.pdf | 8.85 | Kingbright | WP7113LZGCK | 604-WP7113LZGCK | https://www.mouser.com/ProductDetail/Kingbright/WP7113LZGCK?qs=6oMev5NRZME0vaccujctkg%3D%3D
9 | 10 | LED2, LED3, LED4, LED5, LED6, LED7, LED8, LED9, LED10, LED11 | WP154A4SEJ3VBDZGW_CA | salt:WP154A4SEJ3VBDZGW_CA | salt:L-154A4SUREQBFZGEC | http://www.kingbrightusa.com/images/catalog/SPEC/WP154A4SEJ3VBDZGW-CA.pdf |  | Kingbright | WP154A4SEJ3VBDZGW/CA | 604-WP154A43VBDZGWCA | https://www.mouser.co.uk/ProductDetail/Kingbright/WP154A4SEJ3VBDZGW-CA?qs=YCa%2FAAYMW01xRqZww6UuiQ%3D%3D
10 | 1 | LS1 | CEM-1205-IC | salt:CEM-1205-IC | salt:CEM1205IC | https://www.cuidevices.com/product/resource/cem-1205-ic.pdf | 10 | CUI Devices | CEM-1205-IC | 490-CEM1205IC | https://www.mouser.co.uk/ProductDetail/CUI-Devices/CEM-1205-IC?qs=hd1VzrDQEGhFNAzregGKGQ%3D%3D
11 | 1 | Q1 | NVTR0202PLT1G | salt:NVTR0202PLT1G | salt:SOT96P237X111-3N | https://componentsearchengine.com/Datasheets/2/NVTR0202PLT1G.pdf | 1.11 | onsemi | NVTR0202PLT1G | 863-NVTR0202PLT1G | https://www.mouser.co.uk/ProductDetail/onsemi/NVTR0202PLT1G?qs=3PKVEWFFm29UPkq%2FAwGemg%3D%3D
12 | 1 | R1 | 150k | salt:R_150K | Resistor_SMD:R_0805_2012Metric_Pad1.20x1.40mm_HandSolder | https://ar.mouser.com/datasheet/2/447/PYu_RC_Group_51_RoHS_L_11-1984063.pdf |  | YAGEO | RC0805FR-13150KL | 603-RC0805FR-13150KL | https://ar.mouser.com/ProductDetail/YAGEO/RC0805FR-13150KL?qs=m6lXFsvg5e2Mp%2Fy7W%252BnUqg%3D%3D
13 | 1 | R2 | 100 | salt:R_100 | Resistor_SMD:R_0805_2012Metric_Pad1.20x1.40mm_HandSolder | https://ar.mouser.com/datasheet/2/447/PYu_RC_Group_51_RoHS_L_11-1984063.pdf |  | YAGEO | RC0805FR-10100RL | 603-RC0805FR-10100RL | https://ar.mouser.com/ProductDetail/YAGEO/RC0805FR-10100RL?qs=g6xwsc4j%252B%2FoYV9cxut0j6Q%3D%3D
14 | 2 | R3, R5 | 22k | salt:R_22K | Resistor_SMD:R_0805_2012Metric_Pad1.20x1.40mm_HandSolder | https://ar.mouser.com/datasheet/2/447/PYu_RC_Group_51_RoHS_L_11-1984063.pdf |  | YAGEO | RC0805FR-1022KL | 603-RC0805FR-1022KL | https://ar.mouser.com/ProductDetail/YAGEO/RC0805FR-1022KL?qs=m6lXFsvg5e37y4fr%252BWohrg%3D%3D
15 | 1 | R4 | 40K2 | salt:R_40K2 | Resistor_SMD:R_0805_2012Metric_Pad1.20x1.40mm_HandSolder | https://ar.mouser.com/datasheet/2/447/YAGEO_PYu_RC_Group_51_RoHS_L_12-3313492.pdf |  | YAGEO | RC0805FR-0740K2L | 603-RC0805FR-0740K2L | https://ar.mouser.com/ProductDetail/YAGEO/RC0805FR-0740K2L?qs=QrWOOBGzeCbZpVapvyHnwA%3D%3D
16 | 1 | S1 | 1543-650-149 | salt:1543-650-149 | salt:1543650149 | https://www.arrow.com/en/products/1543-650-149/bourns | 15.1 | Bourns | 1543-650-149 | 652-1543-650-149 | https://www.mouser.co.uk/ProductDetail/Bourns/1543-650-149?qs=2f2kQrcl%2FoiIszYh%252BBIYwA%3D%3D
17 | 4 | TP1, TP2, TP3, TP4 | TestPoint | salt:TestPoint | salt:testpoint | ~

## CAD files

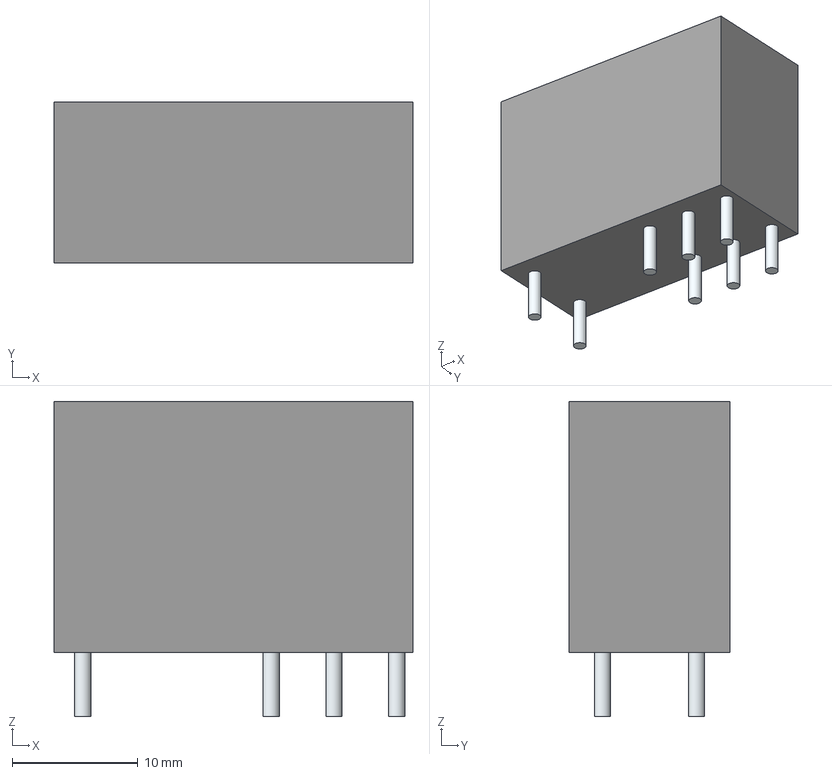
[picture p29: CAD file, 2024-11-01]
hardware/salt/3dmodels/JW2SN-DC5V.stp
28.6 x 12.8 x 25.1 mm
Leads

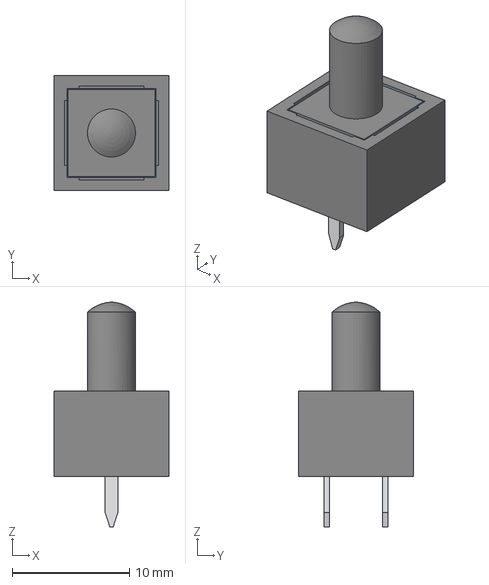
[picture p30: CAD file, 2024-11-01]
hardware/salt/Models/1543-650-149/1543-650-149.stp
9.80 x 9.80 x 19.2 mm

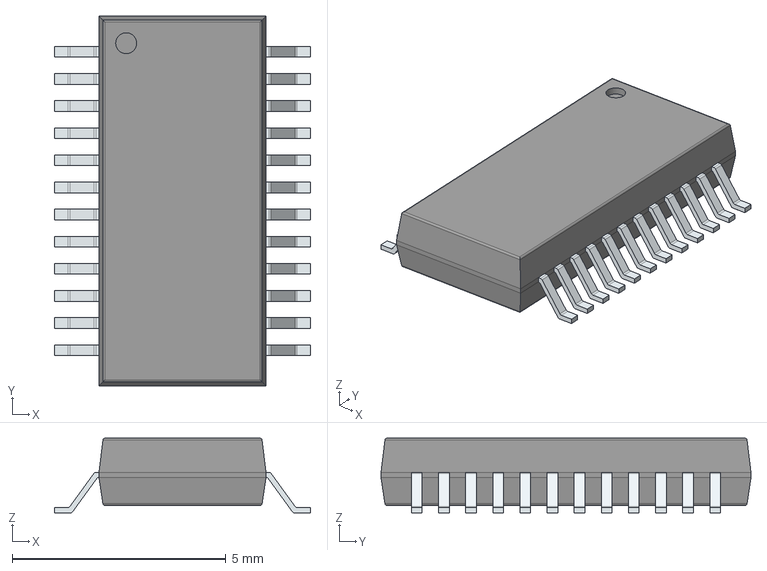
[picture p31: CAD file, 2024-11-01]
hardware/salt/Models/AS1115-BSST/AS1115-BSST.stp
6.00 x 8.66 x 1.75 mm
PinsArrayLR

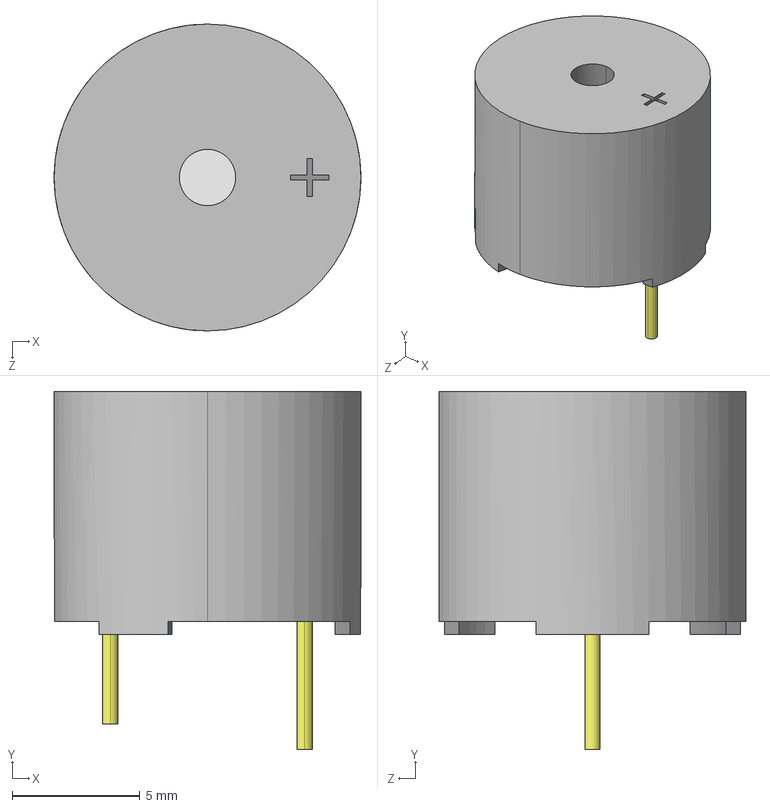
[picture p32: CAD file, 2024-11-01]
hardware/salt/Models/CEM-1205-IC/CEM-1205-IC.stp
12.0 x 14.0 x 12.0 mm

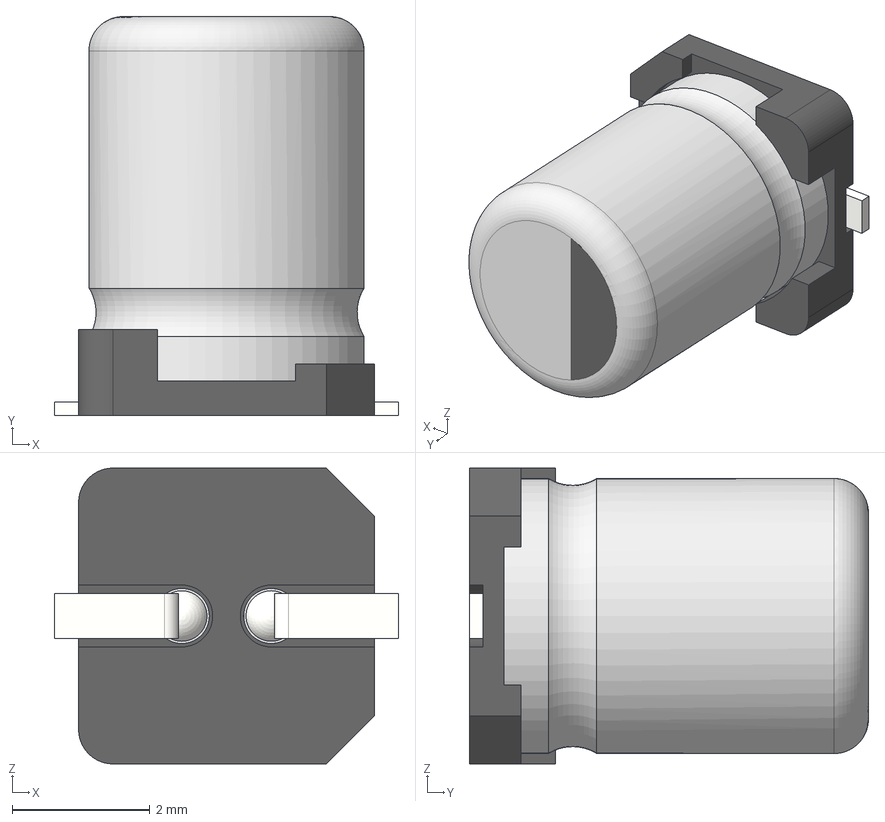
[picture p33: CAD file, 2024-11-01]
hardware/salt/Models/EEE-HAV100WAR/EEE-HAV100WAR.stp
5.00 x 5.80 x 4.30 mm
標準品ケースΦ4x5.3L SIDE CODE B
標準品座版Φ4 SIZE CODE B
標準品リード線Φ4 SIZE CODE B x 2

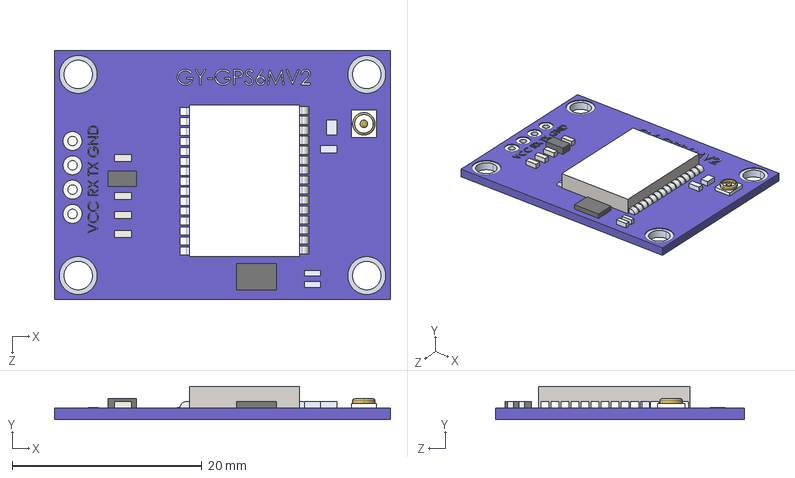
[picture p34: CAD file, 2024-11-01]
hardware/salt/Models/GY-GPS6MV2/GY-GPS6MV2.STEP
35.4 x 3.50 x 26.2 mm

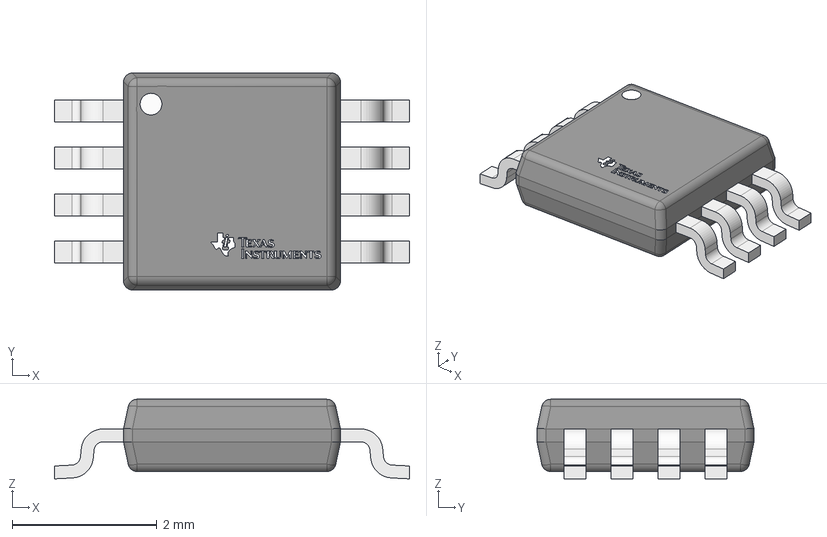
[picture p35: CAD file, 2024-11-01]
hardware/salt/Models/INA823DGKR/eec.models/Texas_Instruments_-_INA823DGKR.step
4.90 x 3.00 x 1.10 mm
BODY_MUA08A
LEAD_MUA08A x 8
Texas Instruments
circle

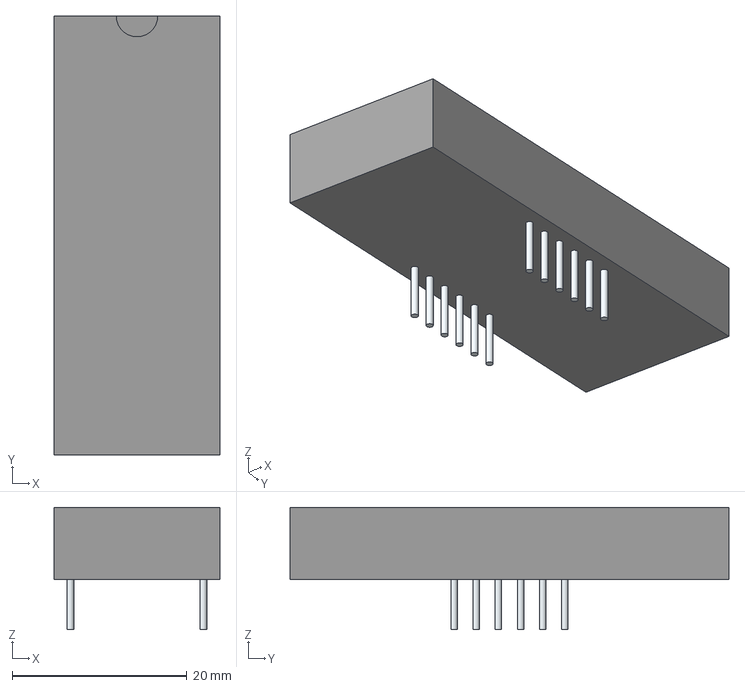
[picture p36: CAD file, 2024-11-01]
hardware/salt/Models/LTC-5723HR/LTC-5723HR.stp
19.0 x 50.3 x 14.0 mm
PinsArrayLR

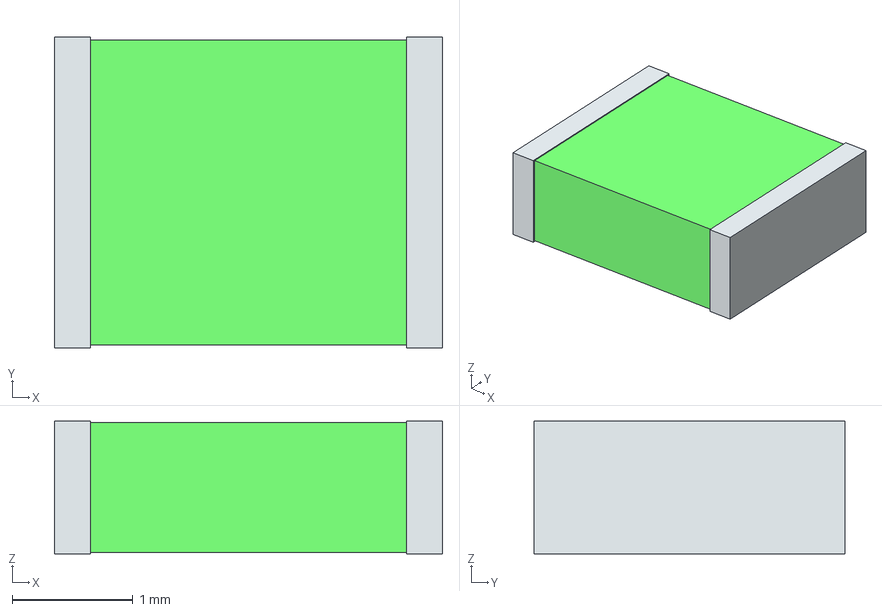
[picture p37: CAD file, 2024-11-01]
hardware/salt/Models/MF-USMF020-2/MF-USMF020-2.stp
3.21 x 2.58 x 1.10 mm
term1
term2

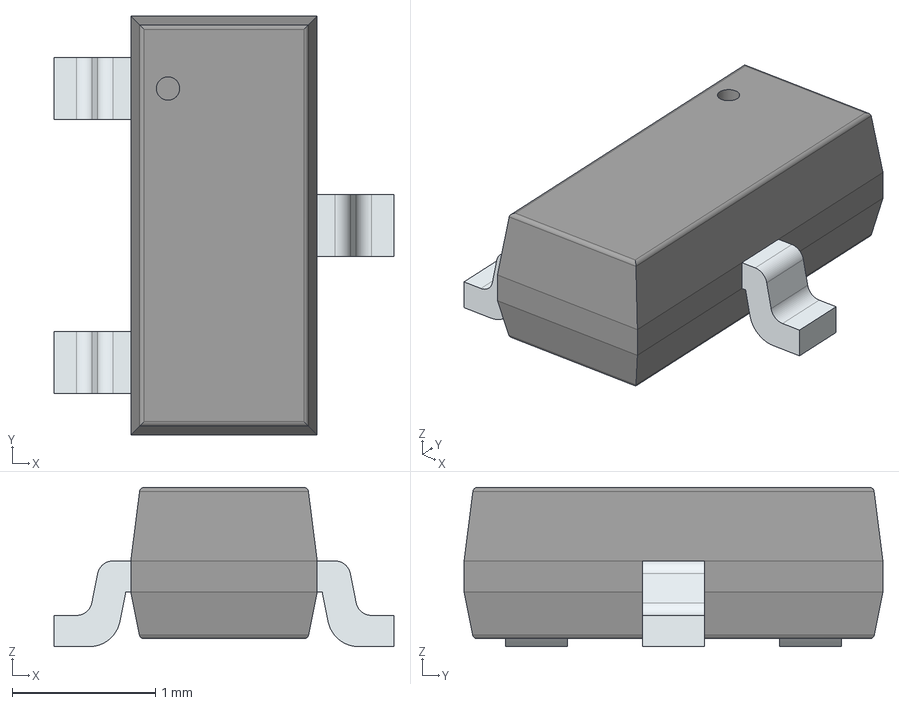
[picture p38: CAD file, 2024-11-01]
hardware/salt/Models/NVTR0202PLT1G/NVTR0202PLT1G.stp
2.37 x 2.92 x 1.11 mm
PinsArrayL
FilletPinR

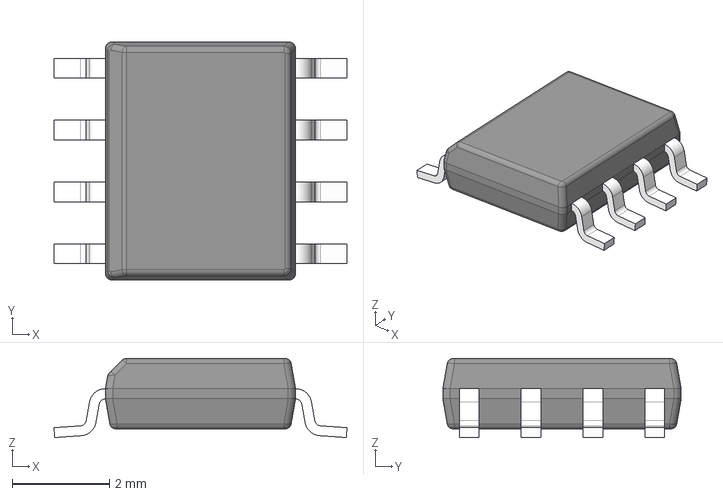
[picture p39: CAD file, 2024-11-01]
hardware/salt/Models/SN65HVD1176DR/SN65HVD1176DR.stp
6.02 x 4.90 x 1.63 mm
BODY-SO
LEAD-D0008A x 8

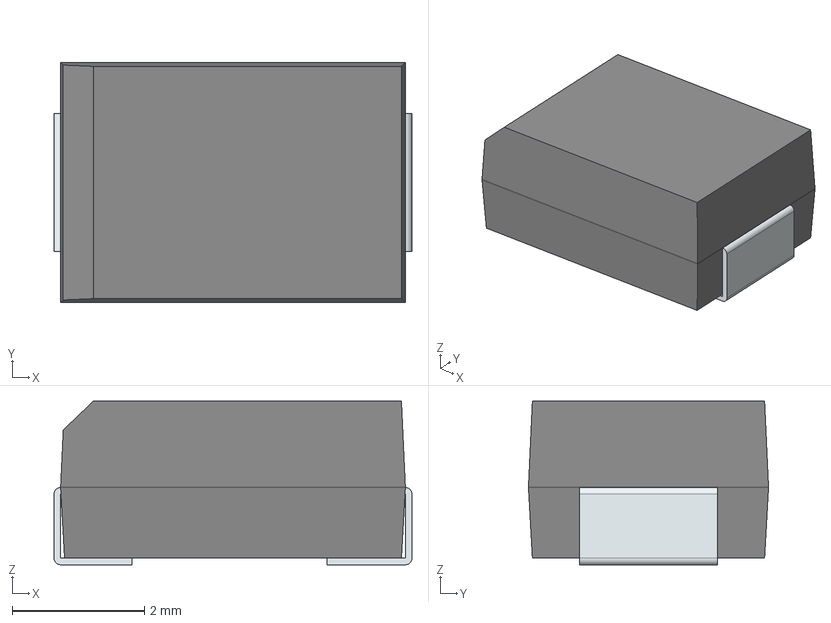
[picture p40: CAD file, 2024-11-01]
hardware/salt/Models/SZP6SMB12CAT3G/SZP6SMB12CAT3G.stp
5.41 x 3.62 x 2.47 mm
FilletPin1
FilletPin2

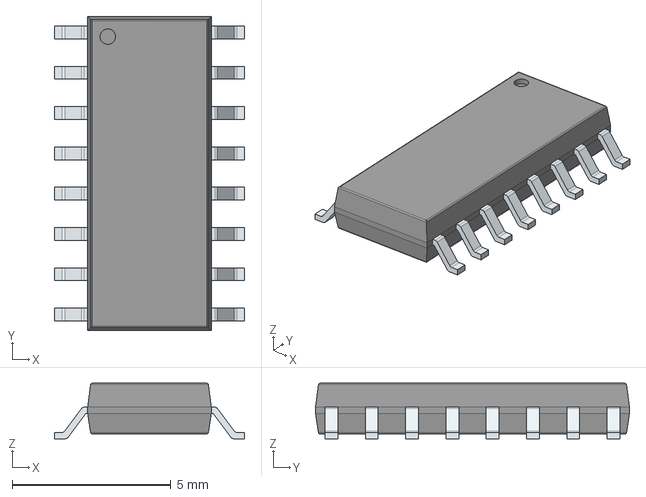
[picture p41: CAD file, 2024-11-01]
hardware/salt/Models/ULN2003D1013TR/ULN2003D1013TR.stp
6.00 x 9.90 x 1.75 mm
PinsArrayLR

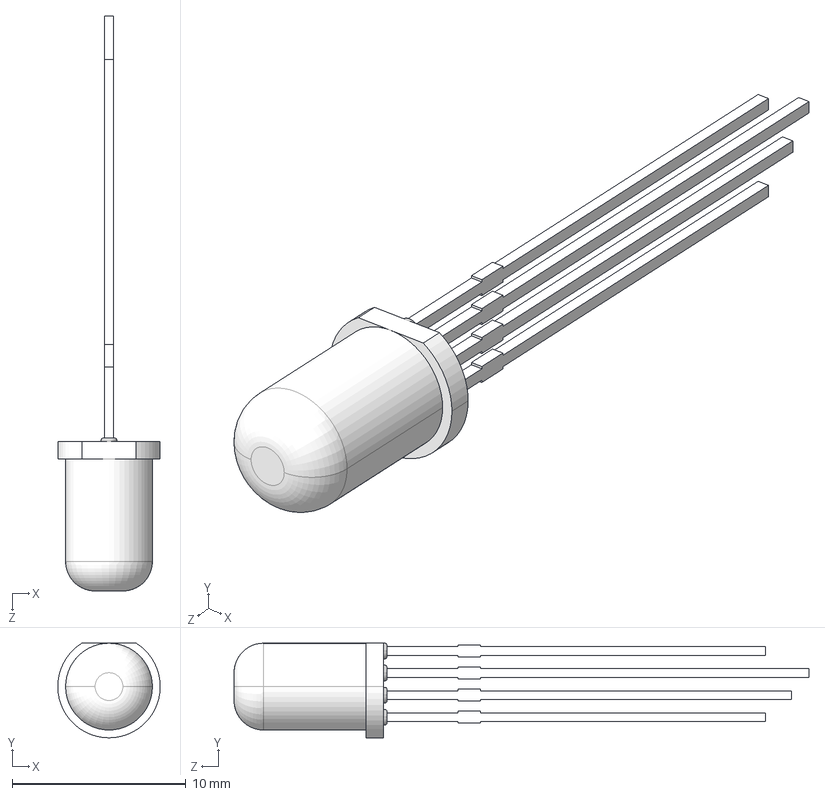
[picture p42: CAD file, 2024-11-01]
hardware/salt/Models/WP154A4SEJ3VBDZGW_CA/WP154A4SEJ3VBDZGW_CA.stp
5.90 x 5.45 x 33.1 mm

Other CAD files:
hardware/salt/Models/INA823DGKR/INA823DGKR.stp
hardware/salt/Models/SI2343DS-T1-E3/SI2343DS-T1-E3.stp
hardware/salt/Models/WP7113LZGCK/WP7113GC.stp
hardware/salt/3dmodels/1757475.stp
hardware/salt/3dmodels/1757491.stp
hardware/salt/3dmodels/1934861.stp
hardware/salt/3dmodels/1934887.stp
hardware/salt/3dmodels/1935022.stp
hardware/salt/3dmodels/87583-2010BLF.stp
hardware/salt/3dmodels/GY-NEO6MV2.step
hardware/salt/3dmodels/INA823DGKR.stp
hardware/salt/3dmodels/SI2343DS-T1-E3.stp
hardware/salt/3dmodels/V23047-A1024-A501.stp
hardware/salt/3dmodels/WP7113GC.stp
hardware/salt/Models/1757475/1757475.stp
hardware/salt/Models/1757491/1757491.stp
hardware/salt/Models/1934861/1934861.stp
hardware/salt/Models/1934887/1934887.stp
hardware/salt/Models/1935022/1935022.stp
hardware/salt/Models/87583-2010BLF/87583-2010BLF.stp
hardware/salt/Models/GY-GPS6MV2/GY-NEO6MV2.step
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

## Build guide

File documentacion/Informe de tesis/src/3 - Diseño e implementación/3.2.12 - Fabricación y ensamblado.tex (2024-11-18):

\subsubsection{Fabricación y ensamblado}

El diseño de hardware del SAL/T incluye algunos otros componentes no mencionados en los puntos anteriores. Las resistencias utilizadas en el proyecto son resistencias de película gruesa de montaje superficial (SMD), de 1/4 W, tolerancia del 1\% y tamaño 0805; se utilizaron los distintos valores que ofrece la empresa YAGEO para su serie RC. Para los capacitores se utilizaron generalmente capacitores cerámicos multicapa de KEMET, de montaje superficial tamaño 0805, tolerancia del 10\% y operan hasta 16 VDC. Para los capacitores electrolíticos, se utilizaron capacitores de aluminio de Panasonic de la serie HA con tolerancia 20\% y operación hasta 35 VDC. \\ 

En la tabla \ref{tab:bom}, se visualiza el listado completo de los componentes (BOM) necesarios para fabricar el prototipo del SAL/T con sus precios en dólares estadounidenses expuestos por el distribuidor Mouser Electronics que suma un total de 363 USD: 

\input{3 - Diseño e implementación/3.2.12_ - BOM_table}

Con el listado de materiales y sus hojas de datos presentes (que pueden ser accedidas mediante el hipervínculo colocado sobre cada modelo de componente en la tabla \ref{tab:bom}), se calculó el consumo máximo de potencia del SAL/T. La potencia total máxima que puede consumir el sistema, considerando que todos los componentes están trabajando al máximo de consumo lo que es un caso improbable, es de 18,4 W. El principal componente de la potencia son los relés que individualmente consumen 106 mA cada uno al estar activados y hay 21 relés en todo el sistema. Los módulos USB Wi-Fi-4G, considerados para el cálculo de potencia, también tienen un gran consumo de 500 mA cada uno, ya que necesitar generar la señal de la red Wi-Fi. Los módulos de GPS, ESP32 y Nucleo consumen alrededor de 100 mA cada uno. El resto de los componentes suman de manera insignificante al número total. Por eso, se considera necesario una fuente de 5 V con potencia de 20 W para alimentar el SAL/T. \\

El diseño del sistema considera para todos los circuitos integrados un capacitor de 100 nF de desacople para conectar cerca de su pin de alimentación entre VCC y tierra con el objetivo de filtrar ruidos que puedan estar presentes en la línea de alimentación. Para los casos más sensibles, también se contempló un capacitor electrolítico de 10 $\mu$F con la idea de reforzar el filtrado para ruidos de distintas frecuencias. También, en los esquemáticos se colocó una resistencia de 0 $\Omega$ al previo a conectar la línea de alimentación con el pin VCC de los chips para permitir el armado progresivo y segmentado del circuito una vez fabricado.  La selección de componentes consideró utilizar la menor cantidad posible de componentes \textit{through-hole} priorizando los de montaje superficial porque en aplicaciones ferroviarias, los componentes \textit{through-hole} pueden sufrir cortes o daños por las vibraciones de la formación.\\

Para conectar los módulos a la placa, se eligió utilizar conectores hembra tipo zócalo soldados a la placa para permitir colocar y sacar los módulos de manera más simple para su manipulación, programación y eventual reemplazo. Para la conexión con los sistemas externos, se utilizaron conectores de tipo bornera con tornillo soldados a la placa que permiten la conexión de cables. El sistema cuenta con veinte borneras en total y es por eso que cada una tiene identificada su función así como cada pin tiene indicada a qué señal corresponde. Esto aplica también para todos los componentes del sistema que tienen señalado qué número de componente corresponde a cada \textit{footprint} para facilitar el armado y el mantenimiento de las placas ante cualquier inconveniente. También se colocaron puntos de prueba en la mayoría de las señales relevantes para el sistema para poder medir el estado eléctrico de cada señal durante el armado, \textit{debugging} y pruebas del sistema. \\

Se intentó utilizar anchos de pista grandes para evitar quiebres en las pistas por vibraciones o flexiones de la placa y reducir la resistencia de las pistas. También fue necesario utilizar distintos anchos para poder realizar el ruteo entre pines de la placa Núcleo. Se utilizaron anchos de 0,3, 0,4, 0,5 y 0,8 mm considerando el mayor ancho para las señales de alimentación o que transportan mayor corriente. Las vías se hicieron de 1 mm con agujero de 0,4 mm. Para los conectores de las borneras, se siguió la recomendación de utilizar agujeros grandes de 1,4 mm de diámetro con un anillo anular de 1,6 mm  y pistas anchas de 0,8 mm para reducir el daño que pueda causar las fricciones provocadas por el procedimiento de instalación utilizando los tornillos de la bornera. Los puntos de prueba se hicieron de 1,02 mm de diámetro con un anillo anular de 0,51 mm para permitir utilizar la punta de un tester común para medir las señales. Además, las placas cuentan con agujeros para el montaje de la placa en el gabinete que se hicieron siguiendo el formato de tornillo M3 de diámetro 3,2 mm. \\

En la tabla \ref{tab:design_constraints} se visualizan algunas de las restricciones utilizadas como reglas de diseño:

\begin{table}[H]
    \centering
    \begin{tabular}{|c|c|}
        \hline
         \textbf{Restricción} & \textbf{Valor}  \\ \hline
         Cobre - mínima distancia entre pistas & 0,2 mm  \\ \hline
         Cobre - mínimo ancho de pista & 0,3 mm  \\ \hline
         Cobre - mínimo ancho anular  & 0,25 mm  \\ \hline
         Cobre - mínimo diámetro de vía  & 1 mm  \\ \hline
         \textit{Holes} - mínimo diámetro del agujero & 0,3 mm \\ \hline
         \textit{Holes} - mínimo distancia entre agujeros & 0,254 mm \\
         \hline
    \end{tabular}
    \caption{Restricciones de diseño utilizadas para el diseño del PCB}
    \label{tab:design_constraints}
\end{table}

En ambas placas, se utilizó una de las capas como plano de tierra intentando utilizar la menor cantidad de pistas por ese lado mientras que la otra capa se utilizó para hacer todas las conexiones posibles. En las figuras \ref{fig:salt_tracks} y \ref{fig:salt_ihm_tracks} se visualizan los trazos de las pistas diseñados en ambas placas: 

\begin{figure}[H]
    \centering
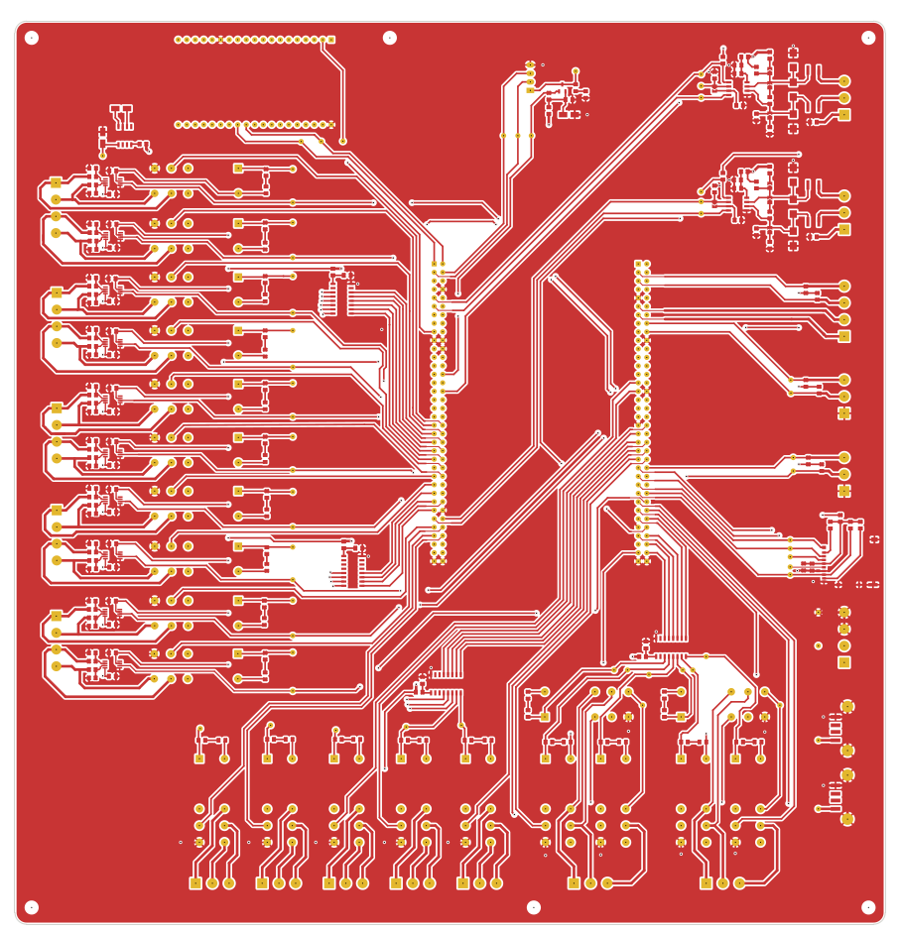
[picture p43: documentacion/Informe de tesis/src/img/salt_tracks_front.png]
    
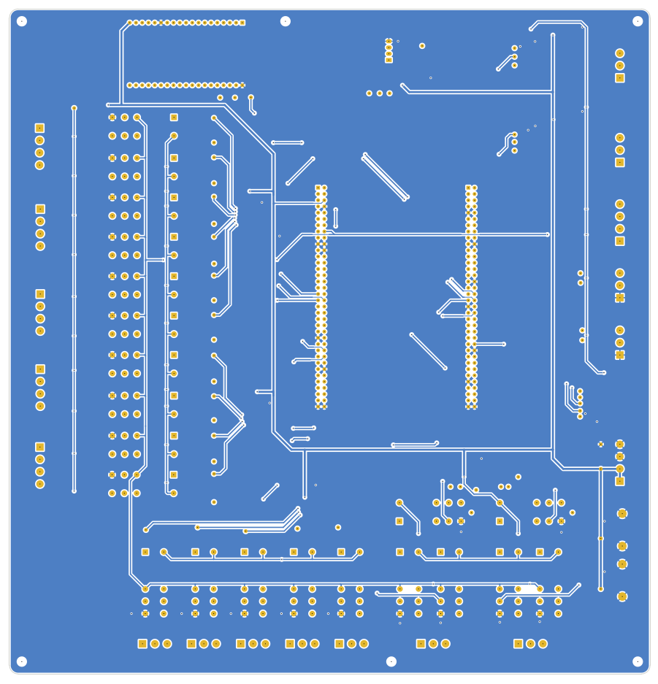
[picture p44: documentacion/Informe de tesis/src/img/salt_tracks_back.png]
    
    \caption{Pistas y planos de la placa principal del SAL/T}
    \label{fig:salt_tracks}
\end{figure}    

\begin{figure}[H]
    \centering
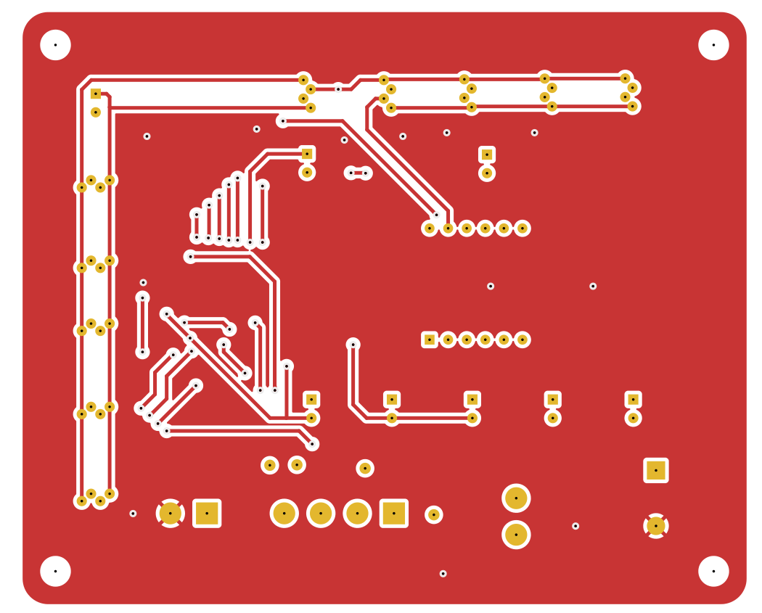
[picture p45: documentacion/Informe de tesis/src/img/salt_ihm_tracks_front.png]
    
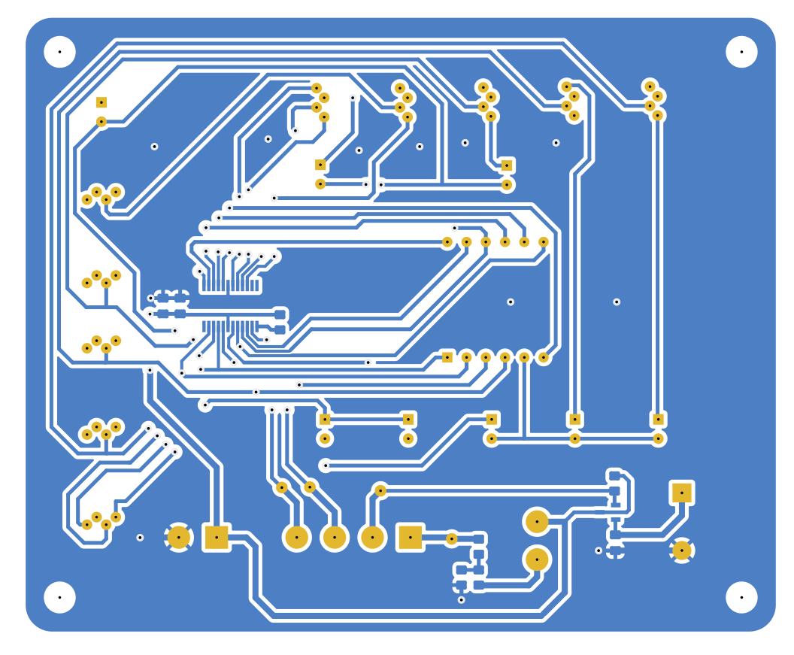
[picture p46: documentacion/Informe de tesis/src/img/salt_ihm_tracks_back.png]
    
    \caption{Pistas y planos de la placa secundaria del SAL/T}
    \label{fig:salt_ihm_tracks}
\end{figure}    

Respecto al PCB (\textit{Printed Circuit Board}), se mandó a fabricar con la empresa JLCWAY \cite{jlcway} en China. Se utilizó el material FR-4, compuesto de fibra de vidrio y resina epoxi, para el substrato por su aislamiento eléctrico, su resistencia térmica y la relación entre rendimiento y costo, lo que lo hace el estándar de la industria de PCBs. Ambas placas se fabricaron con dos capas, la principal con dimensiones de 270 x 260 mm mientras que la placa secundaria utilizada para el panel frontal mide 82 x 100 mm. Se utilizó un grosor de placa de 1,6 mm, placas de color verde con el \textit{silkscreen} (capa de serigrafía que contiene textos y símbolos impresos sobre la placa para identificar componentes, pines y otras marcas importantes durante la fabricación y ensamblaje) de color blanco. En las figuras \ref{fig:salt_3d} y \ref{fig:salt_ihm_3d} se visualizan los modelos 3D de las placas diseñadas: 

\begin{figure}[H]
    \centering
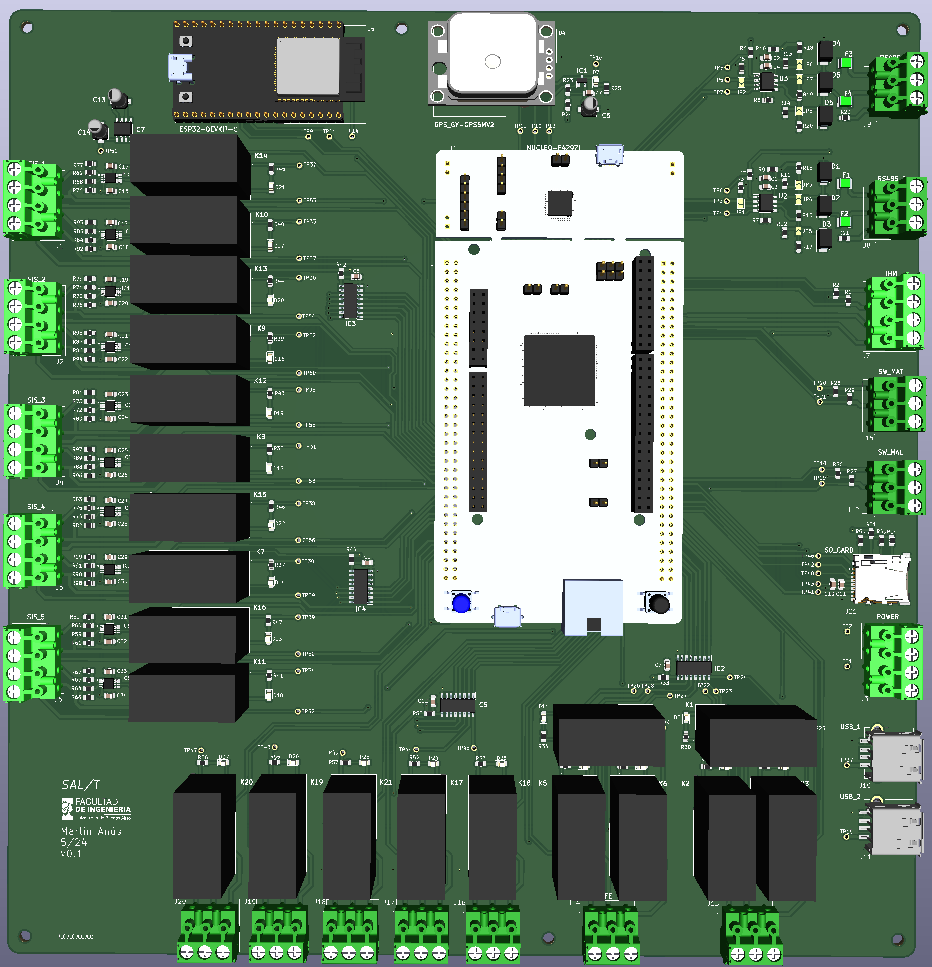
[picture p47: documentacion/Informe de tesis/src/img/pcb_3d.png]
    
    \caption{Modelo 3D de la placa principal del SAL/T}
    \label{fig:salt_3d}
\end{figure}    

\begin{figure}[H]
    \centering
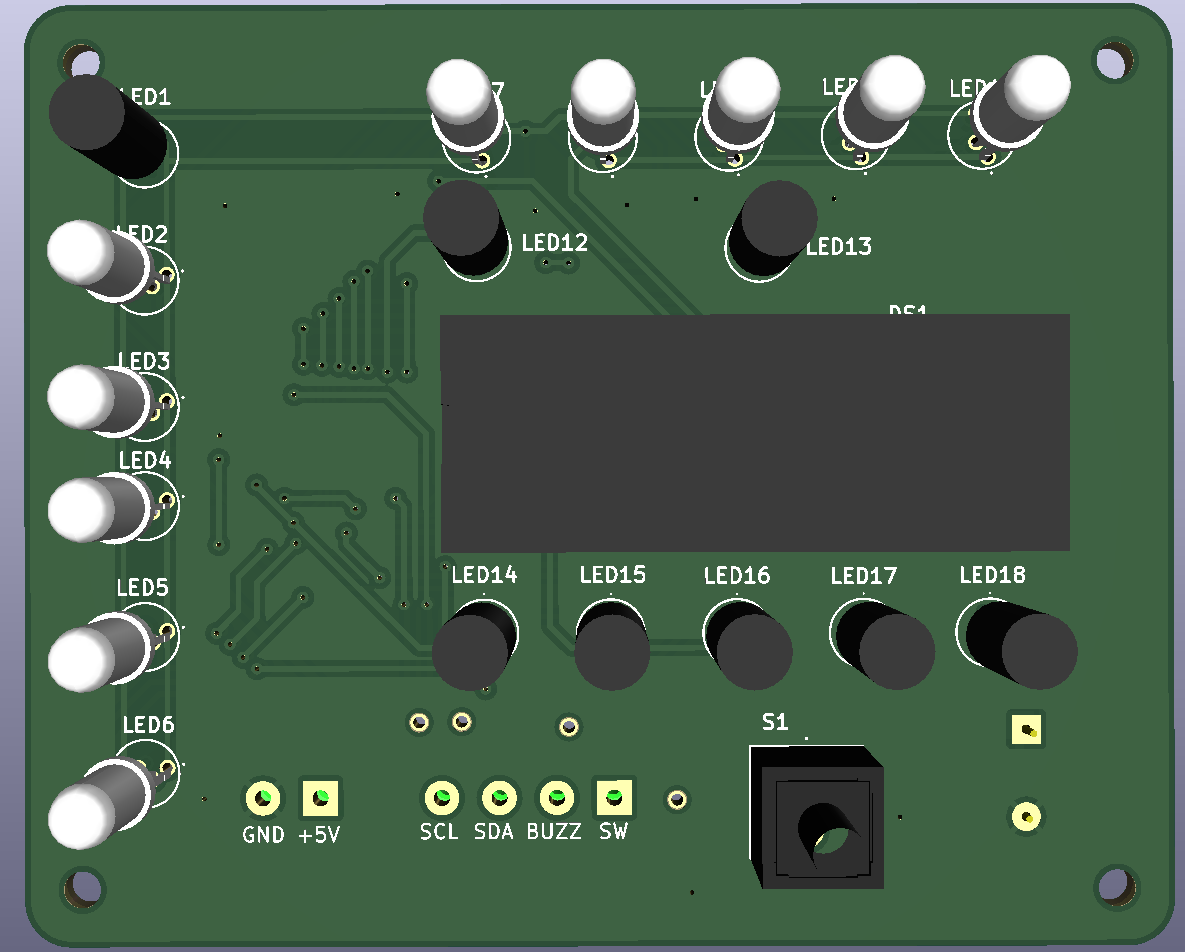
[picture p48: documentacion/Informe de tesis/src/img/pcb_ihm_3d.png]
    
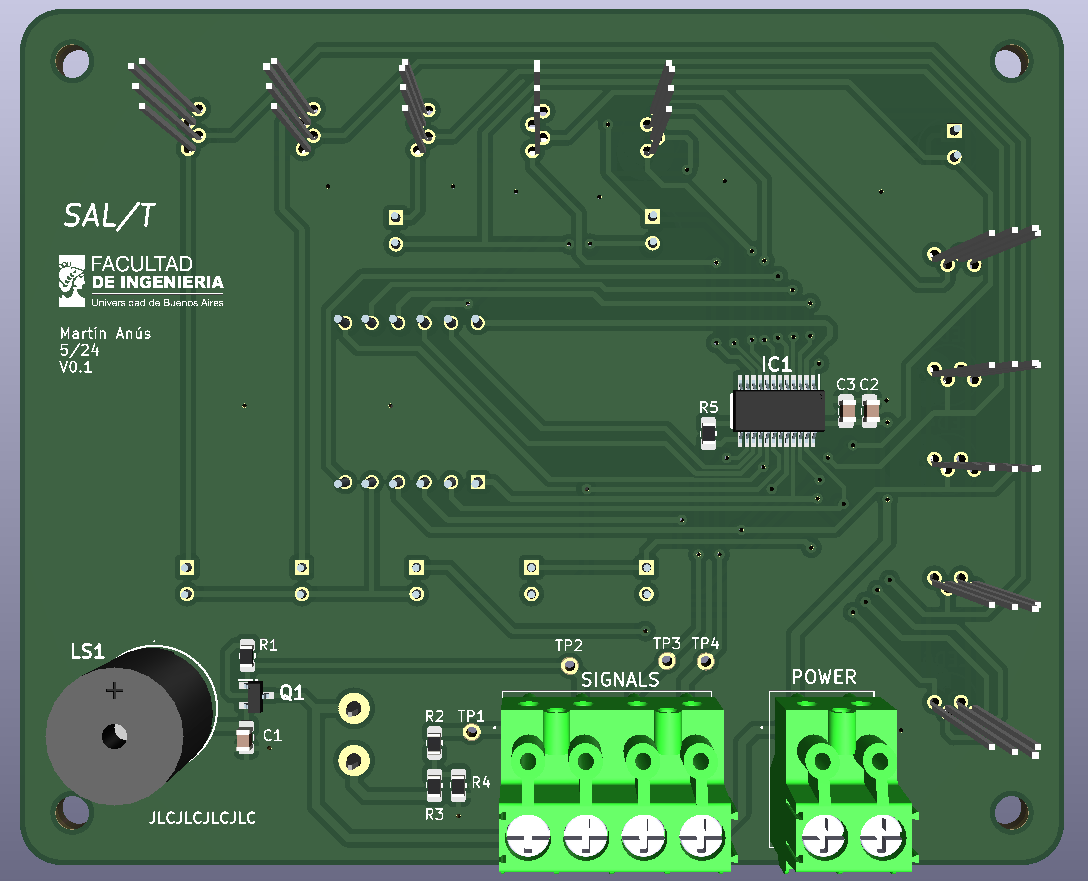
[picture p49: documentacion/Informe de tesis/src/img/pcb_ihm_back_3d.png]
    
    \caption{Modelo 3D de la placa secundaria del SAL/T}
    \label{fig:salt_ihm_3d}
\end{figure}    

Los componentes fueron soldados a mano utilizando soldaduras de estaño. En las figuras \ref{fig:pcb_salt} y \ref{fig:pcb_salt_ihm} se visualiza la placa principal y la placa secundaria armada con todos los componentes montados. 

\begin{figure}[H]
    \centering
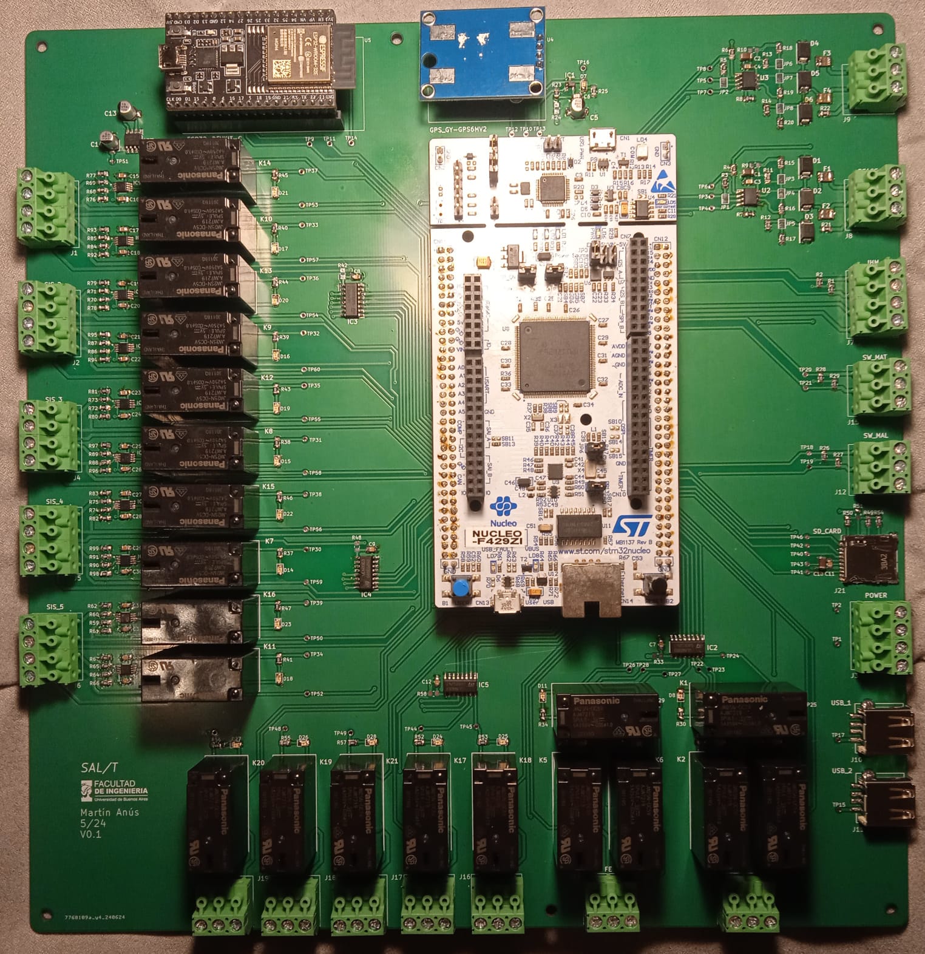
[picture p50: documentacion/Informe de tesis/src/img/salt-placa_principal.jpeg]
    
    \caption{Placa principal del SAL/T fabricada}
    \label{fig:pcb_salt}
\end{figure}    

\begin{figure}[H]
    \centering
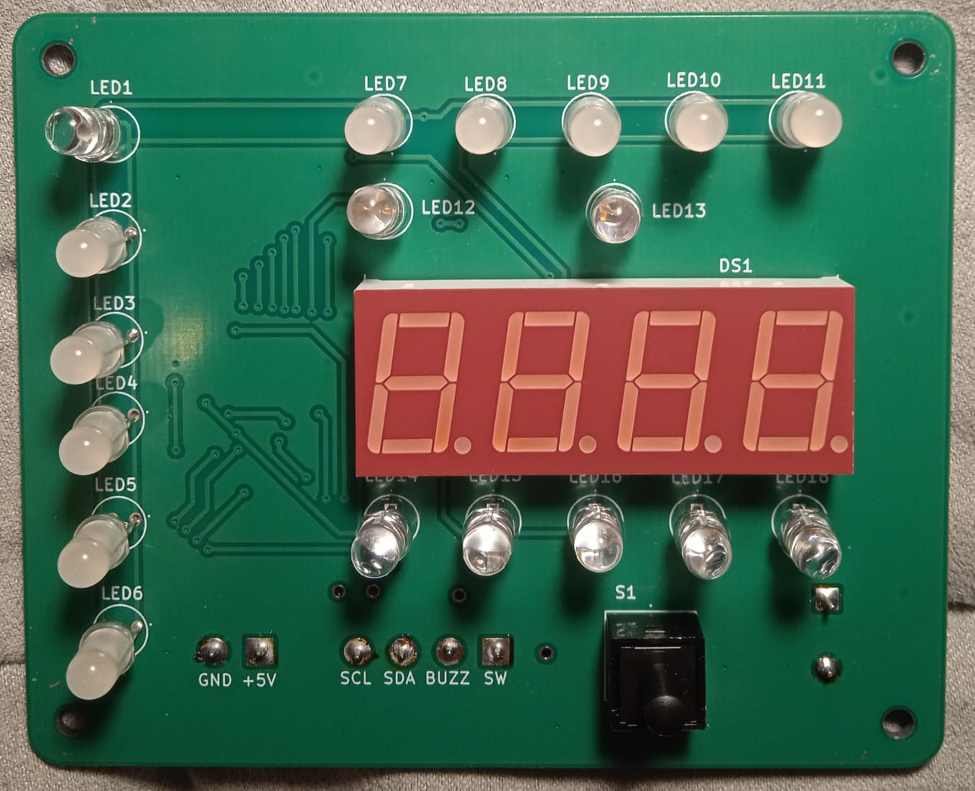
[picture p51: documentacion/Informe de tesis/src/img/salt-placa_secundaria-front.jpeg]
    
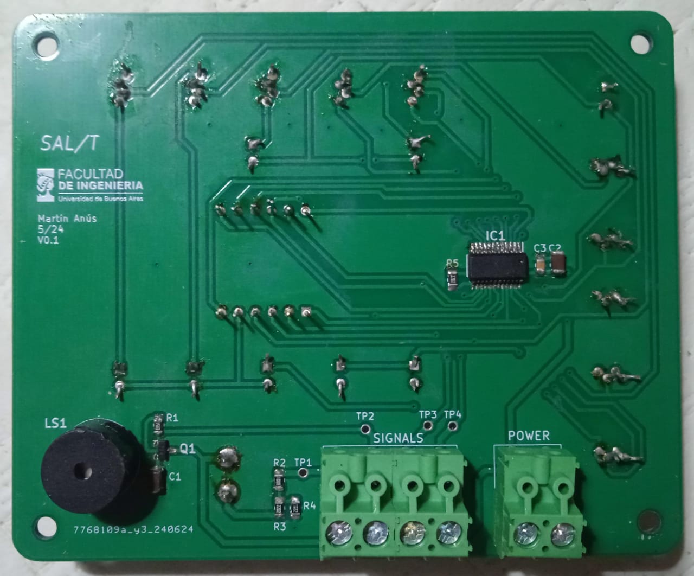
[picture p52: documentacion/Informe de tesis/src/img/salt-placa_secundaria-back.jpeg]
    
    \caption{Placa secundaria del SAL/T fabricada}
    \label{fig:pcb_salt_ihm}
\end{figure}

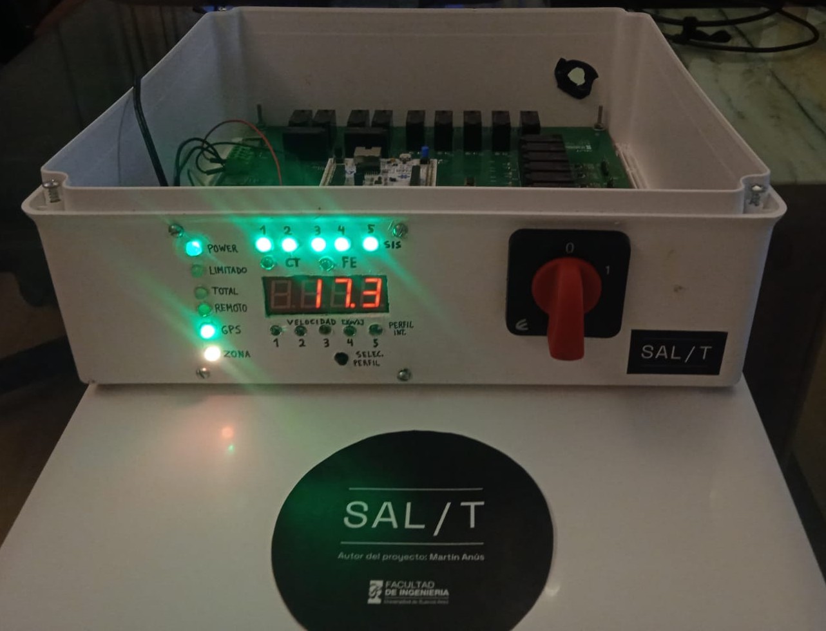
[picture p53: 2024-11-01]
documentacion/Informe de tesis/src/img/salt_fabricado.jpeg

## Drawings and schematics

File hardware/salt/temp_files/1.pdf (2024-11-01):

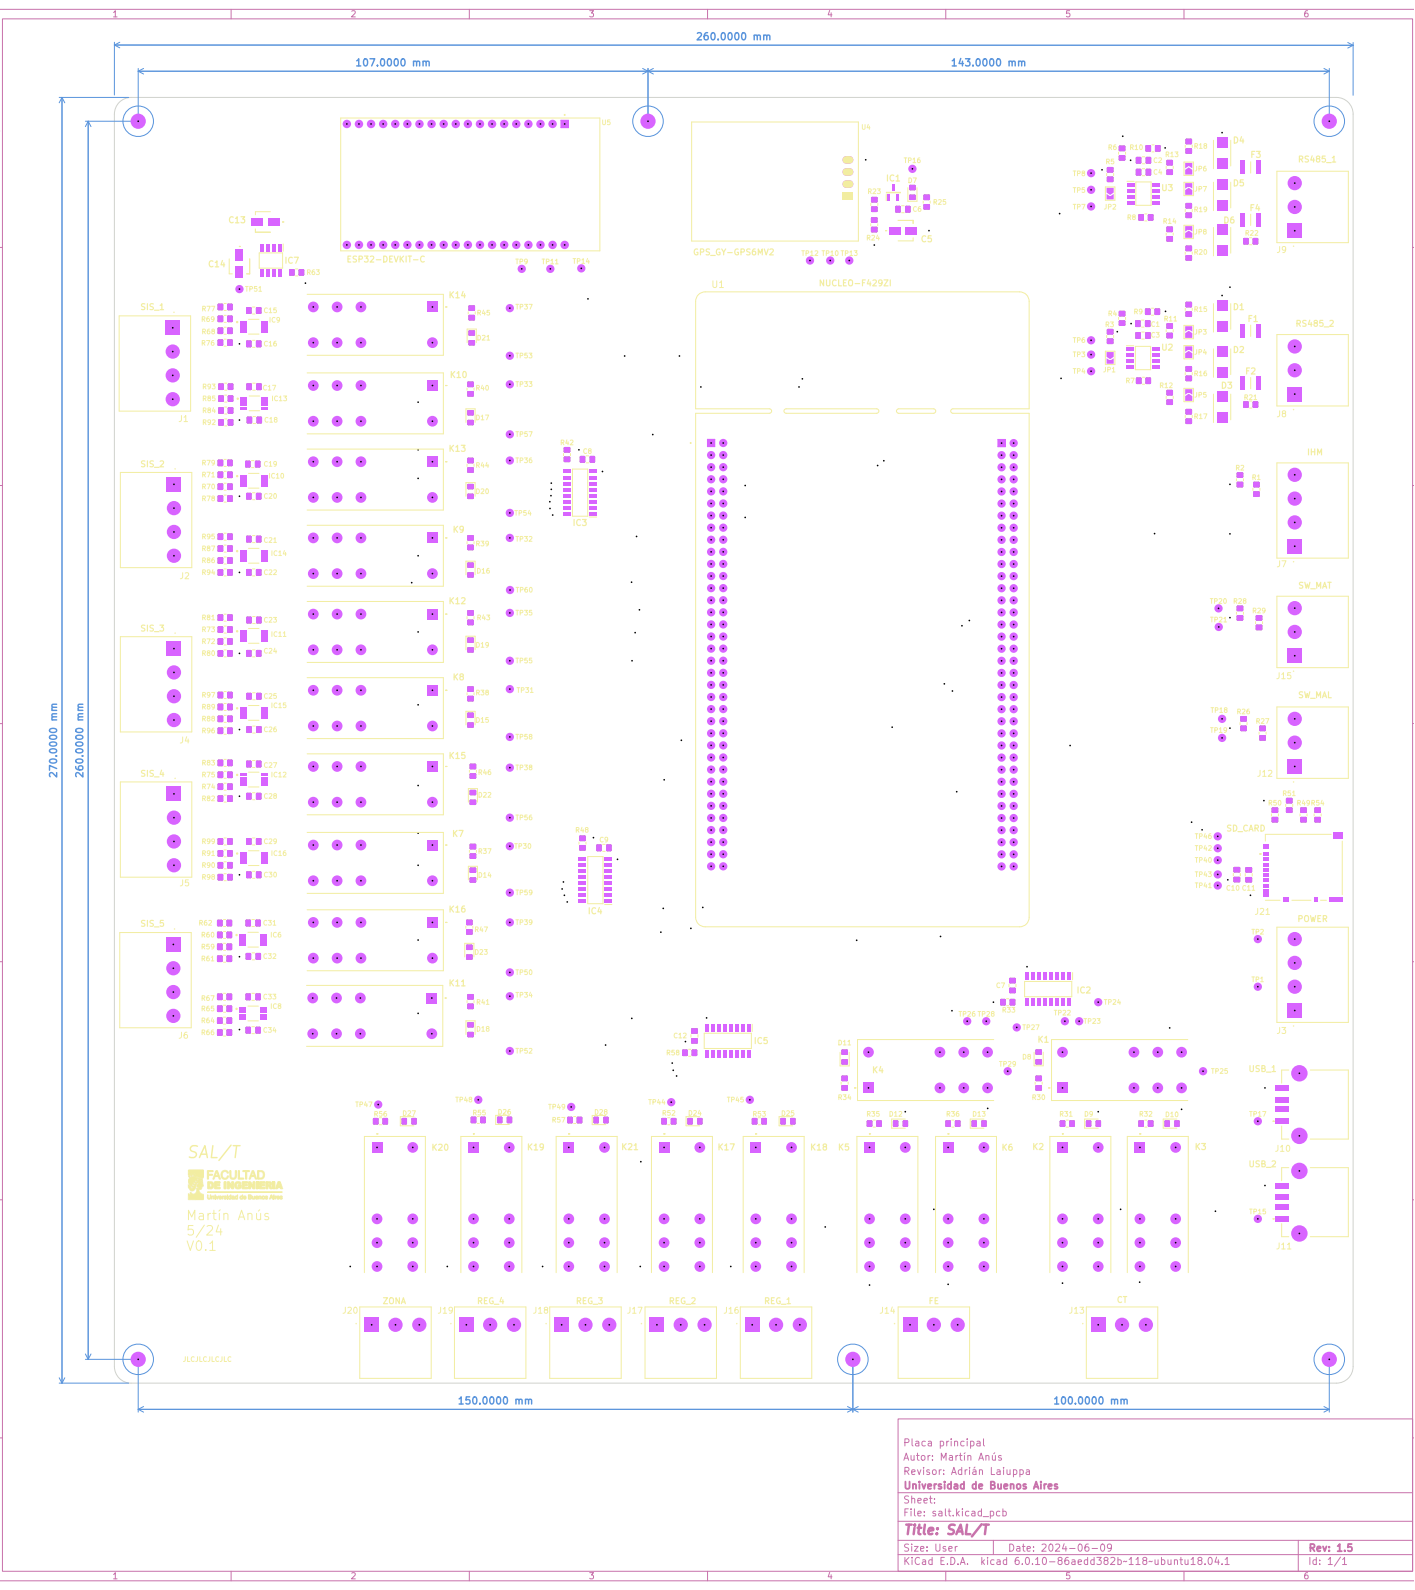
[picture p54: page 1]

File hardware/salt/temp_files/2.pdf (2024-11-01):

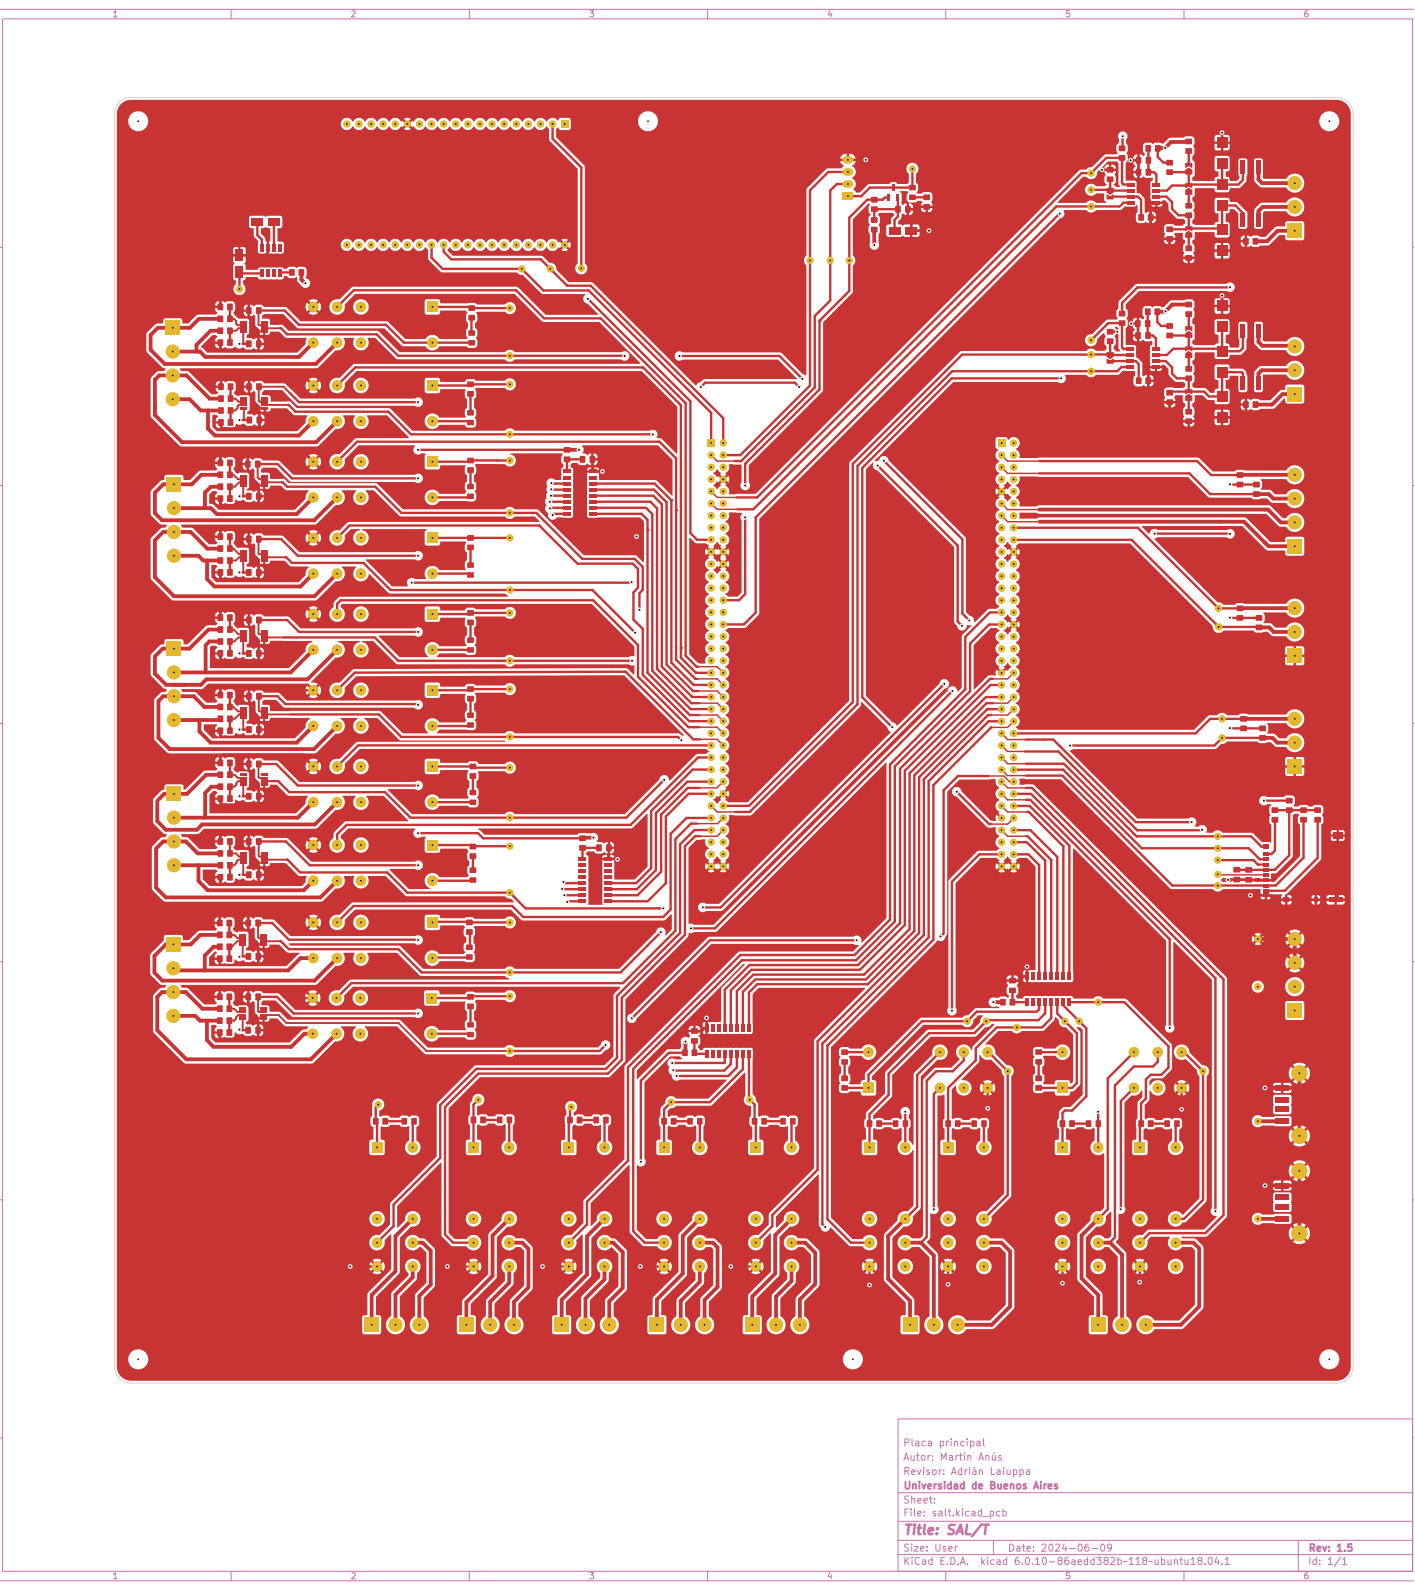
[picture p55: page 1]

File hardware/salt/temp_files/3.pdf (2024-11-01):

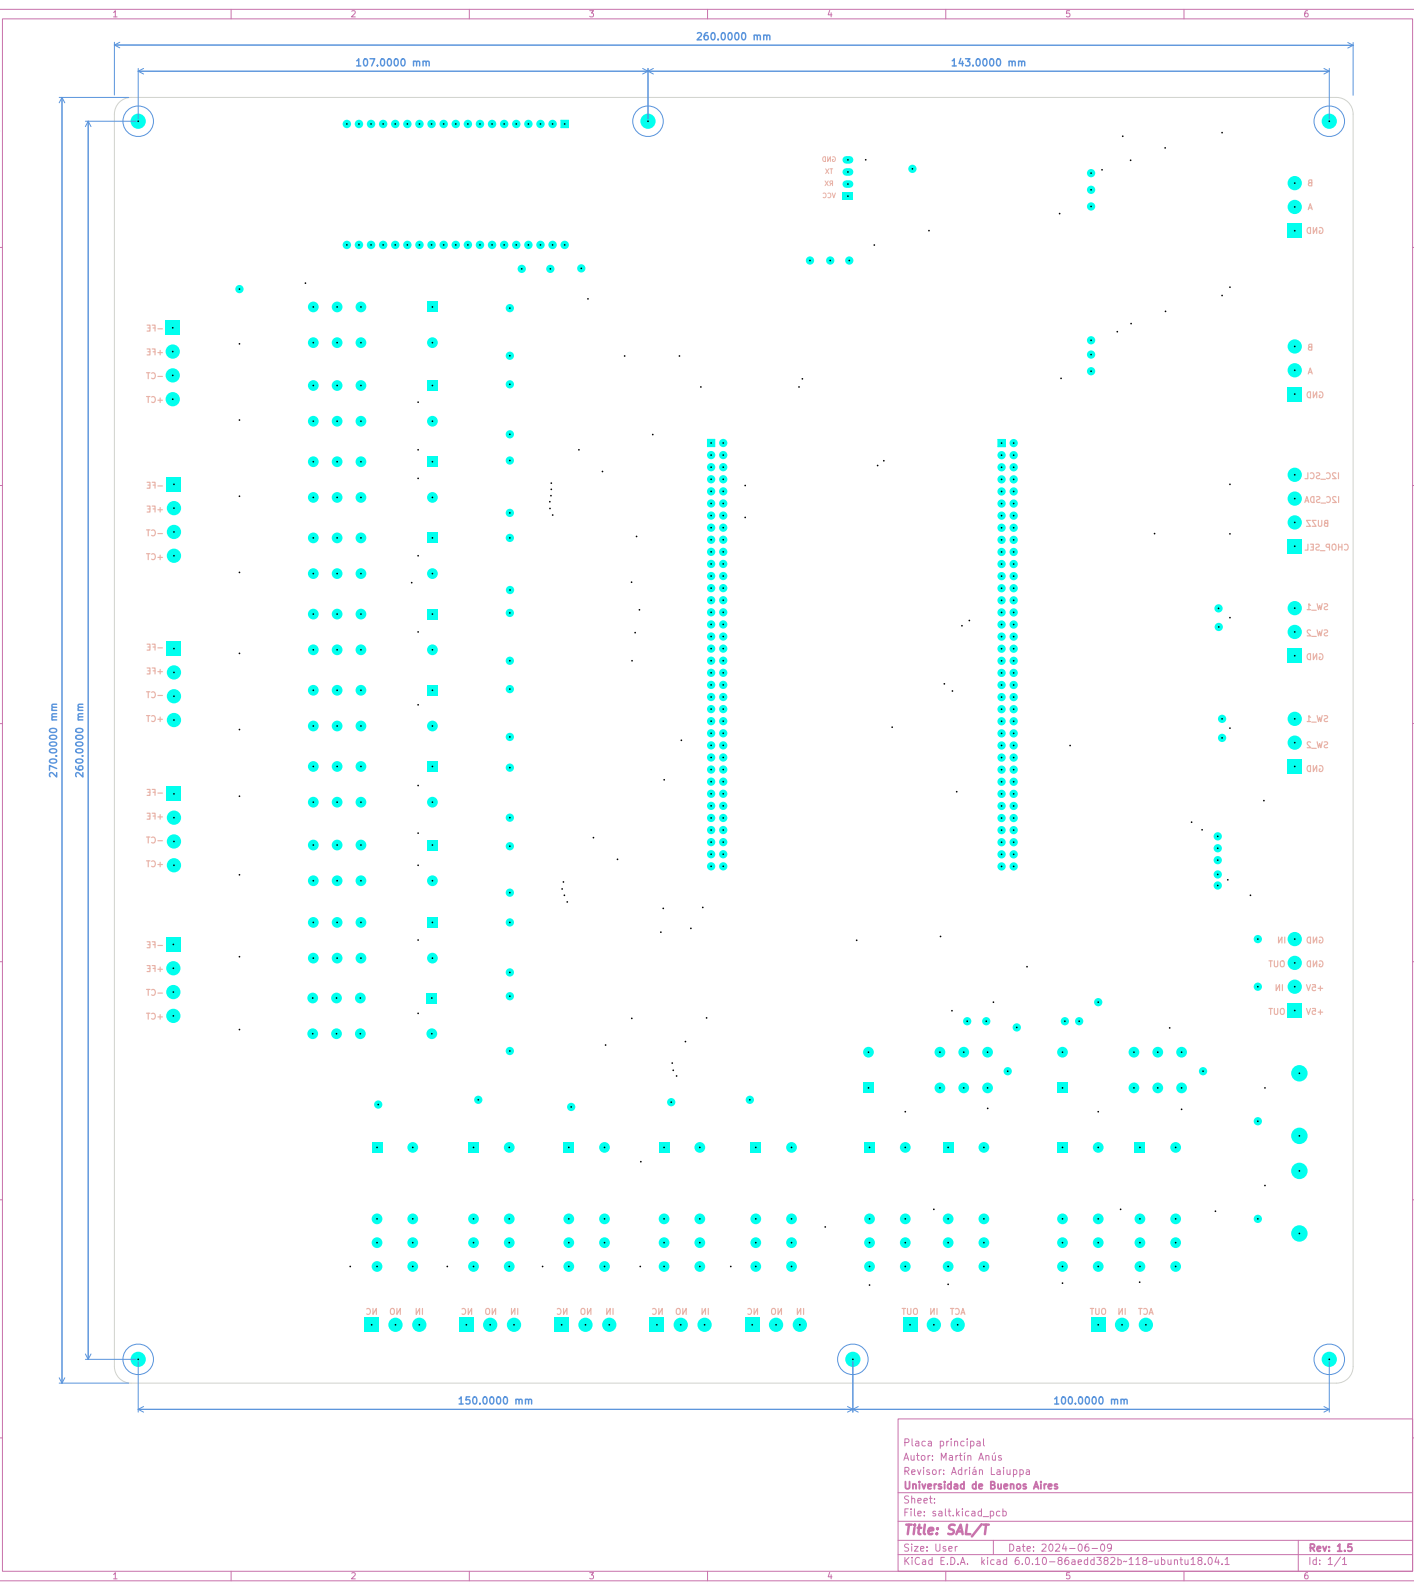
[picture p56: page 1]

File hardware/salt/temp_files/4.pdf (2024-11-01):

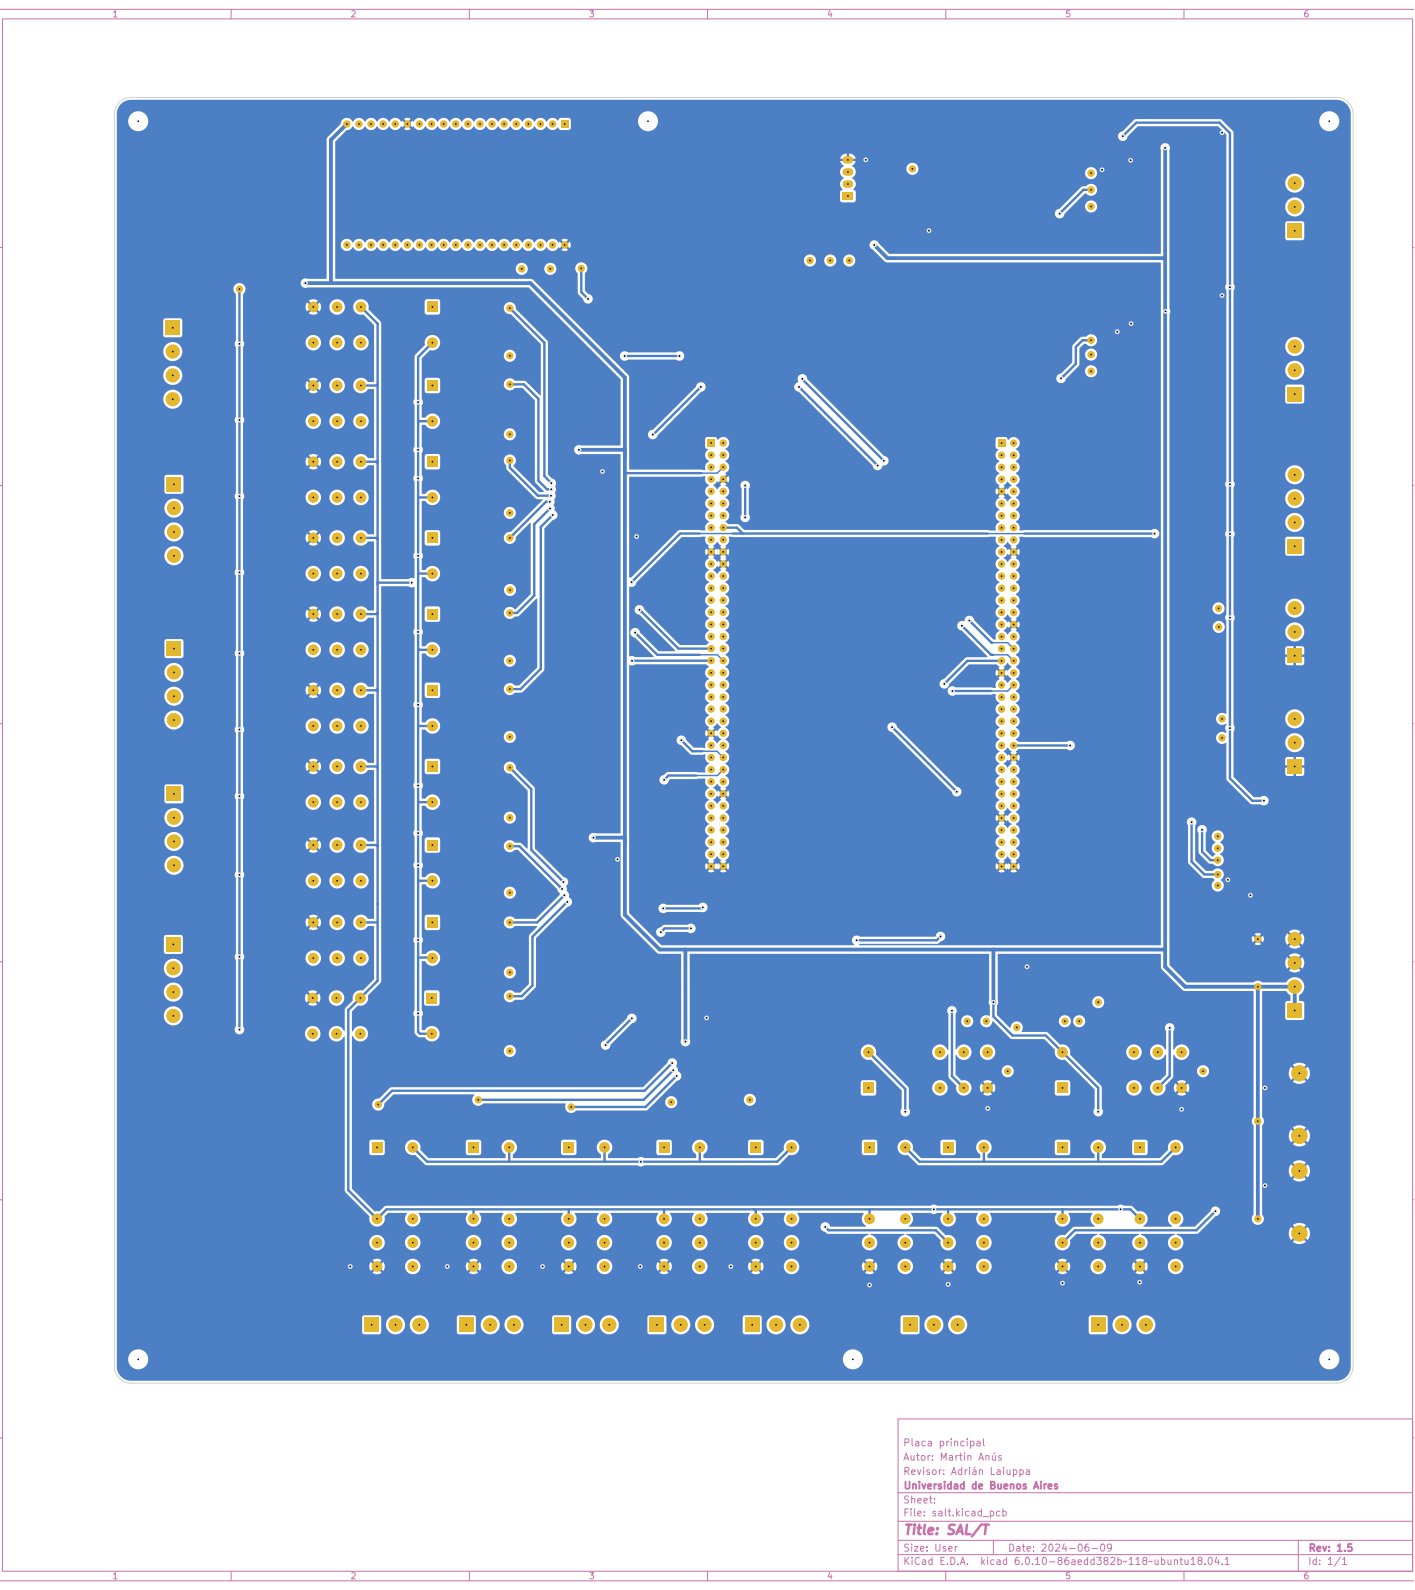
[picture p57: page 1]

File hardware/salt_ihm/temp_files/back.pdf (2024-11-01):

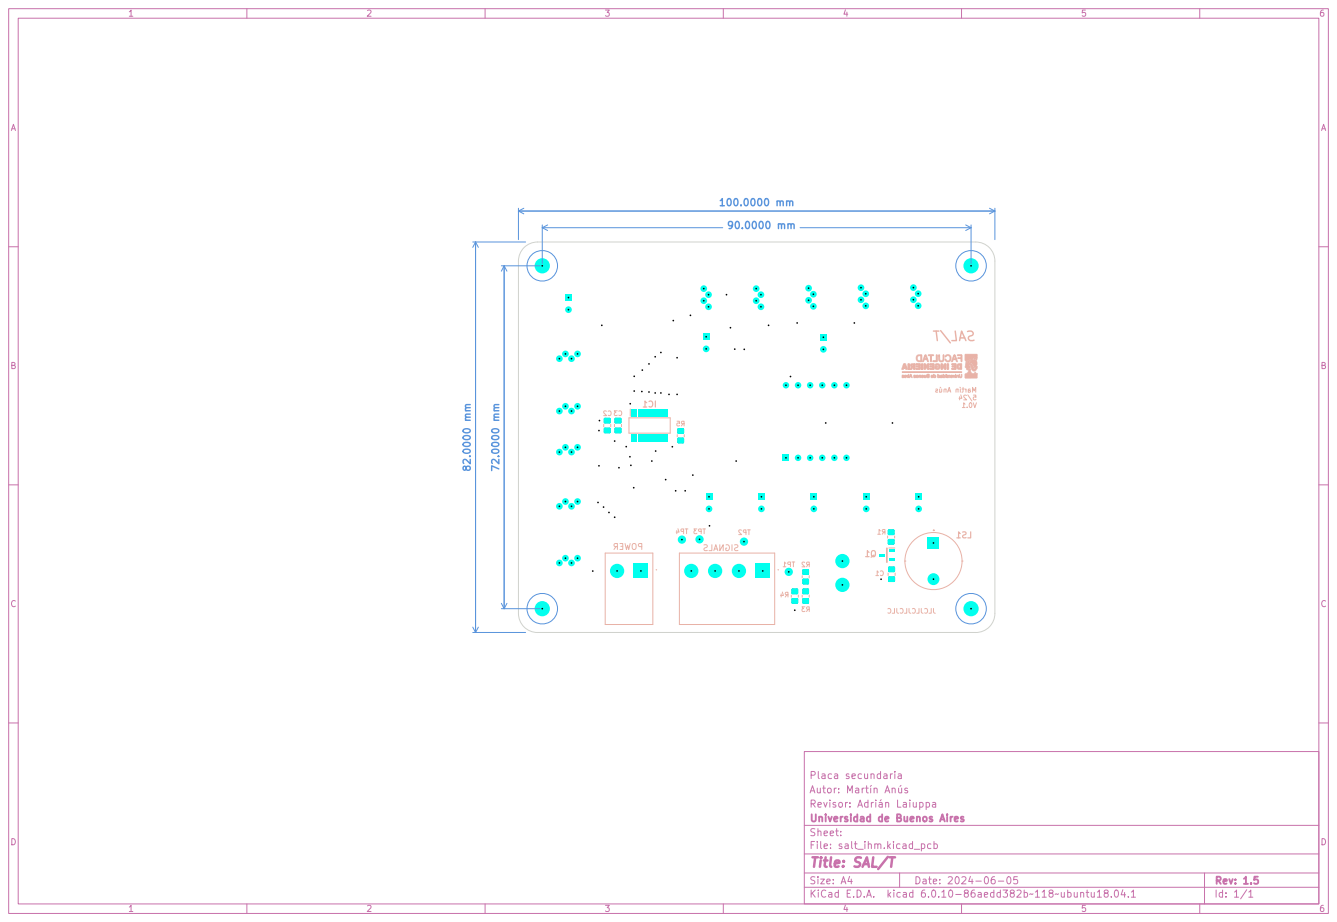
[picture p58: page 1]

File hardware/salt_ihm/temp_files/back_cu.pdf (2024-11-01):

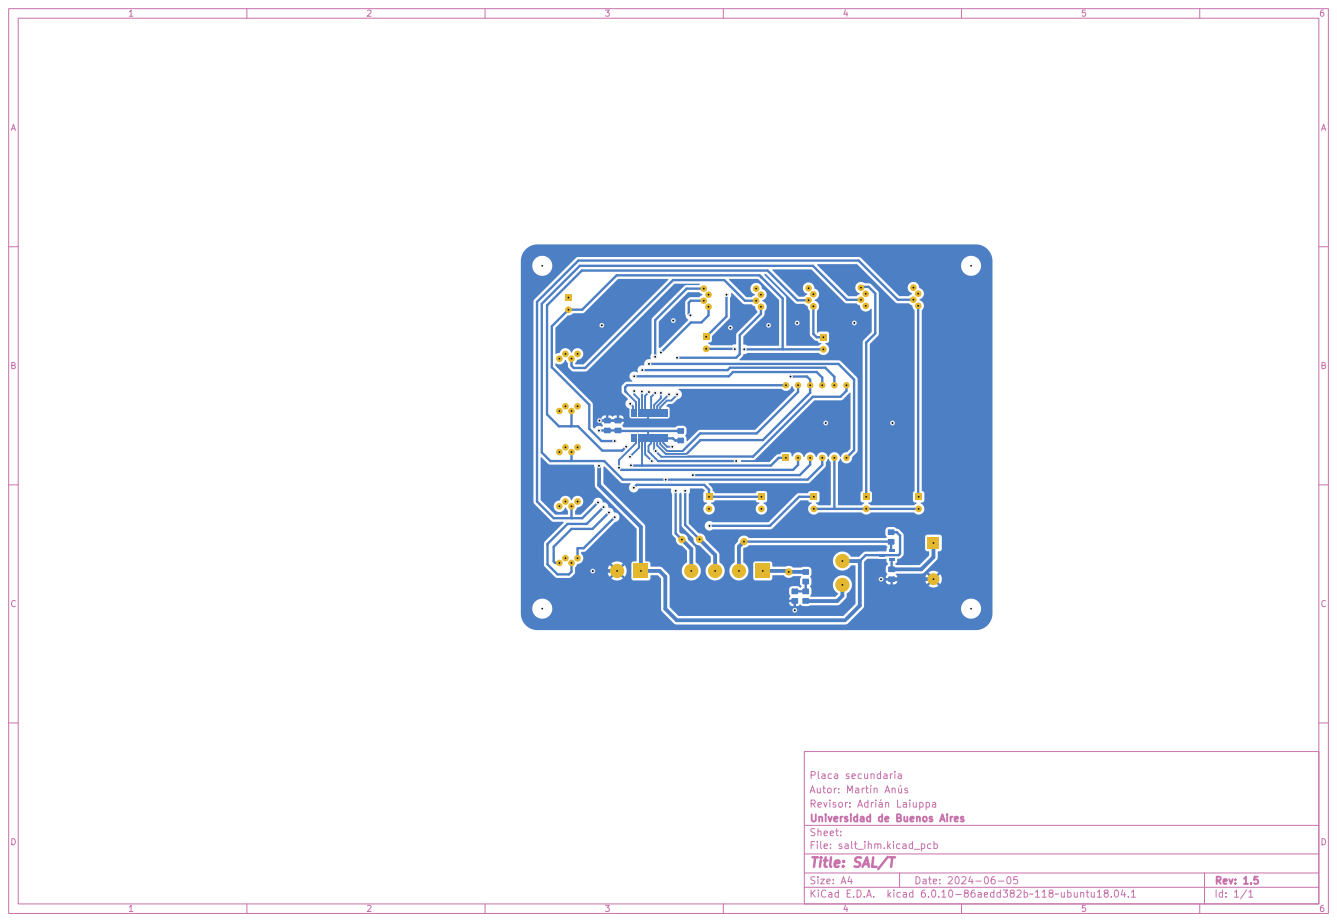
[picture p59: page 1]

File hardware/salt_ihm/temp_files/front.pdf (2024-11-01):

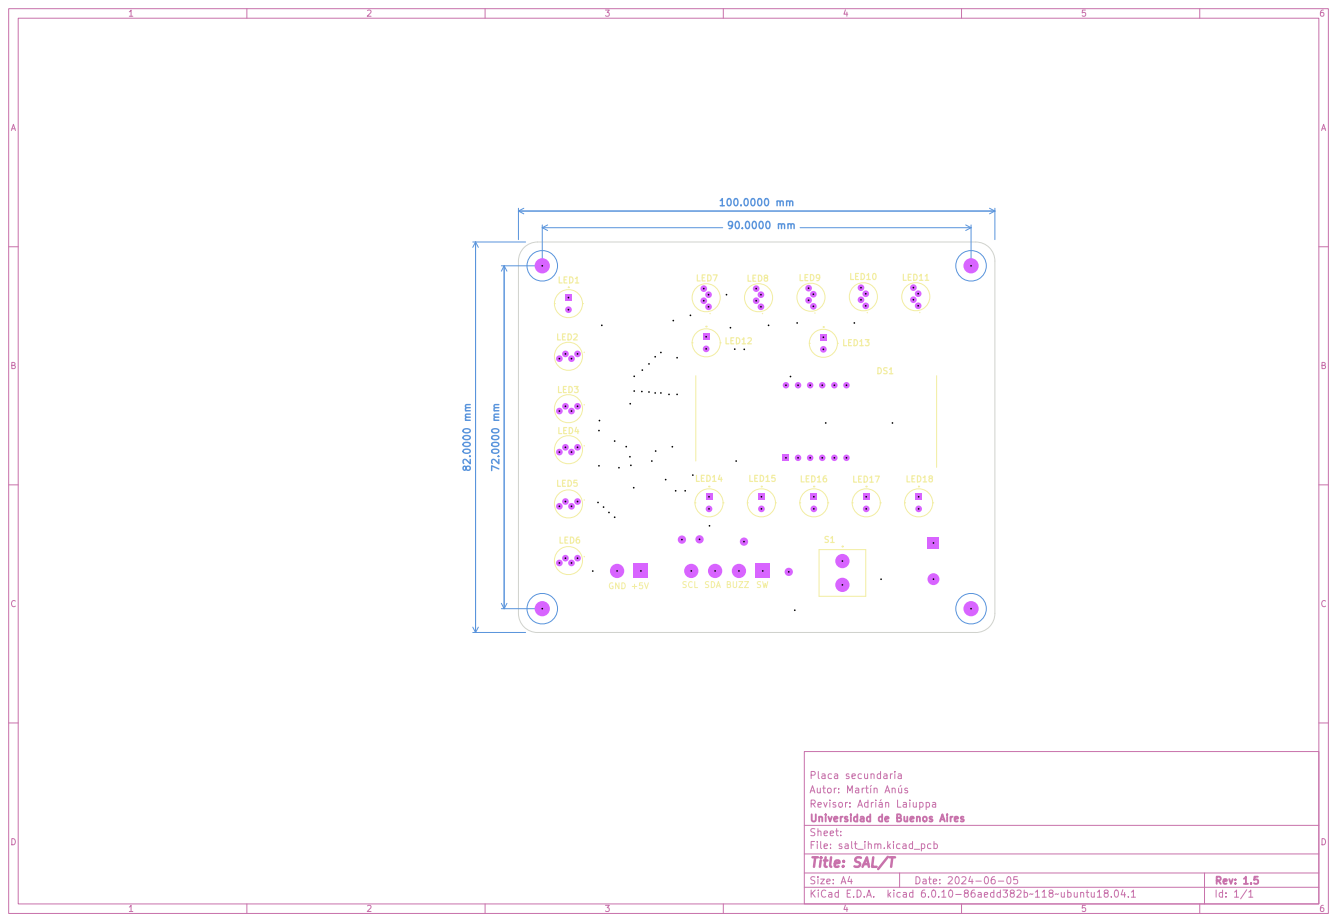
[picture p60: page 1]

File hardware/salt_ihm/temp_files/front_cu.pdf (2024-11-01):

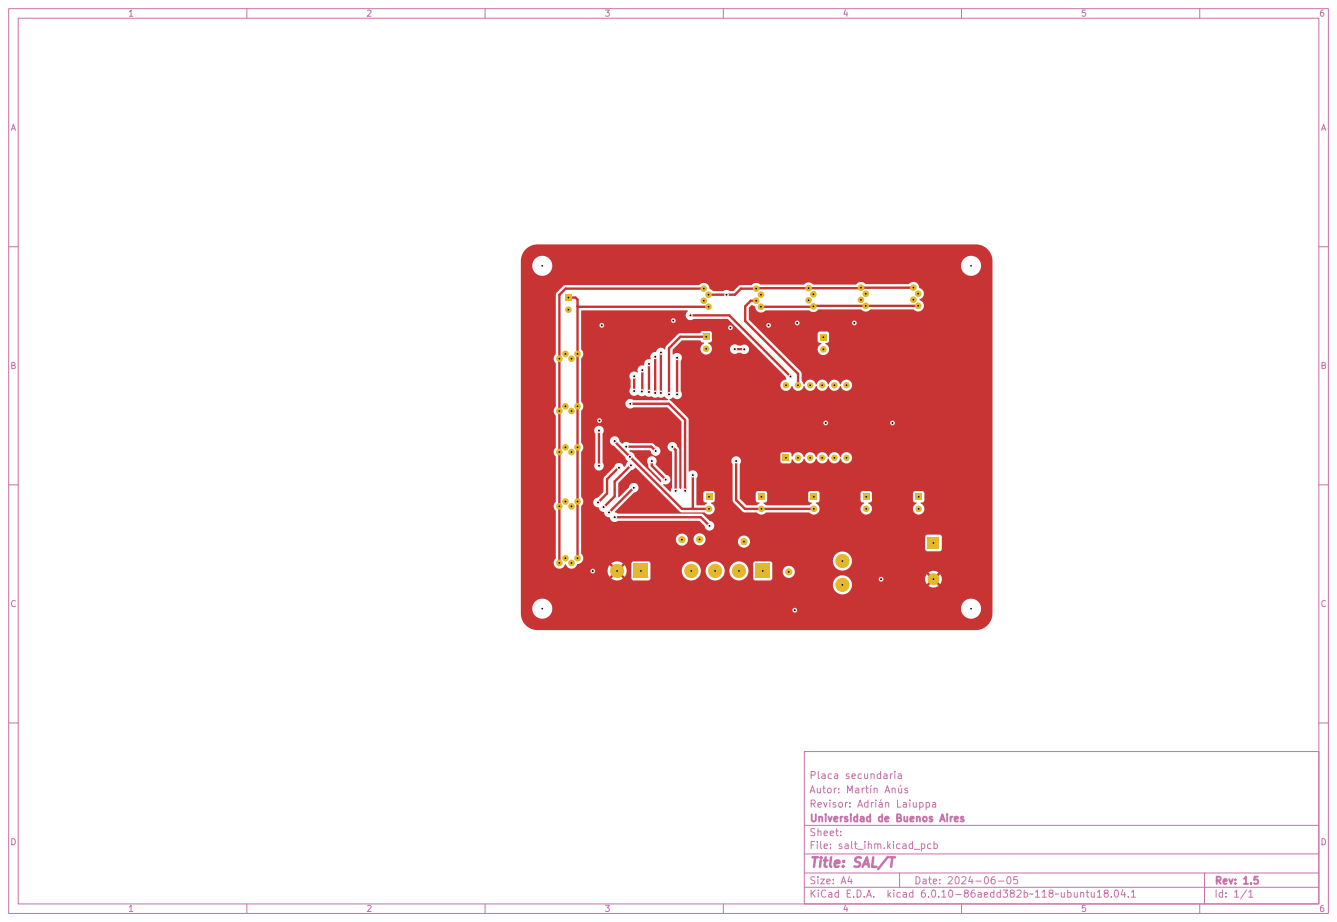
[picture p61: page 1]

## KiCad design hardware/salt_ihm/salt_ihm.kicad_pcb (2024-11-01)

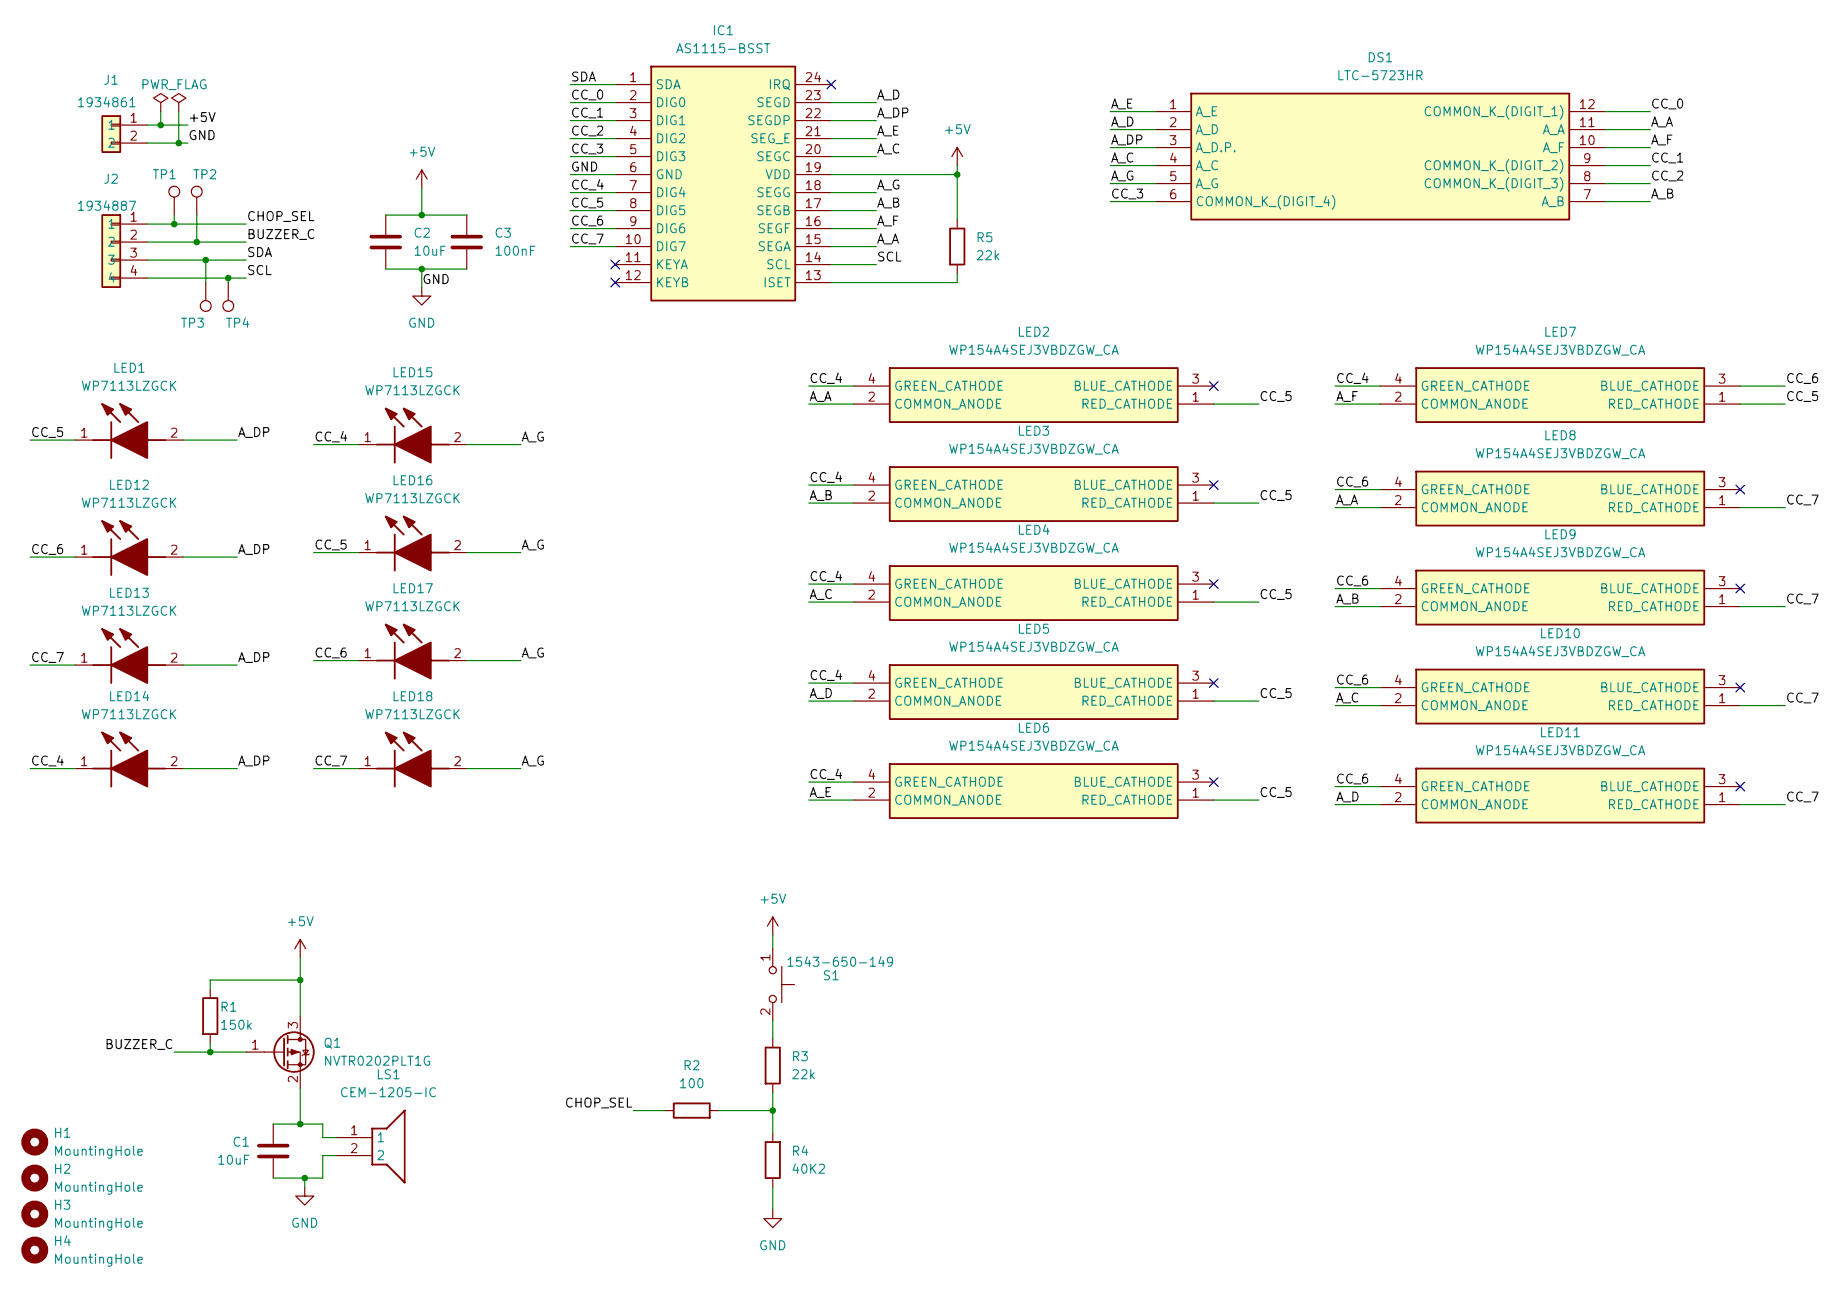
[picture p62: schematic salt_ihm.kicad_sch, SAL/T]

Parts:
C1, C2: 10uF; C_0805_2012Metric_Pad1.18x1.45mm_HandSolder; Mouser Part Number 80-C1206C106K4R
C3: 100nF; C_0805_2012Metric_Pad1.18x1.45mm_HandSolder; Mouser Part Number 80-C0805C104K4R
DS1: LTC-5723HR; DIP1524W75P254L5030H825Q12N; Mouser Part Number 859-LTC-5723HR
H1, H2, H3, H4: MountingHole; MountingHole_3.2mm_M3
IC1: AS1115-BSST; SOP64P600X175-24N; Mouser Part Number 985-AS1115-BSST
J1: 1934861; Mouser Part Number 651-1934861
J2: 1934887; Mouser Part Number 651-1934887
LED1, LED12, LED13, LED14, LED15, LED16, LED17, LED18: WP7113LZGCK; Mouser Part Number 604-WP7113LZGCK
LED2, LED3, LED4, LED5, LED6, LED7, LED8, LED9, LED10, LED11: WP154A4SEJ3VBDZGW_CA; L-154A4SUREQBFZGEC; Mouser Part Number 604-WP154A43VBDZGWCA
LS1: CEM-1205-IC; CEM1205IC; Mouser Part Number 490-CEM1205IC
Q1: NVTR0202PLT1G; SOT96P237X111-3N; Mouser Part Number 863-NVTR0202PLT1G
R1: 150k; R_0805_2012Metric_Pad1.20x1.40mm_HandSolder; Mouser Part Number 603-RC0805FR-13150KL
R2: 100; R_0805_2012Metric_Pad1.20x1.40mm_HandSolder; Mouser Part Number 603-RC0805FR-10100RL
R3, R5: 22k; R_0805_2012Metric_Pad1.20x1.40mm_HandSolder; Mouser Part Number 603-RC0805FR-1022KL
R4: 40K2; R_0805_2012Metric_Pad1.20x1.40mm_HandSolder; Mouser Part Number 603-RC0805FR-0740K2L
S1: 1543-650-149; 1543650149; Mouser Part Number 652-1543-650-149
TP1, TP2, TP3, TP4: TestPoint; testpoint

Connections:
+5V: C2.1, C3.1, IC1.19 (VDD), J1.1, Q1.3 (D), R1.1, R5.1, S1.1
/A_A: DS1.11 (A_A), IC1.15 (SEGA), LED2.2 (COMMON_ANODE), LED8.2 (COMMON_ANODE)
/A_B: DS1.7 (A_B), IC1.17 (SEGB), LED3.2 (COMMON_ANODE), LED9.2 (COMMON_ANODE)
/A_C: DS1.4 (A_C), IC1.20 (SEGC), LED4.2 (COMMON_ANODE), LED10.2 (COMMON_ANODE)
/A_D: DS1.2 (A_D), IC1.23 (SEGD), LED5.2 (COMMON_ANODE), LED11.2 (COMMON_ANODE)
/A_DP: DS1.3 (A_D.P.), IC1.22 (SEGDP), LED1.2 (A), LED12.2 (A), LED13.2 (A), LED14.2 (A)
/A_E: DS1.1 (A_E), IC1.21 (SEG_E), LED6.2 (COMMON_ANODE)
/A_F: DS1.10 (A_F), IC1.16 (SEGF), LED7.2 (COMMON_ANODE)
/A_G: DS1.5 (A_G), IC1.18 (SEGG), LED15.2 (A), LED16.2 (A), LED17.2 (A), LED18.2 (A)
/BUZZER_C: J2.2, Q1.1 (G), R1.2, TP2.1
/CC_0: DS1.12 (COMMON_K_(DIGIT_1)), IC1.2 (DIG0)
/CC_1: DS1.9 (COMMON_K_(DIGIT_2)), IC1.3 (DIG1)
/CC_2: DS1.8 (COMMON_K_(DIGIT_3)), IC1.4 (DIG2)
/CC_3: DS1.6 (COMMON_K_(DIGIT_4)), IC1.5 (DIG3)
/CC_4: IC1.7 (DIG4), LED2.4 (GREEN_CATHODE), LED3.4 (GREEN_CATHODE), LED4.4 (GREEN_CATHODE), LED5.4 (GREEN_CATHODE), LED6.4 (GREEN_CATHODE), LED7.4 (GREEN_CATHODE), LED14.1 (K), LED15.1 (K)
/CC_5: IC1.8 (DIG5), LED1.1 (K), LED2.1 (RED_CATHODE), LED3.1 (RED_CATHODE), LED4.1 (RED_CATHODE), LED5.1 (RED_CATHODE), LED6.1 (RED_CATHODE), LED7.1 (RED_CATHODE), LED16.1 (K)
/CC_6: IC1.9 (DIG6), LED7.3 (BLUE_CATHODE), LED8.4 (GREEN_CATHODE), LED9.4 (GREEN_CATHODE), LED10.4 (GREEN_CATHODE), LED11.4 (GREEN_CATHODE), LED12.1 (K), LED17.1 (K)
/CC_7: IC1.10 (DIG7), LED8.1 (RED_CATHODE), LED9.1 (RED_CATHODE), LED10.1 (RED_CATHODE), LED11.1 (RED_CATHODE), LED13.1 (K), LED18.1 (K)
/CHOP_SEL: J2.1, R2.1, TP1.1
/SCL: IC1.14 (SCL), J2.4, TP4.1
/SDA: IC1.1 (SDA), J2.3, TP3.1
GND: C1.1, C2.2, C3.2, IC1.6 (GND), J1.2, LS1.2, R4.1
unnamed: C1.2, LS1.1, Q1.2 (S)
unnamed: IC1.13 (ISET), R5.2
unnamed: R2.2, R3.2, R4.2
unnamed: R3.1, S1.2

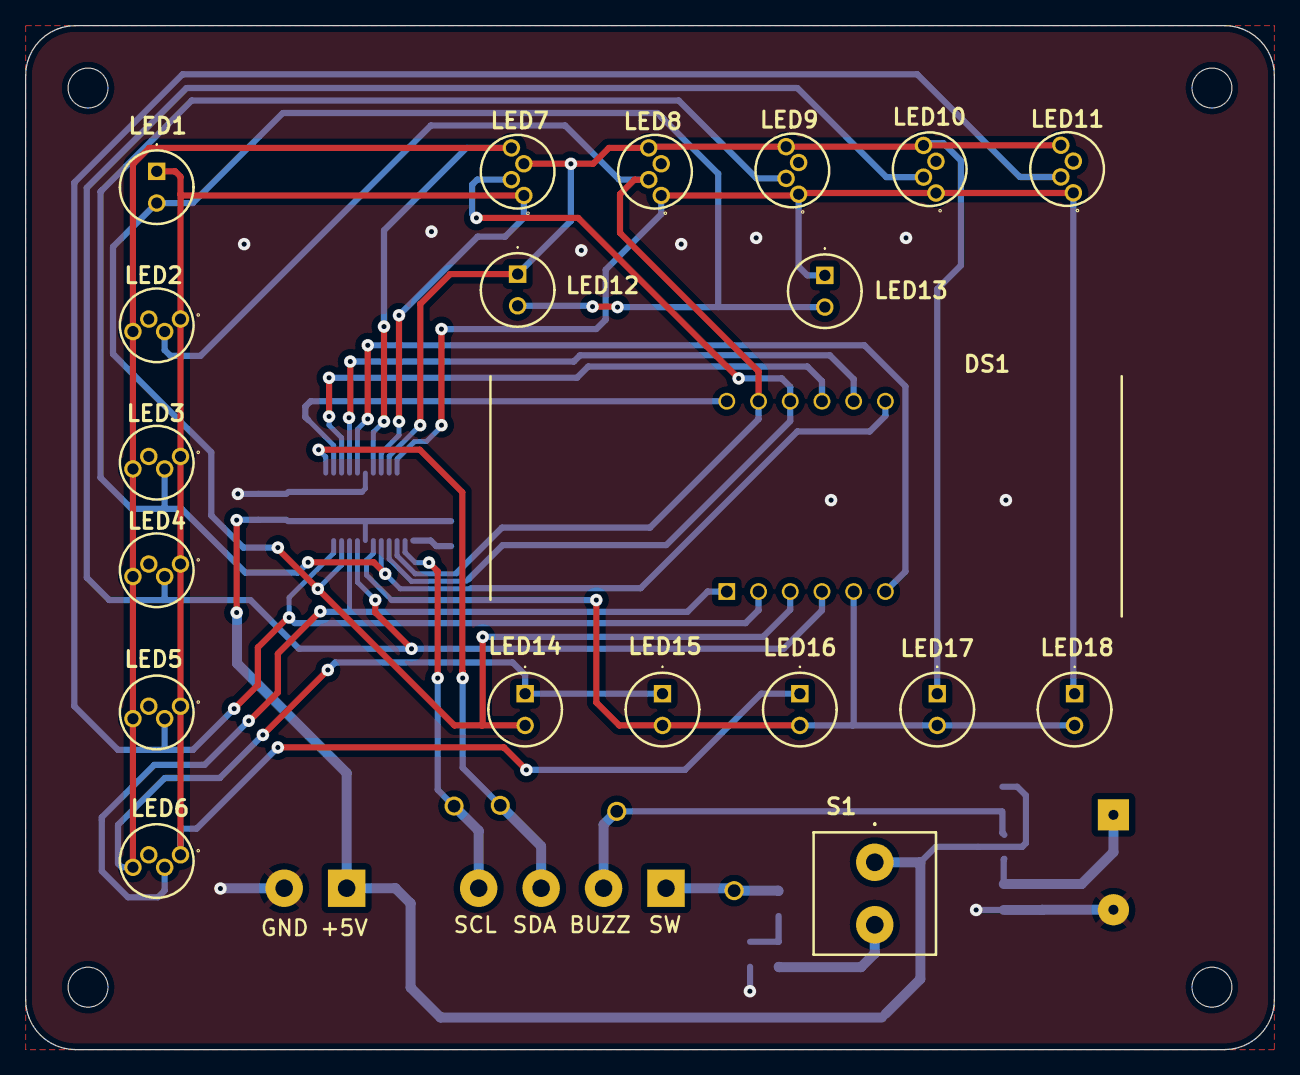
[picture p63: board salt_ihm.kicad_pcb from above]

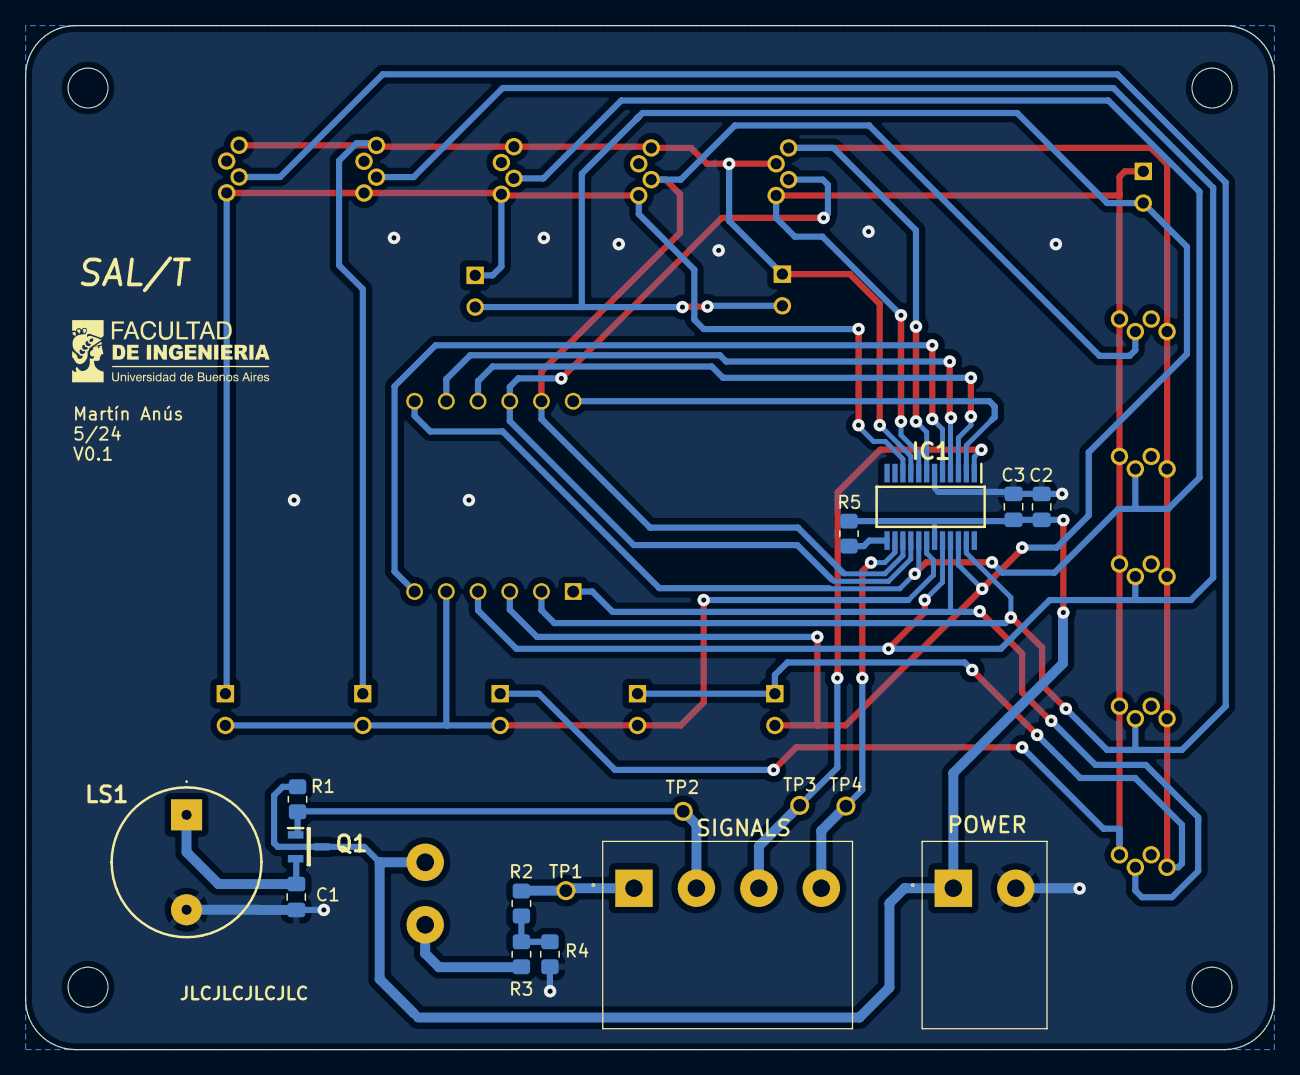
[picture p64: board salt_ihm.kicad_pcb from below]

Board: 2 copper layers, 100.0 x 82.0 mm, 41 parts (17 on the bottom side), 26 nets.

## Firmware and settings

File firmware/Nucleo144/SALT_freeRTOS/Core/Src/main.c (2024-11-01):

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
/* Includes ------------------------------------------------------------------*/
#include "main.h"
#include "cmsis_os.h"
#include "fatfs.h"

/* USER CODE BEGIN Includes */
#include "stdio.h"
#include "string.h"
#include "gps.h"
#include "sd.h"
#include "led_driver.h"

#include "globals.h"

/* USER CODE END Includes */

ADC_HandleTypeDef hadc3;
DMA_HandleTypeDef hdma_adc3;

I2C_HandleTypeDef hi2c1;

RTC_HandleTypeDef hrtc;

SPI_HandleTypeDef hspi4;

UART_HandleTypeDef huart4;
UART_HandleTypeDef huart5;
UART_HandleTypeDef huart7;
UART_HandleTypeDef huart8;
UART_HandleTypeDef huart3;

osThreadId modeTransTaskHandle;
osThreadId systemTaskHandle;
osThreadId criticalSigTaskHandle;
osThreadId reportTaskHandle;
osThreadId commsTaskHandle;
osSemaphoreId commsSemHandle;
/* USER CODE BEGIN PV */
const char *salt_mode_labels[] = SALT_MODE_LABELS;
const char *local_log_file_name = "registro.txt";

salt_mode_t salt_mode = MODO_NORMAL;
status_t internal_error = STATUS_OK;

uint8_t report_status_period_s = REPORT_STATUS_PERIOD_S;
uint8_t command_validity_s = COMMAND_VALIDITY_INITIAL;
uint8_t speed_configs[4][4] = {
    NO_ZONE_SPEED_CONFIG_INITIAL,
    ZONE_1_SPEED_CONFIG_INITIAL,
    ZONE_2_SPEED_CONFIG_INITIAL,
    ZONE_3_SPEED_CONFIG_INITIAL};

uint8_t chop_profile_config[5][4] = {
    CHOP_PROFILE_1_INITIAL,
    CHOP_PROFILE_2_INITIAL,
    CHOP_PROFILE_3_INITIAL,
    CHOP_PROFILE_4_INITIAL,
    CHOP_PROFILE_5_INITIAL};

FATFS fs;
char remote_command[MAX_COMMAND_LENGTH];
command_states_t remote_command_active;

comm_t commToProcess = NO_COMM;

char WIFIline[MAX_BUFFER_LENGTH];
char GPSline[MAX_COMMAND_LENGTH];
char rs485_1_line[MAX_BUFFER_LENGTH];
char rs485_2_line[MAX_BUFFER_LENGTH];
char localSerial_line[MAX_BUFFER_LENGTH];

char local_log_buffer[MAX_LOG_LENGTH];
uint32_t gps_dataMillis = 0;
uint32_t rs485_1_dataMillis = 0;
uint32_t rs485_2_dataMillis = 0;

volatile uint16_t adc_results_dma[10];
volatile uint8_t ADC_ConvCplt = 0;
const int adcChannelCount = sizeof(adc_results_dma) / sizeof(adc_results_dma[0]);
SIS_state_t SIS_state[5];

float speed;
speed_source_t speed_source;
status_t gps_status;
zones_t current_zone;

critical_signal_state_t CT_signal;
critical_signal_state_t FE_signal;

uint32_t modo_limitado_activationMillis = 0;
switch_state_t MAL_switch_state_1 = SWITCH_OFF;
switch_state_t MAL_switch_state_2 = SWITCH_OFF;
switch_state_t MAT_switch_state_1 = SWITCH_OFF;
switch_state_t MAT_switch_state_2 = SWITCH_OFF;
buzzer_state_t buzzer_state = BUZZER_OFF;
chop_profile_t chop_profile = CHOP_PROFILE_0;

/* USER CODE END PV */

void SystemClock_Config(void);
static void MX_GPIO_Init(void);
static void MX_DMA_Init(void);
static void MX_USART3_UART_Init(void);
static void MX_ADC3_Init(void);
static void MX_I2C1_Init(void);
static void MX_RTC_Init(void);
static void MX_SPI4_Init(void);
static void MX_UART4_Init(void);
static void MX_UART5_Init(void);
static void MX_UART7_Init(void);
static void MX_UART8_Init(void);
static void MX_USB_OTG_FS_USB_Init(void);
void StartModeTransTask(void const *argument);
void StartSystemTask(void const *argument);
void StartCriticalSigTask(void const *argument);
void StartReportTask(void const *argument);
void StartCommsTask(void const *argument);

/* USER CODE BEGIN 0 */

// Redirect printf to uart debug
int _write(int file, char *ptr, int len)
{
  HAL_UART_Transmit(&DEBUG_UART_HANDLE, (uint8_t *)ptr, len, HAL_MAX_DELAY);
  return len;
}

void HAL_ADC_ConvCpltCallback(ADC_HandleTypeDef *hadc)
{

  if (hadc->Instance == ADC3)
  {
    ADC_ConvCplt = 1;
    HAL_ADC_Start_DMA(&ADC_HANDLE, (uint32_t *)adc_results_dma, adcChannelCount);
  }
}

void HAL_GPIO_EXTI_Callback(uint16_t GPIO_PIN)
{
  static uint32_t previousMillis = 0;
  uint32_t currentMillis;

  if (GPIO_PIN == CHOP_SEL_Pin)
  {
    if (salt_mode == MODO_LIMITADO)
    {
      currentMillis = HAL_GetTick();
      if (currentMillis - previousMillis > BTN_DEBOUNCE_MS)
      {
        if (chop_profile == CHOP_PROFILE_4)
        {
          chop_profile = CHOP_PROFILE_0;
        }
        else
        {
          chop_profile++;
        }
        sprintf(local_log_buffer, "CHOP_PROFILE_%d", chop_profile + 1);
        Log_Event(local_log_buffer);
        previousMillis = currentMillis;
      }
    }
  }
}

/* USER CODE END 0 */

/**
 * @brief  The application entry point.
 * @retval int
 */
int main(void)
{
  /* MCU Configuration--------------------------------------------------------*/

  /* Reset of all peripherals, Initializes the Flash interface and the Systick. */
  HAL_Init();

  /* Configure the system clock */
  SystemClock_Config();

  /* Initialize all configured peripherals */
  MX_GPIO_Init();
  MX_DMA_Init();
  MX_USART3_UART_Init();
  MX_ADC3_Init();
  MX_I2C1_Init();
  MX_RTC_Init();
  MX_SPI4_Init();
  MX_UART4_Init();
  MX_UART5_Init();
  MX_UART7_Init();
  MX_UART8_Init();
  MX_USB_OTG_FS_USB_Init();
  MX_FATFS_Init();
  /* USER CODE BEGIN 2 */

  // Set power OK
  WriteCheck_RelayState(REG_POWER_OK_C_GPIO_Port, REG_POWER_OK_C_Pin, RELAY_ENERGIZED,
                        REG_POWER_OK_M_GPIO_Port, REG_POWER_OK_M_Pin);

  mount_filesystem(&fs);
  Log_Event("SD_START_OK");
  Log_Event("POWER_OK");

  Init_Communications();

  // Start first ADC conversion
  HAL_ADC_Start_DMA(&ADC_HANDLE, (uint32_t *)adc_results_dma, adcChannelCount);

  I2C_Reset(&hi2c1);
  HAL_I2C_GetState(&I2C_HANDLE);
  LedDriver_Init(&I2C_HANDLE);

  Led_Init();

  /* USER CODE END 2 */

  /* USER CODE BEGIN RTOS_MUTEX */
  /* add mutexes, ... */
  /* USER CODE END RTOS_MUTEX */

  /* Create the semaphores(s) */
  /* definition and creation of commsSem */
  osSemaphoreDef(commsSem);
  commsSemHandle = osSemaphoreCreate(osSemaphore(commsSem), 1);

  /* USER CODE BEGIN RTOS_TIMERS */
  /* start timers, add new ones, ... */
  /* USER CODE END RTOS_TIMERS */

  /* USER CODE BEGIN RTOS_QUEUES */
  /* add queues, ... */
  /* USER CODE END RTOS_QUEUES */

  /* Create the thread(s) */
  /* definition and creation of modeTransTask */
  osThreadDef(modeTransTask, StartModeTransTask, osPriorityNormal, 0, 512);
  modeTransTaskHandle = osThreadCreate(osThread(modeTransTask), NULL);

  /* definition and creation of systemTask */
  osThreadDef(systemTask, StartSystemTask, osPriorityNormal, 0, 1024);
  systemTaskHandle = osThreadCreate(osThread(systemTask), NULL);

  /* definition and creation of criticalSigTask */
  osThreadDef(criticalSigTask, StartCriticalSigTask, osPriorityNormal, 0, 512);
  criticalSigTaskHandle = osThreadCreate(osThread(criticalSigTask), NULL);

  /* definition and creation of reportTask */
  osThreadDef(reportTask, StartReportTask, osPriorityLow, 0, 256);
  reportTaskHandle = osThreadCreate(osThread(reportTask), NULL);

  /* definition and creation of commsTask */
  osThreadDef(commsTask, StartCommsTask, osPriorityHigh, 0, 1024);
  commsTaskHandle = osThreadCreate(osThread(commsTask), NULL);

  /* USER CODE BEGIN RTOS_THREADS */
  /* add threads, ... */
  /* USER CODE END RTOS_THREADS */

  /* Start scheduler */
  osKernelStart();

  /* We should never get here as control is now taken by the scheduler */
  /* Infinite loop */
  /* USER CODE BEGIN WHILE */
  while (1)
  {
    /* USER CODE END WHILE */

    /* USER CODE BEGIN 3 */
  }
  /* USER CODE END 3 */
}

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
/* USER CODE BEGIN Header_StartModeTransTask */
/**
 * @brief  Function implementing the modeTransTask thread.
 * @param  argument: Not used
 * @retval None
 */
/* USER CODE END Header_StartModeTransTask */
void StartModeTransTask(void const *argument)
{
  /* USER CODE BEGIN 5 */
  /* Infinite loop */
  for (;;)
  {

    Handle_SaltMode_Transition();

    osDelay(SYSTEM_TASK_PERIOD_MS + (rand() % 50));
    osThreadYield();
  }
  /* USER CODE END 5 */
}

/* USER CODE BEGIN Header_StartSystemTask */
/**
 * @brief Function implementing the systemTask thread.
 * @param argument: Not used
 * @retval None
 */
/* USER CODE END Header_StartSystemTask */
void StartSystemTask(void const *argument)
{
  /* USER CODE BEGIN StartSystemTask */
  /* Infinite loop */
  for (;;)
  {
    Read_SystemStatus();
    Display_SystemStatus();

    osDelay(SYSTEM_TASK_PERIOD_MS + (rand() % 50));
    osThreadYield();
  }
  /* USER CODE END StartSystemTask */
}

/* USER CODE BEGIN Header_StartCriticalSigTask */
/**
 * @brief Function implementing the criticalSigTask thread.
 * @param argument: Not used
 * @retval None
 */
/* USER CODE END Header_StartCriticalSigTask */
void StartCriticalSigTask(void const *argument)
{
  /* USER CODE BEGIN StartCriticalSigTask */
  /* Infinite loop */
  for (;;)
  {

    Set_CriticalSignals_State();
    Control_CriticalSignals();

    osDelay(SYSTEM_TASK_PERIOD_MS + (rand() % 50));
    osThreadYield();
  }
  /* USER CODE END StartCriticalSigTask */
}

/* USER CODE BEGIN Header_StartReportTask */
/**
 * @brief Function implementing the reportTask thread.
 * @param argument: Not used
 * @retval None
 */
/* USER CODE END Header_StartReportTask */
void StartReportTask(void const *argument)
{
  /* USER CODE BEGIN StartReportTask */
  /* Infinite loop */
  for (;;)
  {
    Report_SystemStatus();

    osDelay(report_status_period_s * 1000 + (rand() % 50));
    osThreadYield();
  }
  /* USER CODE END StartReportTask */
}

/* USER CODE BEGIN Header_StartCommsTask */
/**
 * @brief Function implementing the commsTask thread.
 * @param argument: Not used
 * @retval None
 */
/* USER CODE END Header_StartCommsTask */
void StartCommsTask(void const *argument)
{
  /* USER CODE BEGIN StartCommsTask */
  /* Infinite loop */
  for (;;)
  {
    if (xSemaphoreTake(commsSemHandle, portMAX_DELAY) == pdTRUE)
    {
      switch (commToProcess)
      {
      case GPS_COMM:
        Process_GPSline();
        break;

      case WIFI_COMM:
        Process_WIFIline();
        break;

      case RS485_1_COMM:
        Process_RS485_1_line();
        break;

      case RS485_2_COMM:
        Process_RS485_2_line();
        break;

      case LOCAL_SERIAL_COMM:
        Process_LocalSerialLine();
        break;

      default:
        break;
      }
    }
  }
  /* USER CODE END StartCommsTask */
}

/**
 * @brief  Period elapsed callback in non blocking mode
 * @note   This function is called  when TIM1 interrupt took place, inside
 * HAL_TIM_IRQHandler(). It makes a direct call to HAL_IncTick() to increment
 * a global variable "uwTick" used as application time base.
 * @param  htim : TIM handle
 * @retval None
 */
void HAL_TIM_PeriodElapsedCallback(TIM_HandleTypeDef *htim)
{
  if (htim->Instance == TIM1)
  {
    HAL_IncTick();
  }
}

/**
 * @brief  This function is executed in case of error occurrence.
 * @retval None
 */
void Error_Handler(void)
{
  /* USER CODE BEGIN Error_Handler_Debug */
  /* User can add his own implementation to report the HAL error return state */
  __disable_irq();
  while (1)
  {
  }
  /* USER CODE END Error_Handler_Debug */
}

#ifdef USE_FULL_ASSERT
/**
 * @brief  Reports the name of the source file and the source line number
 *         where the assert_param error has occurred.
 * @param  file: pointer to the source file name
 * @param  line: assert_param error line source number
 * @retval None
 */
void assert_failed(uint8_t *file, uint32_t line)
{
  /* USER CODE BEGIN 6 */
  /* User can add his own implementation to report the file name and line number,
     ex: printf("Wrong parameters value: file %s on line %d\r\n", file, line) */
  /* USER CODE END 6 */
}
#endif /* USE_FULL_ASSERT */

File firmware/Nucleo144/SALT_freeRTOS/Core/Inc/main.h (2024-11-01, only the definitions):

#define SIS_2_CT_BP_C_Pin GPIO_PIN_2
#define SIS_2_CT_BP_C_GPIO_Port GPIOE
#define SIS_2_CT_BP_M_Pin GPIO_PIN_3
#define SIS_2_CT_BP_M_GPIO_Port GPIOE
#define SIS_3_CT_BP_C_Pin GPIO_PIN_4
#define SIS_3_CT_BP_C_GPIO_Port GPIOE
#define SIS_3_FE_BP_M_Pin GPIO_PIN_5
#define SIS_3_FE_BP_M_GPIO_Port GPIOE
#define RS485_2_DIR_Pin GPIO_PIN_6
#define RS485_2_DIR_GPIO_Port GPIOE
#define USER_Btn_Pin GPIO_PIN_13
#define USER_Btn_GPIO_Port GPIOC
#define SIS_4_CT_BP_M_Pin GPIO_PIN_0
#define SIS_4_CT_BP_M_GPIO_Port GPIOF
#define SIS_4_FE_BP_M_Pin GPIO_PIN_1
#define SIS_4_FE_BP_M_GPIO_Port GPIOF
#define SIS_3_CT_BP_M_Pin GPIO_PIN_2
#define SIS_3_CT_BP_M_GPIO_Port GPIOF
#define MCO_Pin GPIO_PIN_0
#define MCO_GPIO_Port GPIOH
#define RMII_MDC_Pin GPIO_PIN_1
#define RMII_MDC_GPIO_Port GPIOC
#define GPS_PW_ON_Pin GPIO_PIN_0
#define GPS_PW_ON_GPIO_Port GPIOA
#define RMII_REF_CLK_Pin GPIO_PIN_1
#define RMII_REF_CLK_GPIO_Port GPIOA
#define RMII_MDIO_Pin GPIO_PIN_2
#define RMII_MDIO_GPIO_Port GPIOA
#define RS485_1_DIR_Pin GPIO_PIN_4
#define RS485_1_DIR_GPIO_Port GPIOA
#define BUZZER_C_Pin GPIO_PIN_5
#define BUZZER_C_GPIO_Port GPIOA
#define CHOP_SEL_Pin GPIO_PIN_6
#define CHOP_SEL_GPIO_Port GPIOA
#define CHOP_SEL_EXTI_IRQn EXTI9_5_IRQn
#define RMII_CRS_DV_Pin GPIO_PIN_7
#define RMII_CRS_DV_GPIO_Port GPIOA
#define RMII_RXD0_Pin GPIO_PIN_4
#define RMII_RXD0_GPIO_Port GPIOC
#define RMII_RXD1_Pin GPIO_PIN_5
#define RMII_RXD1_GPIO_Port GPIOC
#define LD1_Pin GPIO_PIN_0
#define LD1_GPIO_Port GPIOB
#define CT_C_Pin GPIO_PIN_11
#define CT_C_GPIO_Port GPIOF
#define CT_EN_1_M_Pin GPIO_PIN_12
#define CT_EN_1_M_GPIO_Port GPIOF
#define CT_M_Pin GPIO_PIN_13
#define CT_M_GPIO_Port GPIOF
#define ON_SW_MAL_1_Pin GPIO_PIN_14
#define ON_SW_MAL_1_GPIO_Port GPIOF
#define CT_EN_2_M_Pin GPIO_PIN_15
#define CT_EN_2_M_GPIO_Port GPIOF
#define SIS_5_CT_BP_C_Pin GPIO_PIN_0
#define SIS_5_CT_BP_C_GPIO_Port GPIOG
#define SIS_5_FE_BP_C_Pin GPIO_PIN_1
#define SIS_5_FE_BP_C_GPIO_Port GPIOG
#define REG_2_C_Pin GPIO_PIN_7
#define REG_2_C_GPIO_Port GPIOE
#define ZONA_C_Pin GPIO_PIN_8
#define ZONA_C_GPIO_Port GPIOE
#define ON_SW_MAL_2_Pin GPIO_PIN_9
#define ON_SW_MAL_2_GPIO_Port GPIOE
#define FE_M_Pin GPIO_PIN_10
#define FE_M_GPIO_Port GPIOE
#define SPI4_CS_Pin GPIO_PIN_11
#define SPI4_CS_GPIO_Port GPIOE
#define SD_CD_Pin GPIO_PIN_15
#define SD_CD_GPIO_Port GPIOE
#define ON_SW_MAT_2_Pin GPIO_PIN_11
#define ON_SW_MAT_2_GPIO_Port GPIOB
#define ON_SW_MAT_1_Pin GPIO_PIN_12
#define ON_SW_MAT_1_GPIO_Port GPIOB
#define RMII_TXD1_Pin GPIO_PIN_13
#define RMII_TXD1_GPIO_Port GPIOB
#define LD3_Pin GPIO_PIN_14
#define LD3_GPIO_Port GPIOB
#define STLK_RX_Pin GPIO_PIN_8
#define STLK_RX_GPIO_Port GPIOD
#define STLK_TX_Pin GPIO_PIN_9
#define STLK_TX_GPIO_Port GPIOD
#define FE_C_Pin GPIO_PIN_10
#define FE_C_GPIO_Port GPIOD
#define REG_1_C_Pin GPIO_PIN_11
#define REG_1_C_GPIO_Port GPIOD
#define REG_3_C_Pin GPIO_PIN_12
#define REG_3_C_GPIO_Port GPIOD
#define REG_4_C_Pin GPIO_PIN_13
#define REG_4_C_GPIO_Port GPIOD
#define REG_1_M_Pin GPIO_PIN_14
#define REG_1_M_GPIO_Port GPIOD
#define FE_EN_2_M_Pin GPIO_PIN_15
#define FE_EN_2_M_GPIO_Port GPIOD
#define SIS_2_FE_BP_M_Pin GPIO_PIN_2
#define SIS_2_FE_BP_M_GPIO_Port GPIOG
#define SIS_1_CT_BP_C_Pin GPIO_PIN_3
#define SIS_1_CT_BP_C_GPIO_Port GPIOG
#define FE_EN_1_M_Pin GPIO_PIN_4
#define FE_EN_1_M_GPIO_Port GPIOG
#define FE_DES_2_Pin GPIO_PIN_5
#define FE_DES_2_GPIO_Port GPIOG
#define FE_DES_1_Pin GPIO_PIN_6
#define FE_DES_1_GPIO_Port GPIOG
#define USB_OverCurrent_Pin GPIO_PIN_7
#define USB_OverCurrent_GPIO_Port GPIOG
#define CT_DES_1_Pin GPIO_PIN_8
#define CT_DES_1_GPIO_Port GPIOG
#define USB_SOF_Pin GPIO_PIN_8
#define USB_SOF_GPIO_Port GPIOA
#define USB_VBUS_Pin GPIO_PIN_9
#define USB_VBUS_GPIO_Port GPIOA
#define USB_ID_Pin GPIO_PIN_10
#define USB_ID_GPIO_Port GPIOA
#define USB_DM_Pin GPIO_PIN_11
#define USB_DM_GPIO_Port GPIOA
#define USB_DP_Pin GPIO_PIN_12
#define USB_DP_GPIO_Port GPIOA
#define TMS_Pin GPIO_PIN_13
#define TMS_GPIO_Port GPIOA
#define TCK_Pin GPIO_PIN_14
#define TCK_GPIO_Port GPIOA
#define ESP_EN_Pin GPIO_PIN_15
#define ESP_EN_GPIO_Port GPIOA
#define SIS_4_CT_BP_C_Pin GPIO_PIN_0
#define SIS_4_CT_BP_C_GPIO_Port GPIOD
#define SIS_4_FE_BP_C_Pin GPIO_PIN_1
#define SIS_4_FE_BP_C_GPIO_Port GPIOD
#define SIS_1_FE_BP_M_Pin GPIO_PIN_3
#define SIS_1_FE_BP_M_GPIO_Port GPIOD
#define SIS_1_CT_BP_M_Pin GPIO_PIN_4
#define SIS_1_CT_BP_M_GPIO_Port GPIOD
#define SIS_1_FE_BP_C_Pin GPIO_PIN_5
#define SIS_1_FE_BP_C_GPIO_Port GPIOD
#define SIS_2_FE_BP_C_Pin GPIO_PIN_6
#define SIS_2_FE_BP_C_GPIO_Port GPIOD
#define SIS_3_FE_BP_C_Pin GPIO_PIN_7
#define SIS_3_FE_BP_C_GPIO_Port GPIOD
#define SIS_5_FE_BP_M_Pin GPIO_PIN_9
#define SIS_5_FE_BP_M_GPIO_Port GPIOG
#define REG_4_M_Pin GPIO_PIN_10
#define REG_4_M_GPIO_Port GPIOG
#define RMII_TX_EN_Pin GPIO_PIN_11
#define RMII_TX_EN_GPIO_Port GPIOG
#define ZONA_M_Pin GPIO_PIN_12
#define ZONA_M_GPIO_Port GPIOG
#define RMII_TXD0_Pin GPIO_PIN_13
#define RMII_TXD0_GPIO_Port GPIOG
#define CT_DES_2_Pin GPIO_PIN_14
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

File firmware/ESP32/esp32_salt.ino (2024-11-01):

#include <WiFi.h>
#include <WiFiUdp.h>
#include <NTPClient.h>
#include <time.h>
#include <MQTT.h>

const char* wifi_ssid1 = "wifi_ssid1";
const char* wifi_psw1 = "XXXXXXXXX";

const char* wifi_ssid2 = "wifi_ssid2";
const char* wifi_psw2 = "XXXXXXXXX";

char * active_ssid;

const char* mqtt_server = "salt-ma.cloud.shiftr.io";
const char* mqtt_publish_name = "SALT";

const char* mqtt_user_name = "salt-ma";
const char* mqtt_user_token = "1f05DXKCezK1hnck";

const char* mqtt_suscribe_topic         = "salt_remote_command";
const char* mqtt_publish_log_topic      = "salt_remote_log";
const char* mqtt_publish_ack_topic      = "salt_remote_ack";
const char* mqtt_publish_status_topic   = "salt_status";




WiFiClient wifi_client;
MQTTClient mqtt_client;

WiFiUDP ntpUDP;
NTPClient timeClient(ntpUDP, "pool.ntp.org", -3 * 3600, 60000);  // UTC-3 offset

const int BUFFER_SIZE = 256;
const long DATETIME_TX_INTERVAL = 10000;  // 10s
const long WIFI_CONNECTION_TIME = 5000;   // 5s

char dateTime[BUFFER_SIZE];
char uartRxBuffer[BUFFER_SIZE];
int uartRxBufferIndex = 0;
unsigned long lastDatetimeTxMillis = 0;



void wifi_connect() {
  while (WiFi.status() != WL_CONNECTED) {
    if (network_connect(wifi_ssid1, wifi_psw1)){
      active_ssid = (char*) wifi_ssid1;
      break;
    }
    if (network_connect(wifi_ssid2, wifi_psw2)){
      active_ssid = (char*) wifi_ssid2;
      break;
    }
  }
}

bool network_connect(const char* wifi_ssid, const char* wifi_psw) {
  unsigned long currentMillis;
  unsigned long wifiConnectionMillis = millis();


  WiFi.begin(wifi_ssid, wifi_psw);
  Serial.printf("Connecting to WiFi %s...", wifi_ssid);
  while (WiFi.status() != WL_CONNECTED) {
    currentMillis = millis();
    if (currentMillis - wifiConnectionMillis > WIFI_CONNECTION_TIME){
      Serial.println("not connected");
      return false;
    }
    delay(500);
    Serial.print(".");
  }

  Serial.println("connected!");
  return true;
}

void mqtt_connect() {
  char mqttConnectBuf[BUFFER_SIZE];
  
  while (WiFi.status() != WL_CONNECTED) {
      wifi_connect();
  }

  Serial.printf("Connecting to MQTT server %s...", mqtt_server);
  while (!mqtt_client.connect(mqtt_publish_name, mqtt_user_name, mqtt_user_token)) {  
    Serial.print(".");
    delay(1000);
  }
  Serial.println("connected!");

  mqtt_client.subscribe(mqtt_suscribe_topic);
  Serial.printf("Suscribed to %s topic\r\n", mqtt_suscribe_topic);
  
  setDateTime();

  sprintf(mqttConnectBuf, "%s MQTT_CONNECTED_W_SSID: %s", dateTime, active_ssid);
  mqtt_client.publish(mqtt_publish_log_topic, mqttConnectBuf);
  Serial.println(mqttConnectBuf);
}

void messageReceived(String &topic, String &payload) {
  Serial2.println(payload);
  Serial.println(payload);
}

void setDateTime(){
  timeClient.update();

  unsigned long epochTime = timeClient.getEpochTime();
  
  struct tm *ptm = gmtime((time_t *)&epochTime);
  
  
  sprintf(dateTime, "%02d/%02d/%04d %02d:%02d:%02d", 
          ptm->tm_mday, 
          ptm->tm_mon + 1, 
          ptm->tm_year + 1900, 
          ptm->tm_hour, 
          ptm->tm_min, 
          ptm->tm_sec);
  
}

void sendDateTime(){
  char datetimeCommand[BUFFER_SIZE];

  setDateTime();

  sprintf(datetimeCommand, "0|DATETIME:%s",dateTime);
  
  Serial2.println(datetimeCommand);
  Serial.println(datetimeCommand);
}

void setup() {
  Serial.begin(115200);
  Serial2.begin(115200);

  delay(500);
  
  wifi_connect();
  
  delay(200);

  timeClient.begin(); 

  delay(200);

  mqtt_client.begin(mqtt_server, wifi_client);
  mqtt_client.onMessage(messageReceived);
  mqtt_connect();
}

void loop() {
  mqtt_client.loop();

  if (!mqtt_client.connected()) {
    Serial.println("MQQT disconnected");
     mqtt_connect();
  }

  unsigned long currentMillis = millis();
  if (currentMillis - lastDatetimeTxMillis > DATETIME_TX_INTERVAL) {
    lastDatetimeTxMillis = currentMillis;
    sendDateTime();
  }


  while (Serial2.available() > 0) {
    char incomingByte = Serial2.read();

    if (incomingByte == '\n') {
      uartRxBuffer[uartRxBufferIndex] = '\0';
      if (strncmp(uartRxBuffer, "ACK", 3) == 0) {
        mqtt_client.publish(mqtt_publish_ack_topic, uartRxBuffer);
      } else if (strncmp(uartRxBuffer, "STATUS", 6) == 0) {
        mqtt_client.publish(mqtt_publish_status_topic, uartRxBuffer);
      }
      else{
        mqtt_client.publish(mqtt_publish_log_topic, uartRxBuffer);
      }      
      uartRxBufferIndex = 0;
    } else {
      if (uartRxBufferIndex < BUFFER_SIZE - 1) {
        uartRxBuffer[uartRxBufferIndex++] = incomingByte;
      } else {
        uartRxBufferIndex = 0;
      }
    }
  }
  
}

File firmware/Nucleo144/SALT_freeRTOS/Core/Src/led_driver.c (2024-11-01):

/*
 * led_driver.c
 *
 *  Created on: Jul 28, 2024
 *      Author: manus
 */

#include "led_driver.h"

void I2C_Reset(I2C_HandleTypeDef *hi2c)
{
    __HAL_RCC_I2C1_FORCE_RESET();
    //HAL_Delay(1); // Small delay
    __HAL_RCC_I2C1_RELEASE_RESET();

    // Reinitialize the I2C peripheral
    HAL_I2C_Init(hi2c);
}

HAL_StatusTypeDef LedDriver_WriteReg(uint8_t reg_address, uint8_t reg_value, I2C_HandleTypeDef *hi2c)
{
    uint8_t data[2] = {reg_address, reg_value};
    return HAL_I2C_Master_Transmit(hi2c, AS1115_I2C_ADDRESS << 1, data, 2, HAL_MAX_DELAY);
}

HAL_StatusTypeDef LedDriver_Init(I2C_HandleTypeDef *hi2c)
{
    LedDriver_WriteReg(SHUTDOWN_REG_ADDR, NORMAL_OPERATION_MODE, hi2c);
    LedDriver_WriteReg(SCAN_LIMIT_REG_ADDR, DISPLAY_7_DIGITS, hi2c);
    return LedDriver_WriteReg(GLOBAL_INTENSITY_REG_ADDR, MID_INTENSITY, hi2c);
}

uint8_t digitTo7Segment(uint8_t digit)
{
    static const uint8_t segmentMap[11] = {
        0b01111110, // 0
        0b00110000, // 1
        0b01101101, // 2
        0b01111001, // 3
        0b00110011, // 4
        0b01011011, // 5
        0b01011111, // 6
        0b01110000, // 7
        0b01111111, // 8
        0b01111011, // 9
        0b00000001  // -
    };

    if (digit > 10)
    {
        return 0b00000000; // Return no digit
    }

    return segmentMap[digit];
}

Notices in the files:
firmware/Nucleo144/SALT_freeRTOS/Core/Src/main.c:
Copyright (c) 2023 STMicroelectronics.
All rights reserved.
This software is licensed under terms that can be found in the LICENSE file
